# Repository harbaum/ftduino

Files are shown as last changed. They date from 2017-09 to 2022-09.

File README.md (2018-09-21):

# [ftDuino](http://ftduino.de): der [Arduino](http://arduino.cc) für [fischertechnik](http://fischertechnik.de)

<p align="center">
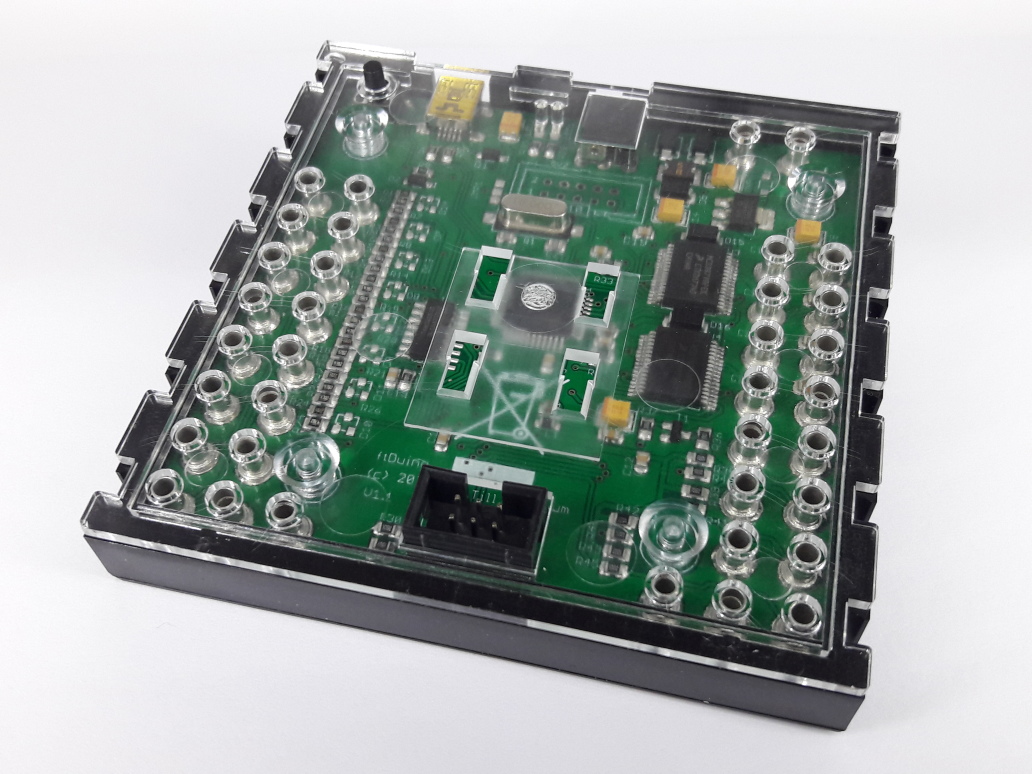
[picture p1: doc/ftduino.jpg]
  
</p>

Der ftDuino schlägt die Brücke zwischen den populären
[Arduino](http://arduino.cc)-Controllern und dem leistungsfähigen
[fischertechnik](http://fischertechnik.de)-Konstruktionsspielzeug.

Mehr Infos auf der [ftDuino-Homepage](http://ftduino.de).

<p align="center">
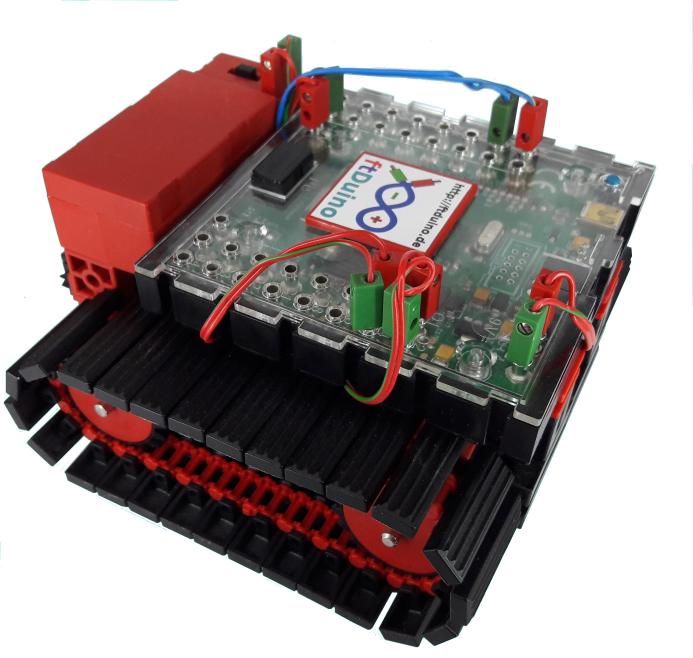
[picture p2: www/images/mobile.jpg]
  
</p>

The ftDuino bridges the gap between the popular [Arduino](http://arduino.cc)
controllers and the powerful [fischertechnik](http://fischertechnik.de)
construction toy.

More infos on the [ftDuino homepage](http://ftduino.de/en).

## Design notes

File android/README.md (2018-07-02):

ftDuino for Android
-------------------

The ftDuino can be connected directly to most android devices like
smartphones or tablets using a so-called USB on-the-go (USB OTG) cable.

The ftDuino setup for the Arduino IDE contains a demo sketch under
FtduinoSimple/USB/AndroidDemo which can be used in combination with
the ftDuinoDemo app.

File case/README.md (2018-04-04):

# ftDuino case designs

These are mesh files for the ftDuino 1.1 case. At least `bottom.stl` and
one of `top_with_isp.stl` or `top_without_isp.stl` are needed.

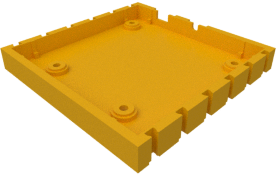
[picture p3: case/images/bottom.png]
bottom case
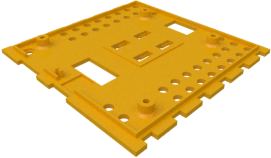
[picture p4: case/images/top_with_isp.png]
top case with ISP connector opening
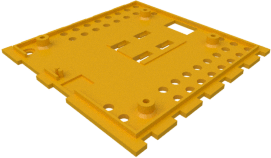
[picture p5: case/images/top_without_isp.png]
top case without ISP connector opening
|  |  |  |
|:---:|:---:|:---:|
| [View `bottom.stl`](bottom.stl) | [View `top_with_isp.stl`](top_with_isp.stl) | [View `top_without_isp.stl`](top_without_isp.stl) |
| [Download `bottom.stl`](bottom.stl?raw=true) | [Download `top_with_isp.stl`](top_with_isp.stl?raw=true) | [Download `top_without_isp.stl`](top_without_isp.stl?raw=true) |

The `top_with_isp.stl` is to be used if the ISP connector is to
be mounted. The `top_without_isp.stl` is for boards without ISP
connector. The ISP connector hole in `top_with_isp.stl` can alternally
be closed with the `isp_cap.stl`.

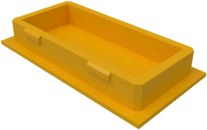
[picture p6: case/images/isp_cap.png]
ISP connector cap
|  |
|:---:|
| [View `isp_cap.stl`](isp_cap.stl) |
| [Download `isp_cap.stl`](isp_cap.stl?raw=true) |

The `i2c_protector.stl` is a small piece that fits into the 6 pin
I²C connector if it's not in use and prevents it from accidentially
being shortened or otherwise damaged.

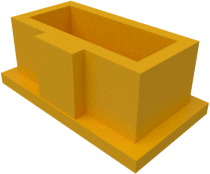
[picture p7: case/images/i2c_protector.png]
I²C protector
|  |
|:---:|
| [View `i2c_protector.stl`](i2c_protector.stl) |
| [Download `i2c_protector.stl`](i2c_protector.stl?raw=true) |

The `reset_button.stl` reset button is required if a 4.3mm tactile
switch is used as a reset button. It's not needed if a 7 or 9mm
version is used.

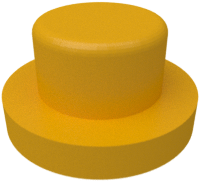
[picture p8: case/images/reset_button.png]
Reset button
|  |
|:---:|
| [View `reset_button.stl`](reset_button.stl) |
| [Download `reset_button.stl`](reset_button.stl?raw=true) |

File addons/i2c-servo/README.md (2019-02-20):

# Mini I²C servo controller

The 30mm version featuring a single I²C port:

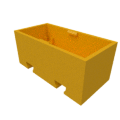
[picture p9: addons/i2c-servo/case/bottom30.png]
bottom case
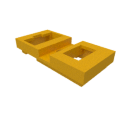
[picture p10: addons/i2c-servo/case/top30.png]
top case
|  |  |
|:---:|:---:|
| [`bottom30.stl`](case/bottom30.stl) | [`top30.stl`](case/top30.stl) |

The 45mm version featuring two I²C ports:

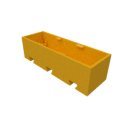
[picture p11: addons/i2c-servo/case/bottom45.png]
bottom case
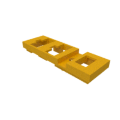
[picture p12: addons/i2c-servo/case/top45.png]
top case
|  |  |
|:---:|:---:|
| [`bottom45.stl`](case/bottom45.stl) | [`top45.stl`](case/top45.stl) |

# I²C-Registers

By default the adapter uses I²C address 0x11 (dec 17).

| Register | Description |
|---|---|
| 0x00/0x01 | Set servo pulse width of output 1 or 2 in 16us steps. E.g. 63 is 1ms (typical min value of a servo) and 125 is 2ms (typical max value of a servo). By default the adapter will not allow values < 53 and values > 125 to protect the servo. Example set PWM1 to 1.5ms: 0x11 0x00 0x5e |
| 0x02/0x03 | Set lower limit for servo 1 or servo 2 in 16us steps. Default value is 63. Values written to registers  0x00/0x01 lower than the limits specified here are mapped to this limit. |
| 0x04/0x05 | Set upper limit for servo 1 or servo 2 in 16us steps. Default value is 125. Values written to registers  0x00/0x01 higher than the limits specified here are mapped to this limit. |
| 0x06/0x07 | Set offset for servo 1 or servo 2. Default value is 0. The offset is added to the PWM value written to registers 0 or 1 _after_ the limit takes place. This is useful to adjust the center position of a servo. |
| 0x08 | Set I²C address. The new address can be any address >= 0x03 and <= 0x77 except 0x3c (which is reserved because the OLED uses it). |
| 0x09 | Writing 0xa5 to this register stores the values from registers 0x02 to 0x08 in eeprom. These settings will then become permanent over power loss and reboot. |
| Read 0x00 | Reading register 0x00 returns the formware version in BCD, e.g. 0x10 for version 1.0 |
| Read 0x01+ | Reading any other register returns 0x5a |

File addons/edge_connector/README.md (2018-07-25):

# Edge connector

The ftDuino case unfortunately does not have ft mounts at
its bottom. This is due to the fact that this would make
moulding much more expensive.

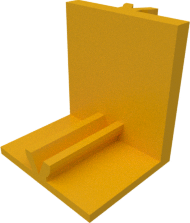
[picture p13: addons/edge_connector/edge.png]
Edge connector
|  |
|:---:|
| [View `edge.stl`](edge.stl) |
| [Download `edge.stl`](edge.stl?raw=true) |

The edge connector was therefore built to allow to get some
sore of bottom connectivity as depicted below.

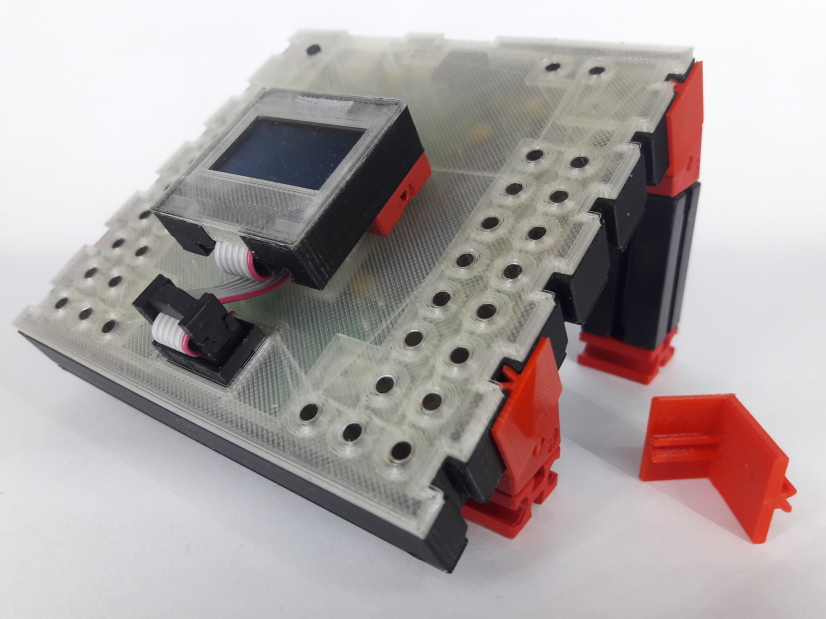
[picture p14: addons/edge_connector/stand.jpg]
A stand using the edge connector


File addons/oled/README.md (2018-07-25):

# ftDuino - OLED addon

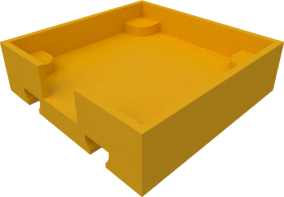
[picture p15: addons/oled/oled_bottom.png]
bottom case
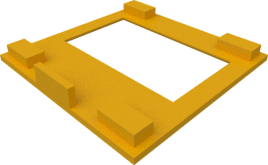
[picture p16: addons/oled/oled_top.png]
top case
|  |  |
|:---:|:---:|
| [View `oled_bottom.stl`](oled_bottom.stl) | [View `oled_top.stl`](oled_top.stl) |
| [Download `oled_bottom.stl`](oled_bottom.stl?raw=true) | [Download `oled_top.stl`](oled_top.stl?raw=true) |

The ftDuinos I²C interface can be used to add a small OLED display
to the ftDuino.

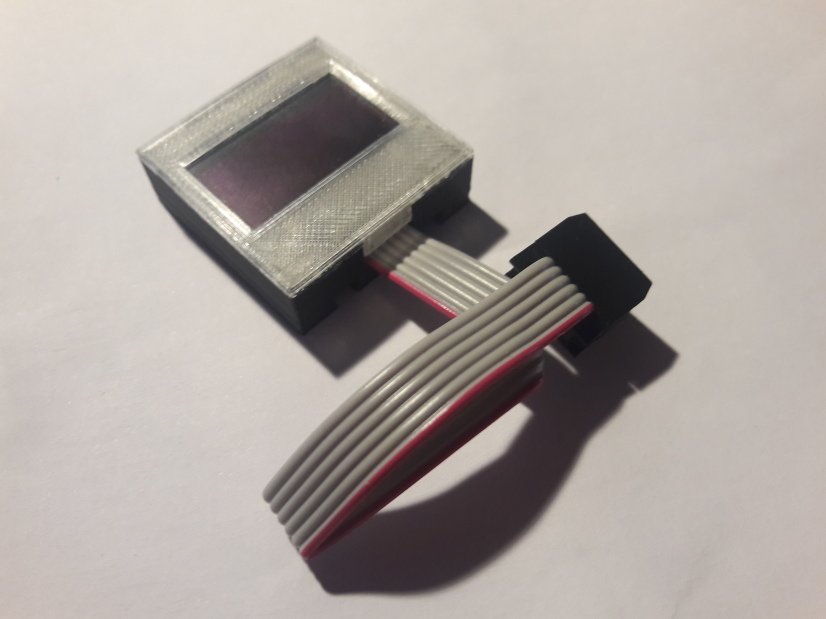
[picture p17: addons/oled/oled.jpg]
The cased OLED display with matching cable for the ftDuino


Here you'll find a set of design files for a fischertechnik compatible
case for a typical 0.96" OLED display,

The wiring compatible with the 6 pin I²C connector of the ftDuino
is rather simple:

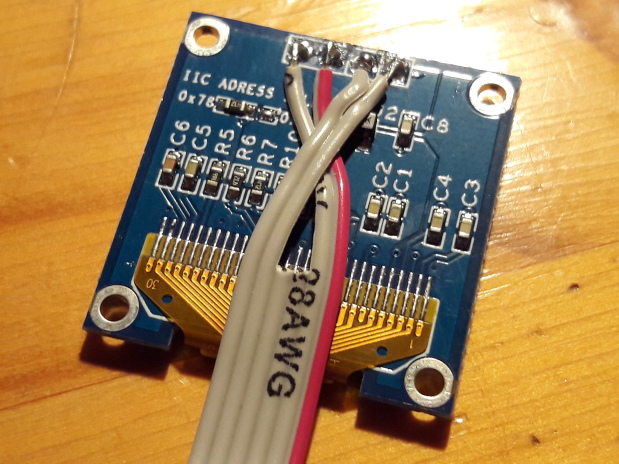
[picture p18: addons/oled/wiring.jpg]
Wiring the ftDuino cable


A matching arduino library can e.g. found in the [Adafruit repository](https://github.com/adafruit/Adafruit_SSD1306).

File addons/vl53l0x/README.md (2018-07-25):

# ftDuino - vl53l0x addon

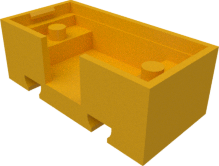
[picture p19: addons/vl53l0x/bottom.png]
bottom case
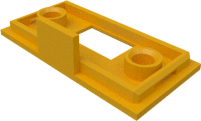
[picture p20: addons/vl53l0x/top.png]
top case
|  |  |
|:---:|:---:|
| [View `bottom.stl`](bottom.stl) | [View `top.stl`](top.stl) |
| [Download `bottom.stl`](bottom.stl?raw=true) | [Download `top.stl`](top.stl?raw=true) |

The vl53l0x is a time of flight (ToF) distance sensor. It can e.g. be
used as a replacement for the fischertechnik ultrasonic distance
sensor.

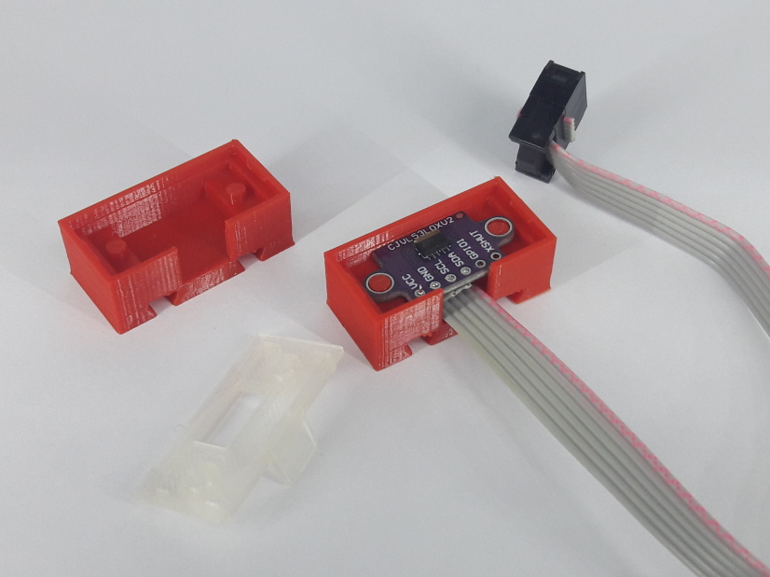
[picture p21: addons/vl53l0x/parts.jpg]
All needed parts


A matching arduino library can e.g. found in the [Adafruit repository](https://github.com/adafruit/Adafruit_VL53L0X).

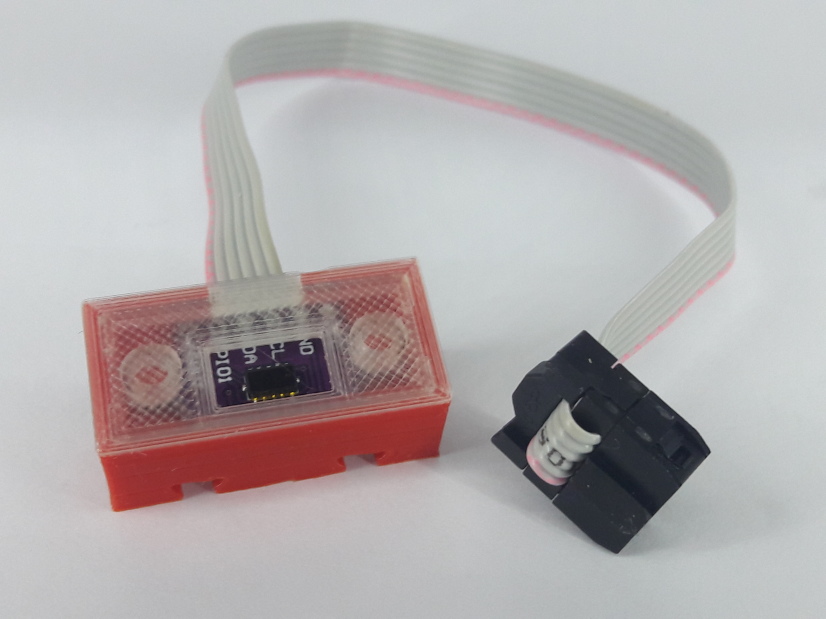
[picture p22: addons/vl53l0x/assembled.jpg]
Assembled sensor


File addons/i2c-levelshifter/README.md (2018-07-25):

# I²C level shifter

This is a case for the I²C level shifter.

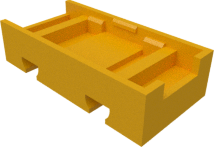
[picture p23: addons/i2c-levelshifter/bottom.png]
bottom case
|  | top case |
|:---:|:---:|
| [View `bottom.stl`](bottom.stl) | [View `top.stl`](top.stl) |
| [Download `bottom.stl`](bottom.stl?raw=true) | [Download `top.stl`](top.stl?raw=true) |

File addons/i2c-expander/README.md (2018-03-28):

# I²C expander

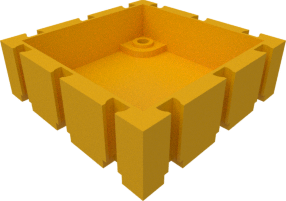
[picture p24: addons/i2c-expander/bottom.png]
bottom case
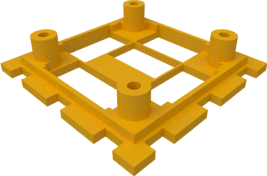
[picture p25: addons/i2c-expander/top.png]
top case
|  |  |
|:---:|:---:|
| [`bottom.stl`](bottom.stl) | [`top.stl`](top.stl) |

The I²C expander expands the single 5V I²C port of a ftDuino or
fischertechnik TX controller by three more ports and contains a level
shifter to bridge to a fischertechnik TXT compatible 3.3V port.

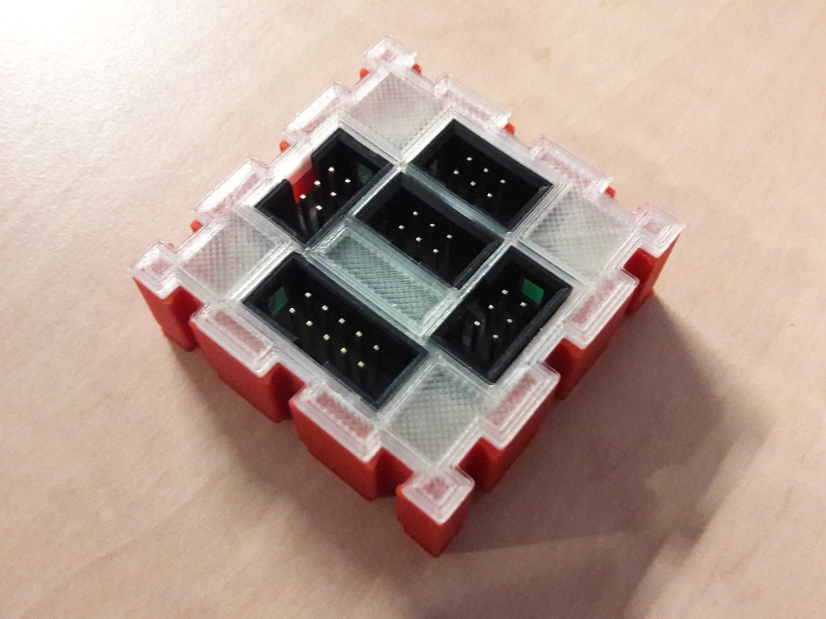
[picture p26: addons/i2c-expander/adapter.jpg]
adapter


This adapter can e.g. be used to connect the ```fischertechnik 
Kombisensor 158402 3-in-1 Orientierungssensor``` ([PDF](https://content.ugfischer.com/cbfiles/fischer/Zulassungen/ft/158402-Kombisensor-Kurzanleitung-BMX055-2017-06-09.pdf)) which is meant to be connected to the TXT and its 3.3V
I²C:

adapter between ftduino and ft sensor

This is how the setup looks right before assembly:

disassembled

## Parts

All parts are available from e.g. [Reichelt](http://www.reichelt.de).

You need:

  - 1x 10 pin header [WSL 10G](https://www.reichelt.de/Pfosten-Wannenstecker/WSL-10G/3/index.html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)
  - 4x 6 pin header [WSL 6G](https://www.reichelt.de/Pfosten-Wannenstecker/WSL-6G/3/index.html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)
  - 2x resistors [22k ohms SMD](https://www.reichelt.de/SMD-0805-von-1-bis-910-kOhm/SMD-0805-22-0K/3/index.html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)
  - 2x N channel MOSFET [BSS 123](https://www.reichelt.de/BS-Transistoren/BSS-123-SMD/3/index.html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)
  - 1x power regulator [TPS 77033 DBVT](https://www.reichelt.de/ICs-TLC-TSA-/TPS-77033-DBVT/3/index.html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)

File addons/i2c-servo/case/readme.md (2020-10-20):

Für die im Handel erhältliche Platinenversion mit durchgeschleiftem I2C-Bus sind die langen ...45-Gehäuse zu verwenden.

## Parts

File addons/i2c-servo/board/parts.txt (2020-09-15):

Part name                Description            Digikey No
------------------------------------------------------------------
IC1                      TS2940CP50             TS2940CP50ROG-ND      
IC2                      Attiny25 SOIC8         ATTINY25-20SSU-ND 
R1                       220 0805               CR0805-JW-221ELFTR-ND, any < 5% 0805 220R resistor
R2,R3                    10k 0805               311-10KARTR-ND, any < 5% 0805 10k resistor
C1,C2                    100nF 0805             399-7367-2-ND, any ceramic 100nF >=10V 0805 will do
LED                      green 0805             475-1410-2-ND, any cheap 0805 led will do
I²C1, I²C2, SERVO        6 pin 2.54mm SMD pin   54202-S0803LF-ND or similar regular 2.54mm 6 pin smd 
I1                       metal sleeve           fischertechnik sleeve as on ftDuino itself

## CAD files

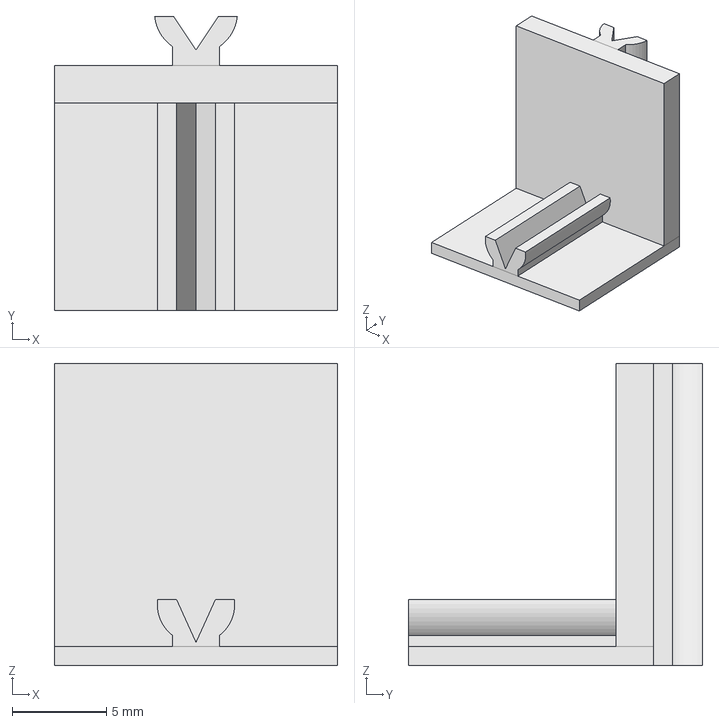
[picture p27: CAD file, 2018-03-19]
addons/edge_connector/edge.fcstd
15.0 x 15.6 x 16.0 mm

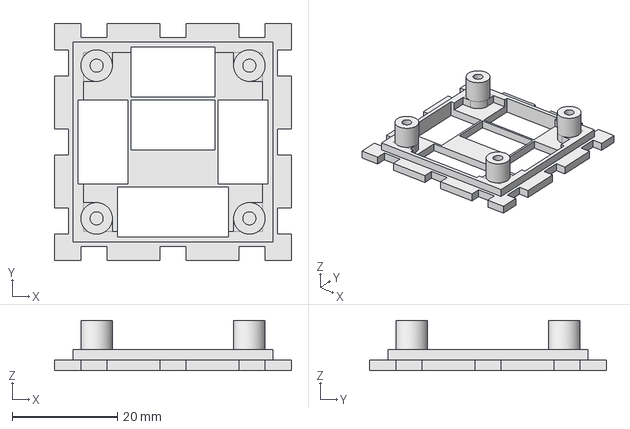
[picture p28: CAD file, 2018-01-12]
addons/i2c-expander/top.fcstd
45.0 x 45.0 x 9.50 mm

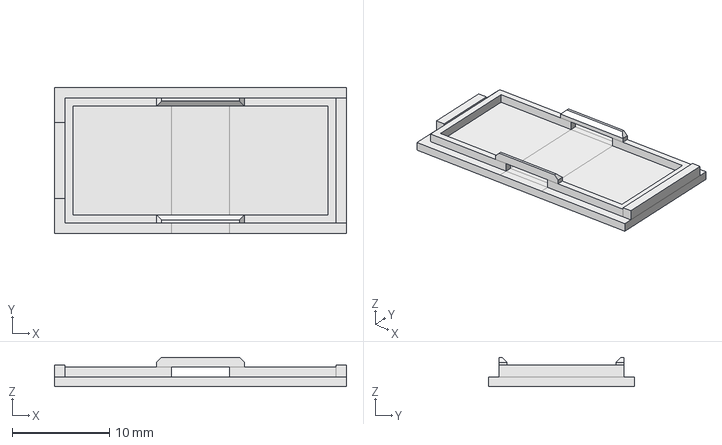
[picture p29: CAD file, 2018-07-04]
addons/i2c-levelshifter/top.fcstd
30.0 x 15.0 x 3.00 mm

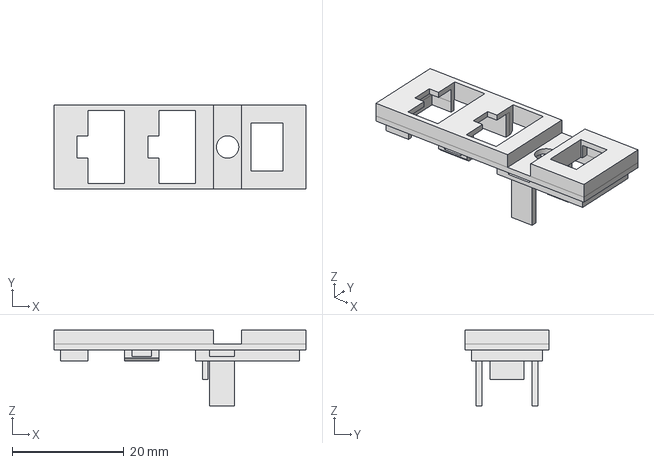
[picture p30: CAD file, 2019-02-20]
addons/i2c-servo/case/top45.fcstd
45.0 x 15.0 x 13.5 mm

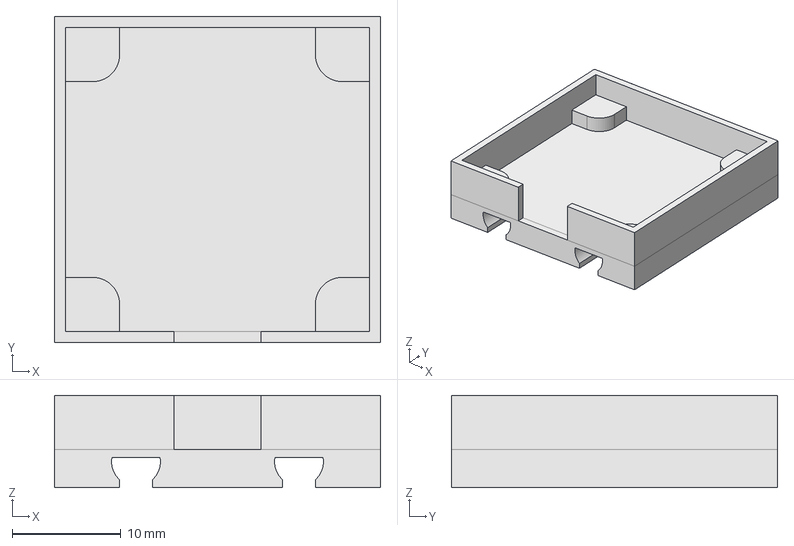
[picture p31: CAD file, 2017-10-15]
addons/oled/oled_bottom.fcstd
30.0 x 30.0 x 8.50 mm

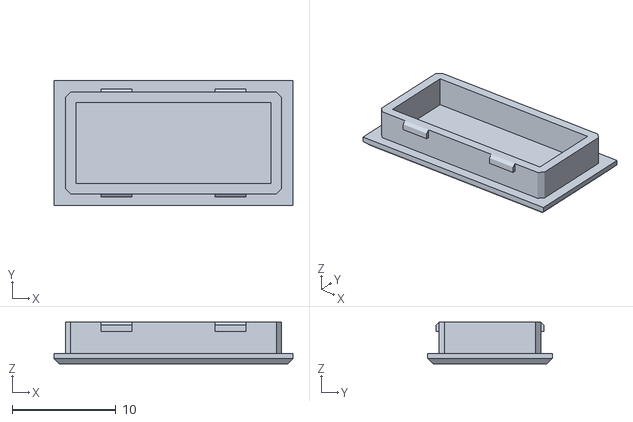
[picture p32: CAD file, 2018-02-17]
case/isp_cap.stl
23.0 x 12.0 x 4.00

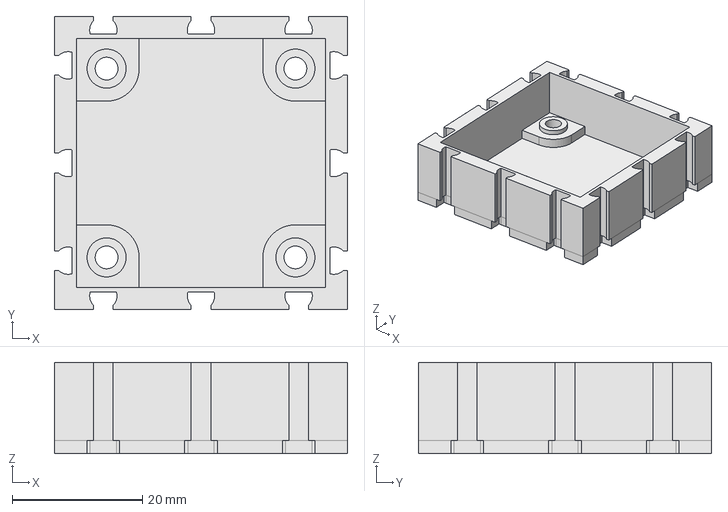
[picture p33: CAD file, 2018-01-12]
addons/i2c-expander/bottom.fcstd
45.0 x 45.0 x 14.0 mm

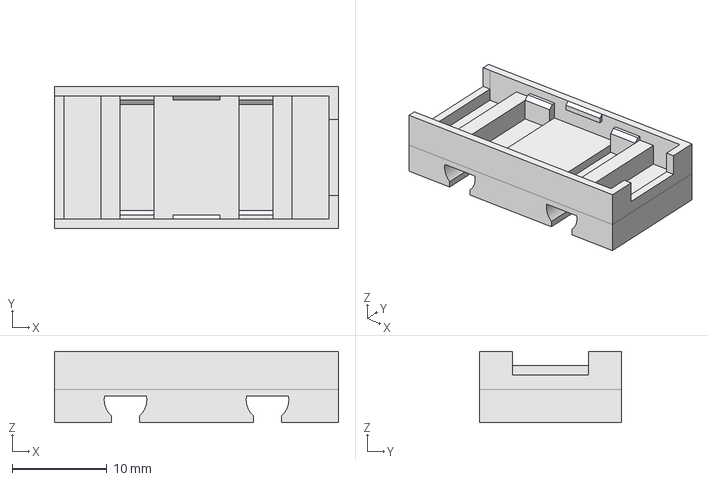
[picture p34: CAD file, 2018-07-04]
addons/i2c-levelshifter/bottom.fcstd
30.0 x 15.0 x 7.50 mm

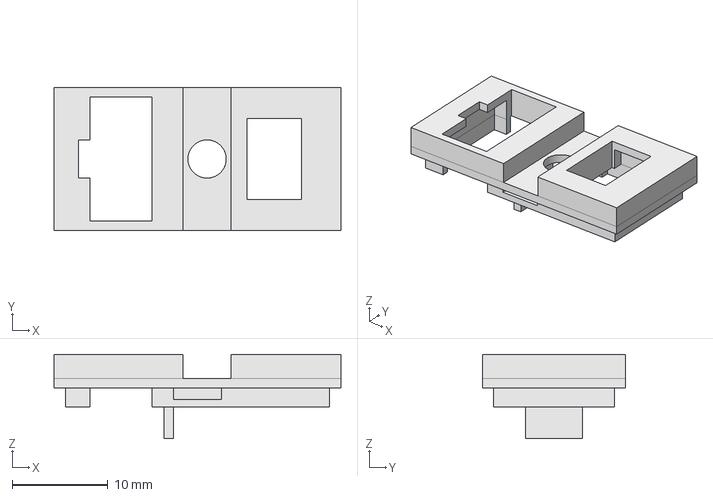
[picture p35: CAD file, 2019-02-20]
addons/i2c-servo/case/top30.fcstd
30.0 x 15.0 x 8.80 mm

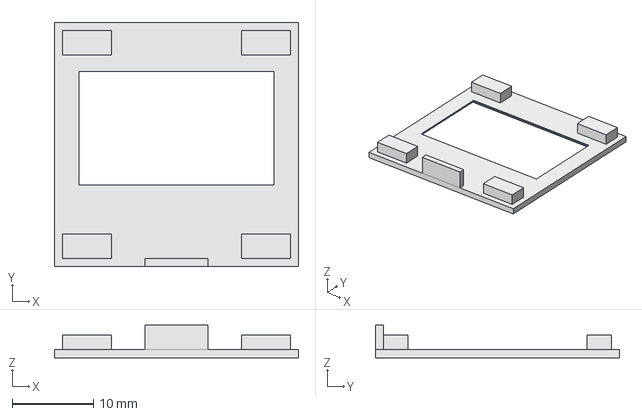
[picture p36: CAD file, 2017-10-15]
addons/oled/oled_top.fcstd
30.0 x 30.0 x 4.00 mm

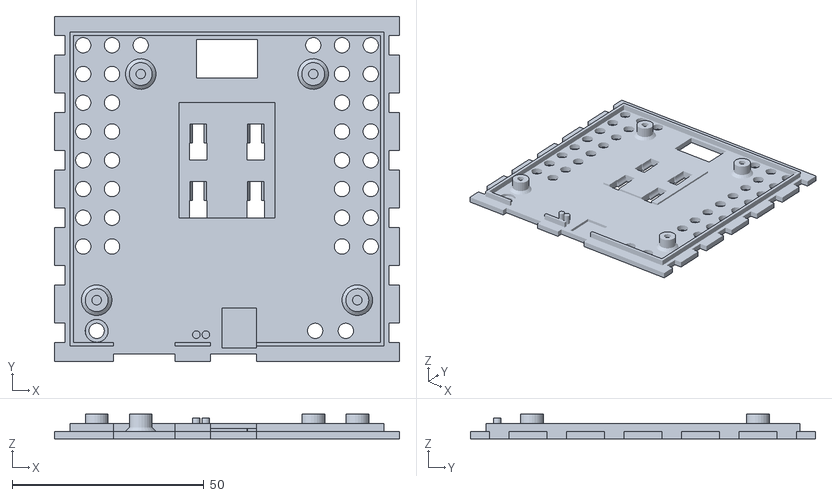
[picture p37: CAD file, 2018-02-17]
case/top_without_isp.stl
90.0 x 90.0 x 6.50

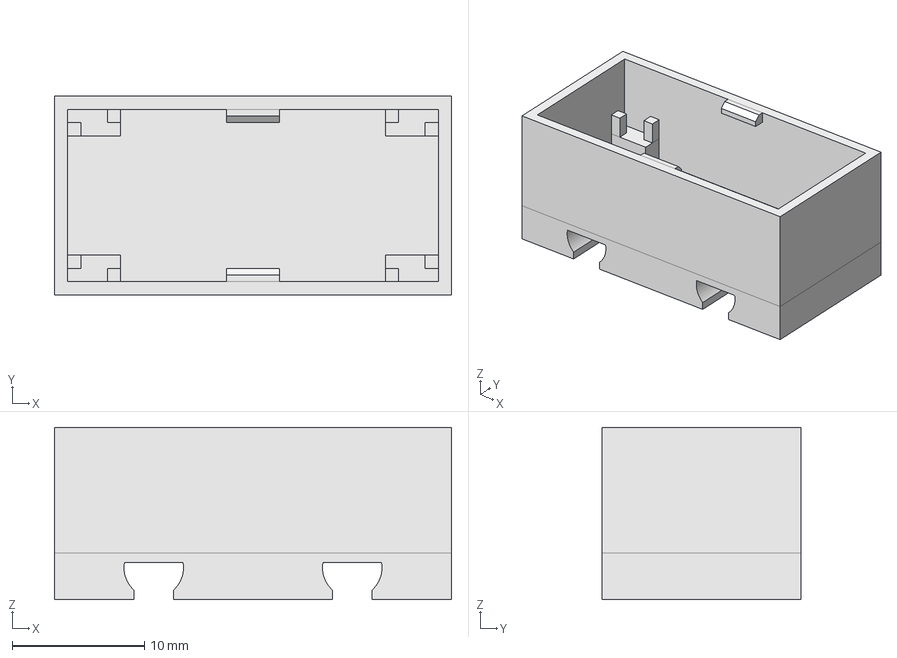
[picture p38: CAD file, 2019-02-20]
addons/i2c-servo/case/bottom30.fcstd
30.0 x 15.0 x 13.0 mm

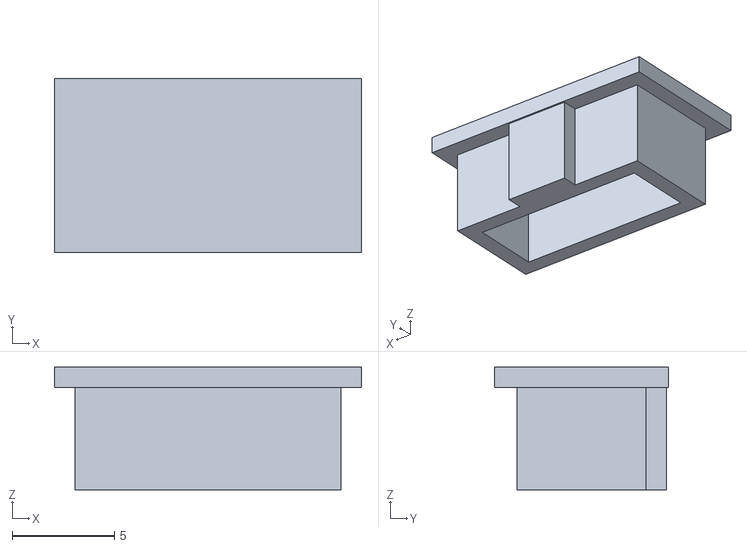
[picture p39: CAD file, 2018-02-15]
case/i2c_protector.stl
15.0 x 8.50 x 6.00

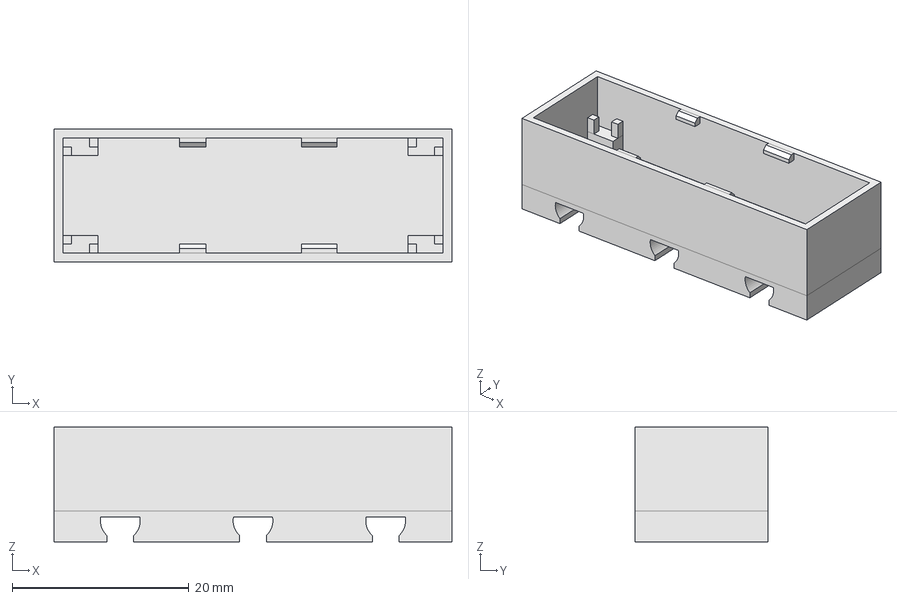
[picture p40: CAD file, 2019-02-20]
addons/i2c-servo/case/bottom45.fcstd
45.0 x 15.0 x 13.0 mm

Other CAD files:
case/reset_button.stl
case/bottom.stl
case/top_with_isp.stl
addons/vl53l0x/bottom.fcstd
addons/edge_connector/edge.stl
addons/i2c-expander/bottom.stl
addons/i2c-expander/top.stl
addons/i2c-levelshifter/bottom.stl
addons/i2c-levelshifter/top.stl
addons/i2c-servo/case/bottom30.stl
addons/i2c-servo/case/bottom45.stl
addons/i2c-servo/case/top30.stl
addons/i2c-servo/case/top45.stl
addons/oled/oled_bottom.stl
addons/oled/oled_top.stl
addons/vl53l0x/bottom.stl
addons/vl53l0x/top.fcstd
addons/vl53l0x/top.stl

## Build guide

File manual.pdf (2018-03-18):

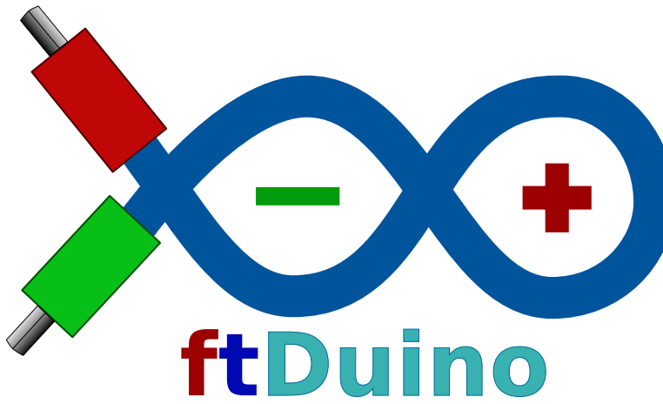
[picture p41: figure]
ftDuino

# ein fischertechnik-kompatibler Arduino

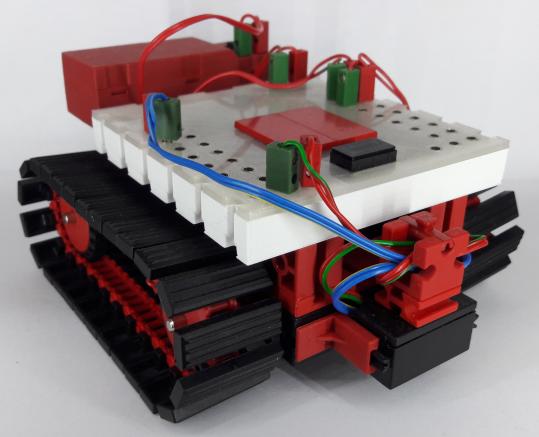
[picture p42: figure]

# Bedienungsanleitung

Dr.-Ing. Till Harbaum

16. März 2018

Fur Tanja, Maya, Fabian und Ida ¨

© 2017 Dr.-Ing. Till Harbaum <till@harbaum.org>

Projekt-Homepage: http://ftduino.de
Kontakt: mailto://info@ftduino.de
Forum: https://forum.ftcommunity.de/

# Inhaltsverzeichnis

1 Einleitung | 6
1.2.5 | Anschlusse | ¨ | 10
2 Installation | 14
3 Erste Schritte | 20
4 Experimente | 27

4 | Inhaltsverzeichnis
4.4.3 | Ein Eingang als Ausgang | | 37
4.5 Ausgänge an, aus oder nichts davon? | | 38
4.5.1 | Sketch OnOffTristate (https://github.com/harbaum/ftduino/tree/master/ftduino/libraries/FtduinoSimple/examples/OnOffTristate) | | 39
4.5.2 | Leckströme | | 39
4.6 Aktive Motorbremse | | 39
4.7 USB-Tastatur | | 41
4.7.1 | Sketch USB/KeyboardMessage (https://github.com/harbaum/ftduino/tree/master/ftduino/libraries/FtduinoSimple/examples/USB/KeyboardMessage) | | 41
4.8 USB-GamePad | | 43
4.8.1 | Sketch USB/GamePad (https://github.com/harbaum/ftduino/tree/master/ftduino/libraries/FtduinoSimple/examples/USB/GamePad) | | 43
4.9 Entprellen | | 44
4.9.1 | Sketch Debounce (https://github.com/harbaum/ftduino/tree/master/ftduino/libraries/FtduinoSimple/examples/Debounce) | | 44
4.10 Nutzung des I²C-Bus | | 47
4.10.1 Sketch I2C/I2cScanner (https://github.com/harbaum/ftduino/tree/master/ftduino/libraries/FtduinoSimple/examples/I2C/I2cScanner) | | 48
4.10.2 MPU-6050-Sensor | | 49
4.10.3 OLED-Display | | 49
4.10.4 ftDuino als I²C-Client und Kopplung zweier ftDuinos | | 50
4.11 WS2812B-Vollfarb-Leuchtdioden | | 53
4.11.1 Sketch WS2812FX | | 53
4.12 Musik aus dem ftDuino | | 54
4.12.1 Sketch Music (https://github.com/harbaum/ftduino/tree/master/ftduino/libraries/FtduinoSimple/examples/Music) | | 55
4.13 Der ftDuino als MIDI-Instrument | | 55
4.13.1 Sketch MidiInstrument (https://github.com/harbaum/ftduino/tree/master/ftduino/libraries/FtduinoSimple/examples/MidiInstrument) | | 55
5 Modelle | | 56
5.1 Automation Robots: Hochregallager | | 56
5.2 ElectroPneumatic: Flipper | | 57
5.3 ROBOTICS TXT Explorer: Linienfolger | | 58
6 Community-Projekte | 60
6.1 ftduino direct: ftDuino-Anbindung per USB | | 60
6.2 ftduinIO: ftDuino-Kontroll-App | | 61
6.3 Brickly-Plugin: Grafische ftDuino-Programmierung in Brickly | | 62
7 Bibliotheken | 64
7.1 FtduinoSimple | | 65
7.1.1 | Verwendung im Sketch | | 65
7.1.2 | bool input get(uint8 t ch) | | 66
7.1.3 | bool counter get state(uint8 t ch) | | 66
7.1.4 | void output set(uint8 t port, uint8 t mode) | | 66
7.1.5 | void motor set(uint8 t port, uint8 t mode) | | 67
7.1.6 | Beispiel-Sketches | | 67
7.2 Ftduino | | 67
7.2.1 | Die Eingänge I1 bis I8 | | 67
7.2.2 | void input set mode(uint8 t ch, uint8 t mode) | | 68
7.2.3 | uint16 t input get(uint8 t ch) | | 68
7.2.4 | Die Ausgänge O1 bis O8 und M1 bis M4 | | 68
7.2.5 | void output set(uint8 t port, uint8 t mode, uint8 t pwm) | | 69
7.2.6 | void motor set(uint8 t port, uint8 t mode, uint8 t pwm) | | 69
7.2.7 | void motor counter(uint8 t port, uint8 t mode, uint8 t pwm, uint16 t counter) . . | 70
7.2.8 | bool motor counter active(uint8 t port) | | 70
7.2.9 | void motor counter set brake(uint8 t port, bool on) | | 70
7.2.10 Die Zählereingänge C1 bis C4 | | 71
7.2.11 void counter set mode(uint8 t ch, uint8 t mode) | | 71
7.2.12 uint16 t counter get(uint8 t ch) | | 71
7.2.13 void counter clear(uint8 t ch) | | 71
7.2.14 bool counter get state(uint8 t ch) | | 72
7.2.15 void ultrasonic enable(bool ena) | | 72
7.2.16 int16 t ultrasonic get() | | 72

Inhaltsverzeichnis | 5
8 Selbstbau | | 73
8.1 Erste Baustufe ”
| Spannungsversorgung“ | | 73
8.1.1 | Bauteile-Polarität | | 74
8.1.2 | Kontroll-Messungen | | 74
8.2 Zweite Baustufe ”
| Mikrocontroller“ | | 75
8.2.1 | Funktionstest des Mikrocontrollers | | 75
8.3 Dritte Baustufe ”
| Eingänge“ | | 76
8.4 Vierte Baustufe ”
| Ausgänge“ | | 77
A Schaltplan | | 78
B Platinenlayout | 79
C Bestuckungsplan ¨ | | 80
D Maße | | 81
E Gehäuse | | 82

# Kapitel 1

# Einleitung

Elektronik- und Computermodule fur Konstruktionsbauk ¨ | | ästen gibt es seit den Anfängen der privat genutzten Heimcomputer
der 80er Jahre. Diese Module verfugten ¨ | uber wenig eigene Intelligenz und waren vor allem f ¨ | ur die Signalanpassung zwischen ¨
dem Heimcomputer und den Motoren und Schaltern der Baukastensysteme zuständig, weshalb diese Module in der Regel als “Interfaces” bezeichnet wurden, also als Schnittstelle zwischen Computer und Modell.
Uber die Jahre stieg die Leistungsf ¨ | ähigkeit der Heimcomputer und auch die Elektronik-Module lernten dazu. Vor allem wurden
aus “Interfaces” uber die Zeit “Controller”. Aus den weitgehend passiven Schnittstellen wurden Bausteine mit eigener ¨ Intelligenz, die den Heimcomputer bzw. später den PC nur noch zur Programmierung benötigten. Einmal programmiert konnten diese Controller das Modell auch eigenständig bedienen. Dazu wurden die auf dem PC entwickelten Programmdaten auf den Conroller geladen und dort gespeichert.

Die heutigen Controller von Lego oder fischertechnik sind selbst leistungsfähige Computer. Um deren Komplexität fur den ¨ Endanwender benutzbar zu machen verbergen die Hersteller die Details der elektronischen Komponenten sowie der auf den Geräten laufenden Software hinter gefälligen Benutzeroberflächen. Leider verpassen solche Systeme auf diese Weise die
Chance, Wissen uber Aufbau und Funktion derartiger Controller zu vermitteln. W ¨ | | ährend sich die Hersteller gegenseitig darin
ubertreffen, komplexe mechanische Getriebe im Wortsinne begreifbar zu machen stellen sich die dazugeh ¨ | örigen Controller
fur den Anwender als undurchsichtige Bausteine dar. ¨

Parallel hat sich seit der Jahrtausendwende die sogenannte Maker-Bewegung entwickelt, die den “Selbstmach”-Gedanken in den Bereich der Elektronikentwicklung trägt. Systeme wie der Raspberry-Pi und der Arduino laden dazu ein, alle technischen Details dieser komplett zugänglichen und dokumentierten Controller zu erforschen und eigene Entwicklungen zu betreiben. Große Communities bieten umfangreiches Know-How und stellen Plattformen zum Wissensaustausch zur Verfugung. Im ¨ Gegensatz zu den Controllern von fischertechnik und Lego steht hier das Innere des Controllers im Vordergrund. Allerdings erfordert der Einsatz dieser Controller oft einges an handwerklichem Geschick beim Aufbau der Elektronik selbst sowie speziell bei Robotik-Projekten bei der Umsetzung von mechanischen Komponenten.

## 1.1 Das ftDuino-Konzept

Die Idee hinter dem ftDuino ist es, die Brucke zwischen zwei Welten zu schlagen. Auf der einen Seite integriert er sich ¨ mechanisch und elektrisch nahtlos in die Robotics-Serie der fischertechnik-Konstruktionsbaukästen. Auf der anderen Seite
fugt er sich perfekt in das Arduino- ¨ | Okosystem zur Software-Entwicklung von eingebetteten Systemen ein. ¨

### 1.1.1 Das fischertechnik-Baukastensystem

Fischertechnik ist ein technikorientertes Konstruktionsspielzeug. Der Schwerpunkt liegt auf Mechanik, Elektromechanik, Elektronik und zunehmend auch Robotik und der dafur n ¨ ötigen Integration von informationsverarbeitenden Komponenten.

Fischertechnik selbst entwickelt und vertreibt seit den fruhen 80er Jahren Elektronik-Module, die eine Verbindung zwischen ¨
Computer und mechanischem Modell ermöglichen bzw. uber eigene Intelligenz verf ¨ | ugen. Die dabei zum Einsatz kommenden ¨
Steckverbinder sowie die Sensoren (Taster, Schalter, Lichtsensoren, . . . ) und Aktoren (Lampen, Motoren, Ventile, . . . ) sind uber die Jahre zueinander kompatibel geblieben und lassen sich nach wie vor beliebig miteinander kombinieren. ¨

1.1. Das ftDuino-Konzept | 7

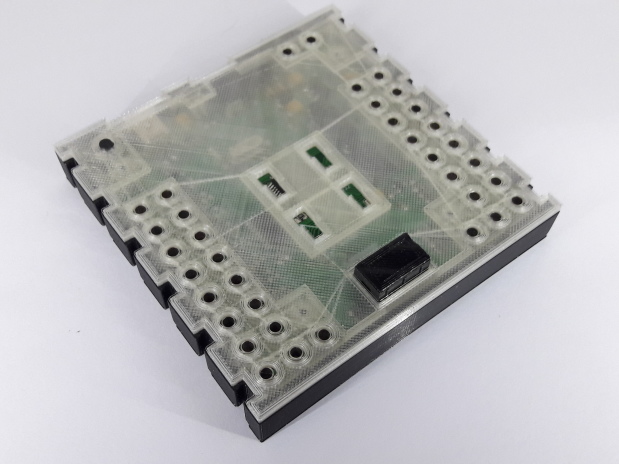
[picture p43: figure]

Abbildung 1.1: Der ftDuino im 3D-gedruckten Gehäuseprototyp

Die letzten zwei Controller-Generationen (fischertechnik TX- und TXT-Controller) haben eine vergleichbare mechanische
Größe und verfugen ¨ | uber eine vergleichbare Anzahl und Art von Anschl ¨ | ussen zur Verbindung mit dem Modell. Die Modelle ¨
aller aktuellen Robotics-Baukästen sind auf diese Anschlusse ausgelegt und untereinander kombinierbar. ¨

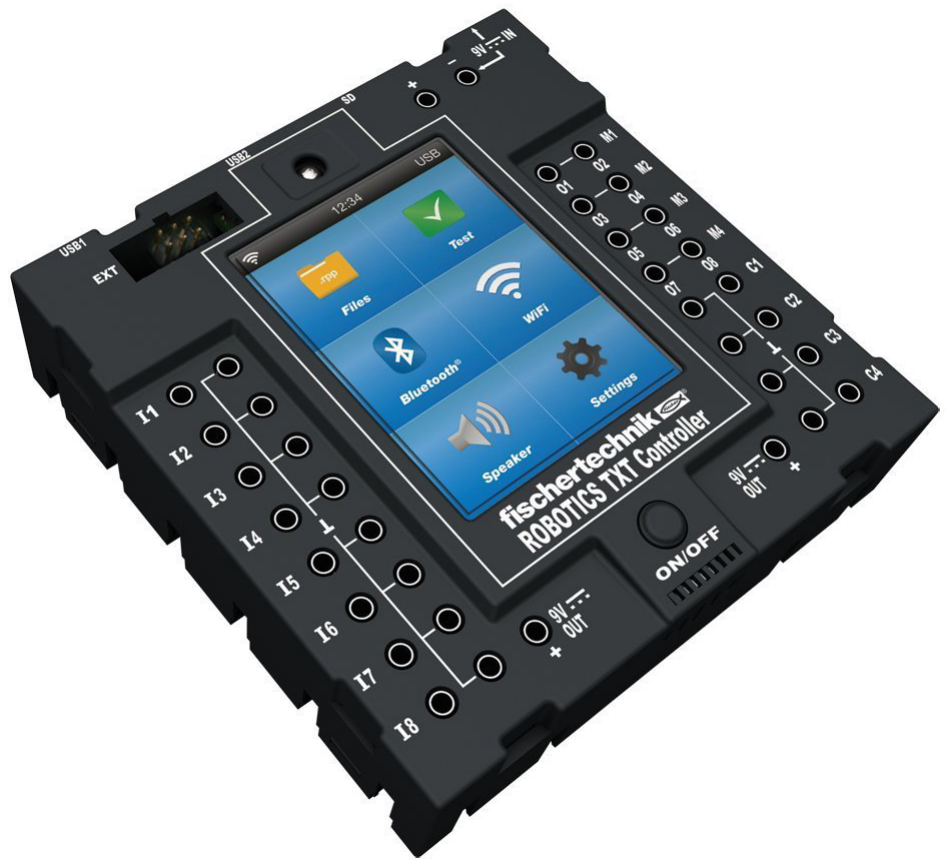
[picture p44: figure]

(a) TX-Controller | (b) TXT-Controller

Abbildung 1.2: Original-Controller von fischertechnik

Beide Original-Controller verfugen ¨ | uber acht analoge Eing ¨ | änge, acht analoge Ausgänge, vier schnelle Zählereingänge und
einen I²C-Erweiterungsanschluss.

Fischertechnik selbst vertreibt die PC-Software RoboPro zur visuellen Softwareentwicklung fur die hauseigenen Controller. ¨ Der Einstieg in RoboPro ist relativ einfach und spricht bereits Kinder an. Die Grenzen von RoboPro sind aber schnell
erreicht, wenn es um praxisnahe und inhaltlich anspruchsvolle Projekte in weiterfuhrenden Schulen, Universit ¨ | äten und der
Berufsausbildung geht. In diesen Bereichen haben sich Systeme wie die Arduino-Plattform etabliert.

### 1.1.2 Das Arduino-System

Das Arduino-Okosystem hat sich in den letzten Jahren zum De-Facto-Standard f ¨ | | ur den Einstieg und die semiprofessionelle ¨
Entwicklung und Programmierung von eingebetteten Systemen etabliert. Eingebettete Systeme sind in der Regel mecha-

8 | Kapitel 1. Einleitung

nisch kleine Computer und informationsverarbeitende Module, die innerhalb einer Maschine Steuer- und Regelaufgaben
ubernehmen und immer h ¨ | äufiger auch mit der Außenwelt kommunizieren.
(a) Arduino-Entwicklungsumgebung (IDE) | (b) Arduino-Leonardo-Controller

Abbildung 1.3: Die Arduino-Entwicklungsumgebung und -Controller

Die Arduino-IDE ist eine ubersichtliche und leicht zu bedienende Programmeroberfl ¨ | | äche, die sich auf Windows-, Linux-
und Apple-PCs nutzen lässt. Die zu programmierenden Zielgeräte wie zum Beispiel der Arduino-Leonardo sind kleine und
kostengunstige Platinen, die per USB mit dem PC verbunden werden. Sie kommen ¨ | ublicherweise ohne Geh ¨ | äuse und stellen
uber Steckverbinder eine Vielzahl von Signalleitungen zum Anschluss von Sensoren und Aktoren zur Verf ¨ | | ugung. Typische ¨
mit der Arduino-Plattform zu erledigende Aufgaben sind einfache Messwerterfassungen (Temperaturlogging, . . . ) und Steueraufgaben (Jalousiesteuerungen, . . . ).

Programme, die mit der Arduino-IDE geschrieben wurden, werden in der Arduino-Welt als sogenannte “Sketches” bezeichnet. Mit Hilfe der Arduino-IDE können passende Sketches fur den ¨ ftDuino geschrieben und uber das USB-Kabel direkt auf das ¨ Gerät hinutergeladen werden.

Auch fur einfache Robotik-Experimente ist die Arduino-Plattform bestens geeignet. Schwieriger ist oft eine mechanisch ¨ befriedigende Umsetzung selbst einfachster Robotik-Projekte. Diese Lucke kann das fischertechnik-System schließen. ¨

## 1.2 Der ftDuino-Controller

Der ftDuino-Controller wurde bewusst mechanisch und elektrisch an den TX- und den TXT-Controller angelehnt, um ihn ebenfalls direkt mit den aktuellen Robotics-Kästen kombinieren zu können. Gleichzeitig wurde er softwareseitig mit dem Arduino-System kompatibel gehalten.

### 1.2.1 Mikrocontroller

Das Herz des ftDuino ist ein Mikrocontroller des Typs ATmega32u4. Dieser Mikrocontroller wird von Microchip (ehemals
Atmel) hergestellt und findet auch im Arduino-Leonardo Verwendung. Sketches, die fur den Leonardo ¨ | ubersetzt wurden, ¨
sind oft direkt auf dem ftDuino lauffähig.

Der ATmega32u4-Controller ist ein Mitglied der sogenannten AVR-Famile, auf der die meisten Arduino-Boards basieren. Die
AVR-Controller sind klein, gunstig und ben ¨ | ötigen zum Betrieb nur wenig weitere Bauteile. Ihr Speicher und ihre Rechenleis-
tung reicht fur den Betrieb s ¨ | | ämtlicher fischertechnik-Modelle der Roboticsreihe deutlich aus.
Der ATmega32u4 verfugt ¨ | uber 32 Kilobytes nicht-fl ¨ | uchtigem Flash-Speicher, der als Sketch-Programmspeicher verwendet ¨
wird sowie 2,5 Kilobytes internem RAM-Speicher zur Datenspeicherung. Der Prozessortakt beträgt 16 Megahertz. Jeweils ein Sketch kann im Flash-Speicher permanent gespeichert werden und bleibt auch erhalten wenn der ftDuino von der Spannungsversorgung getrennt wird.

Der ATmega32u4 ist eines der wenigen Mitglieder der AVR-Familie, das direkte USB-Unterstutzung bereits auf dem Chip ¨ mitbringt. Auf diese Weise ist der ftDuino sehr flexibel als USB-Gerät am PC einsetzbar.

1.2. Der ftDuino-Controller | 9

## Analoge

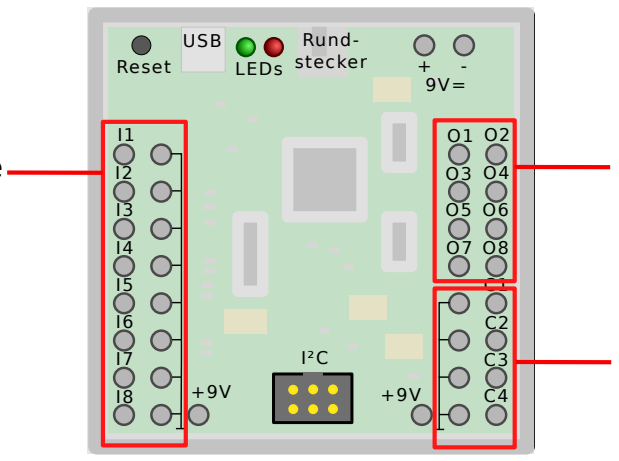
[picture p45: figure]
Reset; I²C; USB; Rund-; stecker LEDs

## Eingänge I1 bis I8

## Analoge Ausgänge O1 bis O8 (Motorausgänge M1 bis M4)

## Zählereingänge C1 bis C4

Abbildung 1.4: Die Anschlusse des ¨ | ftDuino

Bootloader

Der ftDuino wird mit einem im ATmega32u4 vorinstallierten sogenannten Caterina-Bootloader ausgeliefert. Dieses Programm belegt permanent vier der 32 Kilobytes Flash-Speicher des ATmega32u4 und kann nicht ohne weiteres gelöscht oder verändert werden.

Der Bootloader ermöglicht die Kommunikation mit dem PC und erlaubt es, dass der PC Programmdaten in den verliebenden 28 Kilobytes Flash-Speicher ablegen bzw. austauschen kann. Der Bootloader ermöglicht auf diese Weise das Hinunterladen von Sketches in den ftDuino.

Dass der Bootloader aktiv ist und nicht etwa gerade ein Sketch ausgefuhrt wird, ist am Zustand der internen LEDs erkennbar ¨ (siehe 1.2.3).

### 1.2.2 Reset-Taster

Normalerweise kann die Arduino-IDE durch entsprechende Kommandos uber den USB-Anschluss den Bootloader des ¨ | ftDuino
aktivieren, um einen neuen Sketch hinunterzuladen. Enthält ein hinuntergeladener Sketch aber Fehler, die eine normale
Programmausfuhrung verhindern, dann kann es passieren, dass die USB-Kommunikation w ¨ | ährend der normalen Program-
mausfuhrung nicht funktioniert und die Arduino-IDE den ¨ | | | ftDuino von sich aus nicht mehr ansprechen kann.
Fur diesen Fall verf ¨ | ugt der ¨ | ftDuino uber einen Reset-Taster. Wird dieser gedr ¨ | uckt, dann wird der Bootloader zwangsweise ¨
aktiviert und die LEDs zeigen entsprechend den Start des Bootloaders an.

Ein mit einem fehlerhaften Sketch versehener ftDuino kann daher problemlos mit einem korrigierten Sketch versehen werden, indem kurz vor dem Hinterladen der Reset-Taster kurz gedruckt wird. Mehr Details dazu finden sich im Abschnitt 1.3. ¨

### 1.2.3 Interne LEDs

Der ftDuino verfugt ¨ | uber je eine gr ¨ | une und rote interne Leuchtdiode (LED). Die gr ¨ | une Spannungsversorungs-LED zeigt an, ¨
dass der interne 5-Volt-Zweig mit Spannung versorgt ist und der Mikrocontroller des ftDuino versorgt wird.
Die rote LED steht fur eigene Verwendung zur Verf ¨ | ugung und kann vom Anwender aus eigenen Sketches heraus unter der ¨
Bezeichnug LED BUILTIN angespochen werden (siehe Abschnitt 3.1).

Die rote LED wird auch vom Caterina-Bootloader des ftDuino verwendet. Ist der Bootloader aktiv, so leuchtet die LED im Sekundentakt sanft heller und dunkler (“fading”).

10 | Kapitel 1. Einleitung

### 1.2.4 Spannungsversorgung

Der ftDuino kann auf vier Arten mit Spannung versorgt werden:

USB Uber USB wird der ¨ | ftDuino immer dann versorgt, wenn keine weitere Stromversorgung angeschlossen ist. Die USB-
Versorgung reicht allerdings nicht zum Betrieb der Analogausgänge. Lediglich die Eingänge können bei USB-Versorung verwendet werden. Zusätzlich ist die Genauigkeit einer Widerstandsmessung an den Analogeingängen deutlich herab gesetzt (siehe 1.2.5).

Rundstecker Wird der ftDuino per Rundstecker z.B. durch das Netzteil aus dem fischertechnik Power-Set 505283 mit 9 Volt versorgt, so wird der gesamte ftDuino daraus versorgt und der USB-Anschluss wird nicht belastet. Die Analogausgänge sind in diesem Fall benutzbar und die Widerstandsmessung an den Analogeingängen erfolgt mit voller Genauigkeit.

9V=-Eingang Eine Versorgung des ftDuino z.B. per Batterieset oder mit dem Akku aus dem Akku Set 34969 entspricht der Versorgung per Rundstecker. Wird der ftDuino sowohl uber den 9V=-Eingang als auch per Rundstecker versorgt, ¨ dann erfolgt die Versorgung aus der Quelle, die die höhere Spannung liefert. Eine Ruckspeisung in den Akku oder eine ¨ Ladung des Akkus findet nicht statt.

I

2C Uber den I ¨ | 2C-Anschluss versorgt der ftDuino in erster Linie andere angeschlossene Geräte wie kleine Displays oder
Sensoren. Es ist aber auch möglich, ihn selbst uber diesen Anschluss zu versorgen. Es bestehen dabei die gleichen ¨ Beschränkungen wie bei der Versorgung uber USB. Auf diese Weise ist zum Beispiel die Versorgung zweier gekoppelter ¨ ftDuinos aus einer einzigen Quelle möglich (siehe Abschnitt 4.10.4).

### 1.2.5 Anschlusse ¨

Die Anschlusse des ¨ | ftDuino teilen sich in die fischertechnik-kompatiblen Ein- und Ausgänge auf, die fur die ¨ | ublichen 2,6mm- ¨
Einzelstecker geeignet sind, sowie die ublichen Steckverbinder aus dem Computerbereich. Die fischertechnik-kompatiblen Ein- ¨
und Ausgänge sind identisch zum fischertechnik-TXT-Controller angeordnet. Verdrahtungsschemata fur den TXT k ¨ | önnen
daher in der Regel direkt ´ | ubernommen werden. ¨

Analoge Eingänge

Der ftDuino verfugt ¨ | uber acht analoge Eing ¨ | änge I1 bis I8, uber die Spannungen von 0 bis 10 Volt sowie Widerst ¨ | ände von
0 bis uber 10 Kiloohm erfasst werden k ¨ | | önnen.
Die Eingänge sind uber hochohmige Serienwiderst ¨ | ände gegen Kurzschlusse sowie ¨ | Uber- und Unterspannung abgesichert. ¨

Jeder Eingang ist mit einem eigenen Analogeingang des ATmega32u4-Mikrocontrollers verbunden. Die Analogwerterfassung kann mit bis zu 10 Bit Auflösung erfolgen (entsprechend einem Wertebereich 0 bis 1023) und wird direkt in der Hardware des Mikrocontrollers durchgefuhrt. ¨

Ein Spannungsteiler erweitert den Eingangsspannungsbereich des Mikrocontrollers von 0 bis 5 Volt auf den bei fischertechnik genutzten Bereich von 0 bis 10 Volt. Alle an fischertechnik-Modellen auftretenden Spannungen können damit erfasst werden.

Zur Widerstandsmessung kann kann jeder Eingang ftDuino-intern mit einem Widerstand gegen 5 Volt verschaltet werden. Dieser Widerstand wirkt mit einem externen Widerstand als Spannungsteiler und aus der am Mikrocontroller gemessenen Spannung kann der Wert des extern angechlossenen Widerstands gemessen werden. Alle von fischertechnik-Modellen
ublicherweise verwendeten Widerst ¨ | | ände können so erfasst werden.

Die analogen Eingänge sind nicht auf eine externe 9-Volt-Versorgung angewiesen, sondern funktionieren auch bei der Stromversorgung uber den USB-Anschluss des PC. Allerdings sinkt in diesem Fall die Genauigkeit der Widerstandsmessung signi- ¨ fikant.

Analoge Ausgänge

Der ftDuino verfugt ¨ | uber acht analoge Ausg ¨ | änge O1 bis O8. Diese Ausgänge werden uber zwei spezielle Treiberbausteine im ¨
ftDuino angesteuert. Die Treiberbausteine können jeden der acht Ausgänge unabhängig steuern. Sie sind identisch zu denen, die fischertechnik in den TX- und TXT-Controllern einsetzt. Die Ausgänge sind daher kompatibel zu allen fischertechnik-Motoren und -Aktoren, die auch am TX- und TXT-Controller betrieben werden können. Der maximal pro Ausgang verfugbare ¨ Strom beträgt 600mA bis 1,2A.

1.2. Der ftDuino-Controller | 11

Die Ausgänge sind bei einer reinen USB-Stromversorgung des ftDuino nicht verfugbar. ¨

Der verwendete Treiberbaustein MC33879 ist kurzschlussfest und robust gegen Uber- und Unterspannung an den Ausg ¨ | ängen.

Alle acht Ausgänge können unabhängig voneinander gegen Masse oder Eingangsspannung sowie hochohmig geschaltet werden. Je zwei Einzelausgänge können zu einem Motorausgang kombiniert werden. Die Einzelausgänge O1 und O2 bilden dabei den Motorausgang M1, O3 und O4 bilden M2 und so weiter.

Die Analogwerte an den Ausgängen werden durch eine sogenannte Pulsweitemodulation (PWM) erzeugt. Dabei werden die Ausgänge kontinuierlich schnell ein- und ausgeschaltet, so dass Motoren, Lampen und andere träge Verbraucher dem Signal nicht folgen können, sondern sich entsprechend des Mittelwerts verhalten. Dieses Verfahren wird in gleicher Weise auch im TX- und TXT-Controller angewendet.

Beide MC33879 werden vom Mikrocontroller des ftDuino intern uber dessen sogenannte SPI-Schnittstelle angeschlossen. Da ¨ dadurch die speziellen PWM-Ausgänge des Mikrocontrollers nicht zur Erzeugung der der Pulsweitenmodulation herangezogen werden können muss das PWM-Signal durch den Sketch bzw. die verwendeten Software-Bibliotheken (siehe Kapitel 7) selbst erzeugt werden. Die sogenannte PWM-Frequenz wird dabei durch den verwendeten Sketch bestimmt und kann beliebig variiert werden.

Mehr Informationen zum Thema PWM finden sich in Abschnitt 4.3.

Zählereingänge

Der ftDuino verfugt ¨ | uber vier spezielle Z ¨ | ählereingänge C1 bis C4. Diese Eingänge können rein digitale Signale erfassen und
mit hoher Geschwindigkeit Ereignisse auswerten. Die maximal erfassbare Signalrate liegt je nach Sketch bei mehreren 10.000 Ereignissen pro Sekunde.

Die Zählereingänge sind kompatibel zu den Encodern der fischertechnik-Encoder-Motoren und können unter anderem zur Drehwinkelauswertung sowie zur Drehzahlbestimmung herangezogen werden.

Zählereingang C1 verfugt zus ¨ | ätzlich uber die M ¨ | öglichkeit, einen fischertechnik ROBO TX Ultraschall-Distanzsensor 133009
auszuwerten.

Abbildung 1.5: Anschluss des Ultraschallsensors 133009

I

2C-Anschluss

Der I²C-Anschluss ist elektrisch und mechanisch zu dem des fischertechnik-TX-Controllers kompatibel. Der dort aus dem Gerät herausgefuhrte sogenannte I ¨

2C-Bus findet auch im Arduino-Umfeld häufige Verwendung und erlaubt den Anschluss passender Elektronikkomponenten wie Sensoren, Analog-Digital-Wandler, Displays und ähnlich. Außerdem ist uber den ¨ I

2C-Bus eine Kopplung mehrerer ftDuinos möglich sowie die Kopplung des ftDuino mit dem TX-Controller und dem TXT-Controller wie in Abschnitt 4.10 beschrieben.

Die Signale auf dem I²C-Anschluss nutzen wie am TX-Controller einen 5-Volt-Pegel. Zusätzlich werden aus der Spannungsversorgung des ftDuino 5 Volt zur Versorgung angeschlossener Komponenten bereitgestellt. Aus dem 5 Volt-Ausgang durfen ¨ max. 100mA entnommen werden, um die ftDuino-interne Spannungsversorung nicht zu uberlasten ¨

12 | Kapitel 1. Einleitung

Masse
+5V

SDA
SCL
Masse
SDA +5V

SCL

Abbildung 1.6: Buchsen- und Kabelbelegung des I²C-Bus am ftDuino

Achtung! Der fischertechnik-TXT-Controller sowie fur den Betrieb am TXT vorgesehene Komponenten sind aufgrund dessen ¨ 3,3 Volt-Signal-Pegel nicht direkt mit dem ftDuino kompatibel. Eine dirkete Verbindung zwischen TXT und ftDuino kann
den TXT beschädigen. Sollen der TXT oder fur den Betrieb am TXT vorgesehene Komponenten am ¨ | ftDuino verwendet
werden, so sind unbedingt passende I²C-Pegelanpassung zwischenzuschalten wie in Abschnitt 4.10.4 beschrieben.
Achtung! Die auf dem I²C-Anschluss liegenden Signale sind direkt und ungeschutzt mit dem Mikrocontroller des ¨ | ftDuino
bzw. mit dessen Spannungsversorgung verbunden. Werden an diesem Anschluss Kurzschlusse verursacht oder Spannungen ¨
uber 5V angelegt, dann kann der ¨ | ftDuino zerstört werden. Der I²C-Anschluss sollte daher nur von erfahrenen Anwendern
verwendet werden.

## 1.3 Problemlösungen

1.3.1 | Die grune Leuchtdiode im ¨ | ftDuino leuchtet nicht

Zunächst sollte der ftDuino von allen Verbindungen getrennt und ausschließlich uber den USB-Anschluss mit dem PC ¨
verbunden werden. Die grune Leuchtdiode im ¨ | ftDuino muss sofort aufleuchten. Tut sie das nicht, dann sollte ein anderer
PC bzw. ein anderer USB-Anschluss probiert werden.
Hilft das nicht, dann ist zunächst das USB-Kabel zu prufen. Funktionieren andere Ger ¨ | äte an diesem Kabel? Gegebenenfalls
muss das Kabel ausgetauscht werden.

### 1.3.2 Der ftDuino taucht am PC nicht als COM:-Port auf

Der ftDuino wird nicht mehr vom PC erkannt und es wird kein COM:-Port angelegt.

Leuchtet die grune Leuchtdiode am ¨ | ftDuino? Falls nicht sollte wie unter 1.3.1 verfahren werden.
Leuchtet die grune Leuchtdiode, dann sollte ein kurzer Druck auf den Reset-Taster (siehe 1.2.2) den Bootloader des ¨ | ftDuino
fur einige Sekunden aktivieren. Erkennbar ist dies am langsamen Ein- und Ausblenden der roten Leuchtdiode wie in Abschnitt ¨ 1.2.3 beschrieben. In dieser Zeit sollte der ftDuino vom PC erkannt werden. Dies wird u.a. unter Windows im Gerätemanager wie im Abschnitt 2.1.1 beschrieben angezeigt.

Wird der ftDuino nach einem Reset erkannt, aber verschwindet nach ein paar Sekunden aus der Ansicht des Gerätemanagers oder wird als unbekanntes Gerät angezeigt, dann wurde wahrscheinlich ein fehlerhafter Sketch auf den ftDuino geladen und die Arduino-IDE ist nicht in der Lage, sich eigenständig mit dem ftDuino zu verbinden. In diesem Fall sollte man das Blink-Beispiel (siehe Abschnitt 3.1) in der Arduino-IDE öffnen, den ftDuino per kurzem Druck auf den Reset-Taster in den Booloader-Modus versetzen und direkt danach die Download-Schaltfläche in der Arduino-IDE drucken. Sobald der ¨ funktionierende Sketch geladen wurde wird der ftDuino auch ohne manuelle Druck auf den Reset-Taster wieder von PC erkannt und der entsprechende COM:-Port taucht wieder auf.

Der ftDuino bleibt nur wenige Sekunden im Bootloader und kehrt danach in den normalen Sketch-Betrieb zuruck. Zwischen ¨ dem Druck auf den Reset-Knopf und dem Start des Downloads aus der Arduino-IDE sollte daher möglichst wenig Zeit vergehen.

1.3. Problemlösungen | 13

### 1.3.3 Der ftDuino funktioniert, aber die Ausgänge nicht

Um die Ausgänge zu benutzen muss der ftDuino mit einer 9-Volt-Spannunsgquelle entweder uber den Rundstecker-Anschluss ¨
oder uber die ¨ | ublichen fischertechnik-Stecker verbunden sein. Verf ¨ | ugt der ¨ | ftDuino uber keine ausreichende 9-Volt-Versorgung, ¨
so können die Ausgänge nicht betrieben werden. Da der ftDuino selbst schon mit geringerer Soannung läuft ist dessen Funktion kein sicheres Indiz dafur, dass eine ausreichende 9-Volt-Versorung vorhanden ist. ¨

Ist der ftDuino uber USB mit dem PC verbunden, dann versorgt er sich bei mangelhafter oder fehlender 9-Volt-Versorung ¨ von dort. Geht der ftDuino ganz aus, sobald man die USB-Verbindung trennt, dann ist keine 9-Volt-Versorgung gegeben und es muss sichergestellt werden, dass Polarität und Spannung korrekt bzw. ausreichend sind. Ggf. muss die Batterie ausgetauscht oder der verwendete Akku geladen werden.

# Kapitel 2

# Installation

Die Installation der Software zur Benutzung des ftDuino erfolgt in mehreren Schritten. Zu allererst muss der Computer mit
dem ftDuino bekannt gemacht werden, in dem ein passender Treiber dafur sorgt, dass der Computer erf ¨ | ährt wie er mit dem
ftDuino zu kommunizieren hat.

Im zweiten Schritt wird dann die sogenannte Arduino-IDE installiert, also die eigentliche Programmierumgebung sowie die Arduino-IDE mit dem ftDuino verbunden.

Fur die Installation und auch f ¨ | ur die im Kapitel 3 folgenden ersten Schritte reicht es, den ¨ | ftDuino per USB mit dem PC
zu verbinden. Eine zusätzliche Stromversorgung per Netzteil oder Batterie ist erst nötig, wenn die Ausgänge des ftDuino verwendet werden sollen.

## 2.1 Treiber

Unter den meisten Betriebssystemen wird der ftDuino vom Computer direkt erkannt, sobald er angesteckt wird. Das trifft unter anderem auf Linux, MacOS X und Windows 10 zu, aber nicht fur Windows 7. ¨

### 2.1.1 Windows 7

Windows 7 bingt den passsenden Treiber ebenfalls bereits mit. Allerdings muss eine passende .inf-Datei geladen werden,
um dafur zu sorgen, dass Windows 7 diesen Treiber f ¨ | ur den ¨ | ftDuino nutzt.

Dass kein Treiber geladen ist erkennt man u.a. daran, dass der ftDuino im Gerätemanager uner “Andere Geräte” aufgefuhrt ¨ wird.

Abbildung 2.1: ftDuino ohne passenden Treiber unter Windows 7

Die .inf-Datei ist unter https://raw.githubusercontent.com/harbaum/ftduino/master/ftduino/driver/ftduino.inf zu finden.

2.1. Treiber | 15

Nach dem Download reicht ein Rechtsklick auf die Datei und die Auswahl von “Installieren” im folgenden Menu. ¨

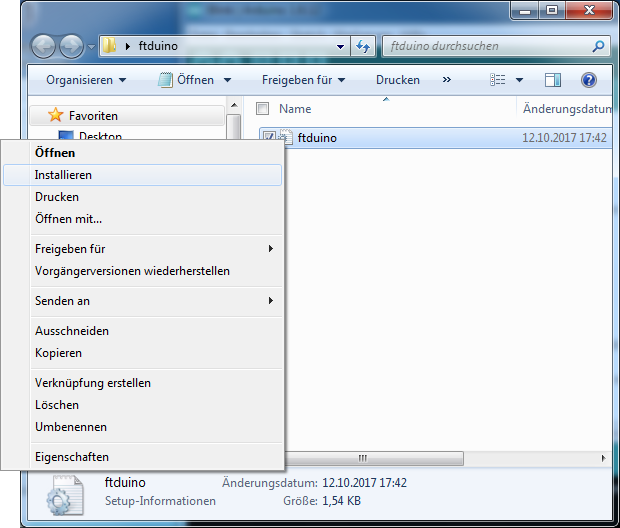
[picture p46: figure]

Abbildung 2.2: Rechtsklick auf ftduino.inf

Windows bietet daraufhin an, den Treiber zu installieren.

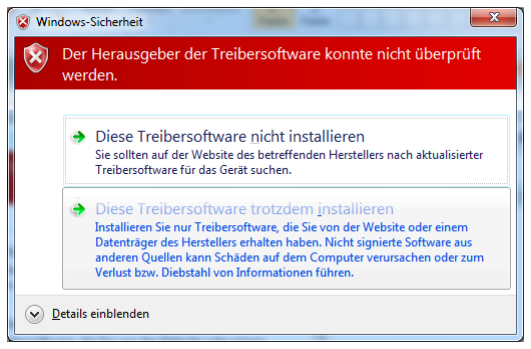
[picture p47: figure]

(a) Bestätigungsabfrage | (b) Ggf. folgende Sicherheitsabfrage

Abbildung 2.3: Installation des Treibers

Ggf. erfolgt noch eine Sicherheitsabfrage. Dieser Frage kann man getrost zustimmen, da der eigentliche Treiber bereits Teil von Windows 7 ist. Die ftduino.inf-Datei fordert Windows lediglich auf, ihn zu verwenden.

Sobald die Installation erfolgreich war wird der ftDuino als sogenannter COM:-Port eingebuden.

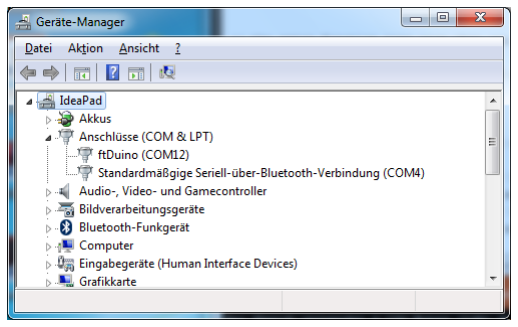
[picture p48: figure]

(a) Anwendungsmodus | (b) Bootloader

Abbildung 2.4: ftDuino mit passendem Treiber unter Windows 7

Je nach Betriebsmodus des ftDuino und je nach installierter Anwendung auf dem ftDuino befindet er sich im Anwendungsmodus oder im Bootloader. Windows unterscheidet zwischen beiden Zuständen und weist zwei unterschiedliche COM:-Ports zu. Das ist so gewollt und soll nicht weiter irritieren. In den meisten Fällen wir der Benutzer nur den Anwendungsmodus zu sehen bekommen.

16 | Kapitel 2. Installation

### 2.1.2 Linux

Der ftDuino wird von einem handelsublichen Linux-PC ohne weitere manuelle Eingriffe erkannt. Da er das sogenannte ¨ “Abstract Control Model” (ACM) implementiert taucht er im Linux-System als /dev/ttyACMX auf, wobei X eine fortlaufende Nummer ist. Sind keine weiteren ACM-Geräte verbunden, so wird der ftDuino als /dev/ttyACM0 eingebunden.

Mehr Details erfährt man z.B. direkt nach dem Anstecken des ftDuino mit dem dmesg-Kommando:

$ dmesg
[15822.397956] usb 3-1: new full-speed USB device number 9 using xhci_hcd [15822.540331] usb 3-1: New USB device found, idVendor=1c40, idProduct=0538 [15822.540334] usb 3-1: New USB device strings: Mfr=1, Product=2, SerialNumber=3 [15822.540336] usb 3-1: Product: ftDuino
[15822.540337] usb 3-1: Manufacturer: Till Harbaum
[15822.541084] cdc_acm 3-1:1.0: ttyACM0: USB ACM device

Die genauen Meldungen variieren von System zu System, aber der generelle Inhalt wird vergleichbar sein.

Weitere Details zum erkannten USB-Gerät liefert das lsusb-Kommando:

$ lsusb -vd 1c40:0538
Bus 003 Device 009: ID 1c40:0538 EZPrototypes
Device Descriptor:
bLength | 18
bDescriptorType | 1
bcdUSB | 2.00
bDeviceClass | 239 Miscellaneous Device
bDeviceSubClass | 2 ?
bDeviceProtocol | 1 Interface Association
bMaxPacketSize0 | 64
idVendor | 0x1c40 EZPrototypes
idProduct | 0x0538

Diese Ausgaben sind besonders interessant, wenn man wie in Abschnitt 4.7 oder 4.13 beschrieben die erweiterten USB-Möglichkeiten des ftDuino nutzt.

“Device or resource busy”

Auch wenn Linux bereits den eigentlichen Gerätetreiber mitbringt kann es trotzdem nötig sein, die Systemkonfiguration anzupassen. Das Symptom ist, dass es beim Versuch, auf den ftDuino zuzugreifen, in der Arduino-IDE zu der folgenden Fehlermeldung kommt.

Abbildung 2.5: Fehlermeldung bei installiertem ModemManager

In diesem Fall ist die wahrscheinlichste Ursache, dass ModemManager, ein Programm zur Bedienung von Modems, installiert ist und sich mit dem ftDuino verbunden hat. Um das zu verhindern, dass der ModemManager versucht, sich mit dem ftDuino zu verbinden, ist die Eingabe des folgenden Kommandos nötig:

sudo wget -P /etc/udev/rules.d https://raw.githubusercontent.com/harbaum/ftduino/master/ftduino/driver/99-ftduino.rules

Die Datei /etc/udev/rules.d/99-ftduino.rules muss danach exakt folgenden Inhalt haben:

ATTRS{idVendor}=="1c40" ATTRS{idProduct}=="0537", ENV{ID_MM_DEVICE_IGNORE}="1" ATTRS{idVendor}=="1c40" ATTRS{idProduct}=="0538", ENV{ID_MM_DEVICE_IGNORE}="1"

2.1. Treiber | 17

Danach muss der ftDuino einmal kurz vom PC getrennt und wieder angesteckt werden und sollte danach problem zu verwenden sein.

Das Kommandos legt eine Datei namens /etc/udev/rules.d/99-ftduino.rules an. Diese Datei enthält Regeln, wie der Linux-Kernel mit bestimmten Ereignissen umgehen soll. In diesem Fall soll beim Einstecken eines USB-Gerätes mit der Hersteller-Identifikation 1c40 und den Geräteidentifikationen 0537 und 0538 dieses vom ModemManager ignoriert werden.

18 | | Kapitel 2. Installation

## 2.2 Arduino-IDE

Die integrierte Entwicklungsumgebung (IDE) fur den Arduino bekommt man kostenlos f ¨ | ur die g ¨ | ängigsten Betriebssysteme
unter https://www.arduino.cc/en/Main/Software. Die Windows-Version mit eigenem Installer ist dort z.B. direkt unter dem Link https://www.arduino.cc/downloadḣandler.php erreichbar. Diese Arduino-IDE wird zunächst installiert.

Um den ftDuino unter der Arduino-IDE nutzen zu können muss eine entsprechende Konfoiguration vorgenommen werden. Die Arduino-IDE erlaubt es, diesen Vorgang weitgehend zu automatisieren.

### 2.2.1 Installation mit dem Boardverwalter

Fur die einfache Installation zus ¨ | ätzlicher Boards bringt die Arduino-IDE den sogenannten Boardverwalter mit. Zunächst
muss dem Boardverwalter in den Arduino-Voreinstellungen mitgeteilt werden, wo die ftDuino-Konfiguration zu finden ist.

Dazu trägt man https://raw.githubusercontent.com/harbaum/ftduino/master/package ftduino index.json in den Voreinstellungen wie folgt ein:

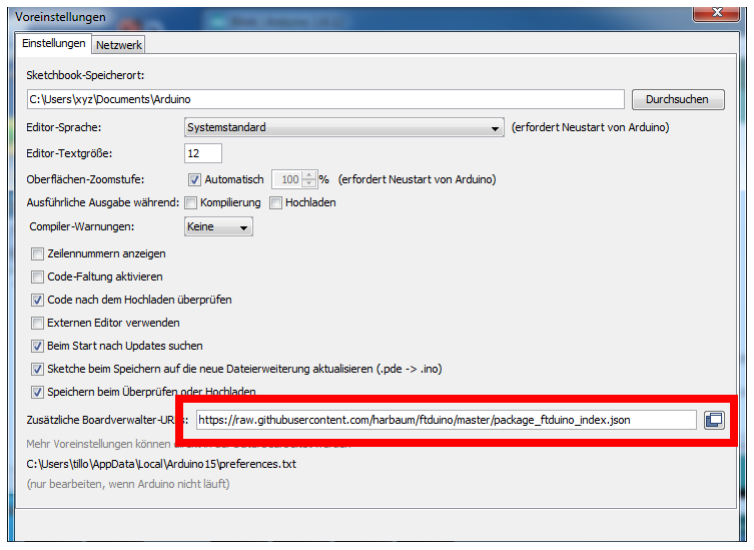
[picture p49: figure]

Abbildung 2.6: URL der ftDuino-Konfiguration in den Arduino-Voreinstellungen

Den eigentlichen Boardverwalter erreicht man danach direkt uber das Men ¨ | u der IDE unter ¨ | Werkzeuge | . | Board: ... | .
Boardverwalter... | .

Abbildung 2.7: Den Boardverwalter startet man aus dem Menü

Nachdem die JSON-Datei in den Voreinstellungen eingetragen wurde bietet der Boardverwalter automatisch die ftDuino-Konfiguration an.

Durch Klick auf Installieren... werden alle fur den ¨ ftDuino nötigen Dateien automatisch heruntergeladen und installiert.

Nach erfolgreicher Installtion kann der ftDuino unter den Boards ausgewählt werden.

2.2. Arduino-IDE | 19

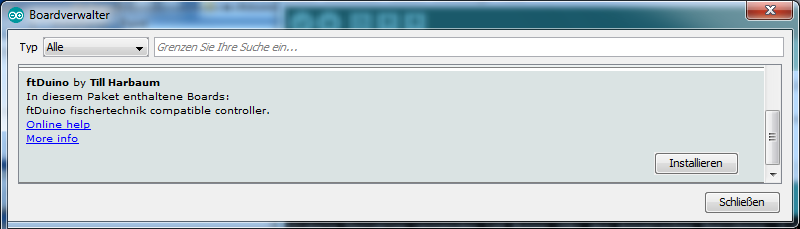
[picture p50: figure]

Abbildung 2.8: Im Boardverwalter kann das ftDuino-Board installiert werden

Abbildung 2.9: Auswahl des ftDuino-Boards

Ist bereits ein ftDuino angeschlossen und wurde der nötige Treiber installiert, so lässt sich der ftDuino nun unter Port auswählen.

Die Installation ist damit abgeschlossen. Während der Installation wurden bereits einige Beispielprogramme installiert. Diese
finden sich im Menu unter ¨ | Datei | . | Beispiele | . | Examples for ftDuino | .

Abbildung 2.10: Beispiele zum ftDuino-Board

Diese Beispiele können direkt geladen und auf den ftDuino hinuntergeladen werden.

### 2.2.2 Updates

Die Arduino-IDE benachrichtigt automatisch uber Softwareupdates der ¨ | ftDuino-Konfiguration. Mit wenig Aufwand bleibt
man so immer auf dem aktuellen Stand.

# Kapitel 3

# Erste Schritte

In diesem Kapitel geht es darum, erste Erfahrungen mit dem ftDuino und der Arduino-IDE zu sammeln. Voraussetzung ist, dass der ftDuino von einem passenden Treiber auf dem PC unterstutzt wird und dass die Arduino-IDE wie in Kapitel 2 ¨
beschrieben installiert und fur die Verwendung des ¨ | ftDuinos vorbereitet wurde.

## 3.1 Der erste Sketch

Fur die ersten Versuche ben ¨ | ötigt der ftDuino keine seperate Stromversorgung. Es genugt, wenn er per USB vom PC versorgt ¨
wird. Die fischertechnik-Ein- und Ausgänge bleiben zunächst unbenutzt.

Als erstes kann man den folgenden Sketch direkt in der Arduino-IDE eingeben. Das Beispiel muss aber nicht zwingend
manuell eingetippt werden, denn es findet sich als fertig mitgeliefertes Beispiel im | Datei | -Menu der Arduino-IDE unter ¨
Datei | . | Beispiele | . | FtduinoSimple | . | Blink | .

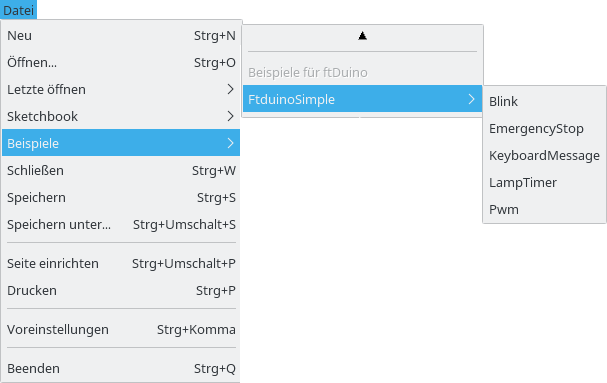
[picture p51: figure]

Abbildung 3.1: Die ftDuino-Beispiele in der Arduino-IDE

Alle vorinstallierten Beispiele können mit einem Klick geladen werden und es öffnet sich ein neues Fenster mit dem ausgewählten Beispiel.

/*
Blink

Schaltet die interne rote LED des ftDuino für eine Sekunde ein und für eine Sekunde aus und wiederholt dies endlos .

Original :
http :// www . arduino .cc/en/ Tutorial / Blink
*/

// die setup - Funktion wird einmal beim Start aufgerufen void setup () {

3.1. Der erste Sketch | 21
13 | // Konfiguriere den Pin , an den die interne LED angeschlossen ist , als Ausgang
14 | pinMode ( LED_BUILTIN , OUTPUT );
15 | }
16
17 | // die loop - Funktion wird immer wieder aufgerufen
18 | void loop () {
19 | digitalWrite ( LED_BUILTIN , HIGH ); | // schalte die LED ein ( HIGH ist der hohe Spannungspegel )
20 | delay (1000) ; | // warte 1000 Millisekunden ( eine Sekunde )
21 | digitalWrite ( LED_BUILTIN , LOW ); | // schalte die LED aus , indem die Spannung auf
22 | | // niedrigen Pegel ( LOW ) geschaltet wird
23 | delay (1000) ; | // warte eine Sekunde
24 | }

### 3.1.1 Download des Blink-Sketches auf den ftDuino

Der Blink-Sketch sollte nun geöffnet sein. Der ftDuino sollte an den PC angeschlossen sein und im Menu unter ¨ | Werkzeuge | .
Board | der ftDuino ausgewählt sowie der richtige COM:-Port unter | Werkzeuge | . | Port | ausgewählt sein. Dies zeigt die
Arduino-IDE auch ganz unten rechts in der Statusleiste an.

Abbildung 3.2: Der ausgewählte ftDuino wird in der Statusleiste angezeigt

Der Download des Sketches auf den ftDuino erfordert nur noch einen Klick auf die Download-Pfeil-Schaltfläche in der Arduino-IDE oben links.

Abbildung 3.3: Download-Schaltfläche der Arduino-IDE

Der Sketch wird von der IDE zunächst in Maschinencode ubersetzt. Wenn die ¨ | Ubersetzung erfolgreich war wird der Ma- ¨
schinencode uber die USB-Verbdinung auf den ¨ | ftDuino ubertragen und dort im Flash-Speicher abgelegt. ¨

Während des Downloads zeigt die interne rote Leuchtdiode des ftDuino wie in Abschnitt 1.2.3 beschrieben an, dass der Bootloader aktiviert wird und dass der Download stattfindet.

Nach erfolgreichem Download startet der Sketch sofort und die interne rote Leuchtdiode blinkt langsam.

+9V | +9V

Reset

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
O1 O2

O3 O4

O5 O6

O7 O8

C1

C2
C3
C4

I²C

Abbildung 3.4: Blinkende interne rote Leuchtdiode im ftDuino

22 | Kapitel 3. Erste Schritte

### 3.1.2 Die Funktionsweise des Sketches

Der Sketch-Code besteht zum uberwiegenden Teil aus erkl ¨ | ärenden Kommentaren, die fur die Funktion des Sketches v ¨ | öllig
unbedeutend sind und lediglich dem Verständnis durch einen menschlichen Leser dienen. Kommentarzeilen beginnen mit einem doppelten Schrägstrich (//). Mehrzeilige Kommentare werden durch /* und */ eingechlossen. In diesem Dokument sowie in der Arduino-IDE sind Kommentare an ihrer hellgrauen Färbung leicht zu erkennen. Tatsächlicher Code befindet sich lediglich in den Zeilen 12 bis 15 sowie den Zeilen 18 bis 24.

### 3.1.3 Die Funktionen setup() und loop()

Jeder Arduino-Sketch enthält mindestens die beiden Funktionen setup() (englisch fur Einrichtung) und ¨ | loop() (englisch
fur Schleife). Zwischen den beiden geschweiften Klammern ( ¨ | { und }) befinden sich jeweils durch Semikolon abgetrennt die
eigentlichen durch den ftDuino auszufuhrenden Befehle. Die Befehle in der Funktion ¨ | setup() werden einmal bei Sketch-
Start ausgefuhrt. Sie werden ¨ | ublicherweise verwendet, um initiale Einstellungen vorzunehmen oder Ein- und Ausg ¨ | änge zu
parametrieren. Die Befehle der loop()-Funktion werden hingegen immer wieder ausgefuhrt solange der ¨ | ftDuino eingechaltet
bleibt oder bis er neu programmiert wird. Hier findet die eigentliche Sketch-Funktion statt und hier wird auf Sensoren reagiert und Aktoren werden angesteuert.

Auch das Blink-Beispiel arbeitet so. In der setup()-Funktion wird in Zeile 14 der mit der roten Leuchtdiode verbundene interne Anschluss im ftDuino zum Ausgang erklärt.

In der loop()-Funktion wird dann in Zeile 19 der interne Anschluss der roten Leuchtdiode eingeschaltet (Spannungspegel hoch, HIGH) und in Zeile 21 wird er ausgeschaltet (Spannungspegel niedrig, LOW). Zwischendurch wird jeweils in den Zeilen 20 und 23 1000 Millisekunden bzw. eine Sekunde gewartet. Die Leuchtdiode wird also eingeschaltet, es wird eine Sekunde gewartet, sie wird ausgeschaltet und es wird eine weitere Sekunde gewartet. Dies passiert immer und immer wieder, so dass die Leuchtdiode mit einer Frequenz von 0,5 Hertz blinkt.

### 3.1.4 Anpassungen am Sketch

Fur den Einstieg ist es oft sinnvoll, mit einem vorgefertigten Sketch zu starten und dann eigene ¨ | Anderungen vorzunehmen. ¨
Die Beispiele der Arduino-IDE stehen aber allen Benutzern eines PCs zur Verfugung und k ¨ | önnen daher zunächst nicht
verändert werden. Nimmt man an einem Beispiel-Sketch Anderungen vor und versucht sie zu speichern, dann weist einen ¨ die Arduino-IDE darauf hin, dass man eine eigene Kopie anlegen soll. Dazu öffnet die Arduino-IDE einen Dateidialog und man hat die Möglichkeit, den Sketch vor dem Speichern umzubenennen z.B. in SchnellBlink.

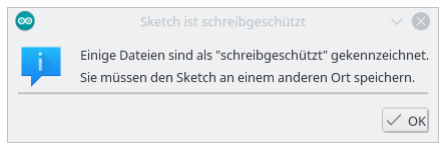
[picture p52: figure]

Abbildung 3.5: Die Arduino-IDE fordert zum Speichern einer eigenen Kopie auf

Sobald man auf diese Weise eine eigene Kopie angelegt hat kann man sie beliebig verändern. Die eigene Kopie wird im
Menu der Arduino-IDE unter ¨ | Datei | . | Sketchbook | eingefugt und kann von dort sp ¨ | äter jederzeit wieder geladen werden.

Im Sketch kann man nun beispielsweise aus den 1000 Millisekunden in den Zeilen 20 und 23 jeweils 500 Millisekunden machen.

18 | void loop () {
19 | digitalWrite ( LED_BUILTIN , HIGH ); | // schalte die LED ein ( HIGH ist der hohe Spannungspegel )
20 | delay (500) ; | // warte 500 Millisekunden ( eine halbe Sekunde )
21 | digitalWrite ( LED_BUILTIN , LOW ); | // schalte die LED aus , indem die Spannung auf
22 | // niedrigen Pegel ( LOW ) geschaltet wird
23 | delay (500) ; | // warte eine halbe Sekunde
24 | }

Nach erfolgreichem Download wird die Leuchtdiode dann jeweils fur 0,5 Sekunden ein- und ausgeschaltet und die Blinkfre- ¨ quenz verdoppelt sich auf ein Hertz.

3.2. Ansteuerung von fischertechnik-Komponenten | 23

Abbildung 3.6: Kopie SchnellBlink im Sketchbook der Arduino-IDE

## 3.2 Ansteuerung von fischertechnik-Komponenten

Um die interne Leuchtdiode des ftDuino blinken zu lassen hätten wir keinen ftDuino benötigt. Alle Arduinos verfugen ¨ | uber ¨
eine solche interne Leuchtdiode und hätten fur unser erstes Beispiel verwendet werden k ¨ | önnen.

Seine speziellen Fähigkeiten spielt der ftDuino aus, wenn es darum geht mit den ublichen fischertechnik-Sensoren und - ¨ Aktoren umzugehen. Der Blink-Sketch soll daher so erweitert werden, dass zusätzlich zu Leuchtdiode eine am Ausgang O1 angeschlossene Lampe blinkt.

Angeschlossen wird dazu eine normale fischertechnik-Lampe mit einem Stecker an den Ausgang O1 des ftDuino und mit dem
zweiten Stecker an einen der Masseanschlusse des ¨ | ftDuino. Masseanschlusse sind die 12 Anschl ¨ | usse, die in der Abbildung ¨
3.7 mit einem Massesymbol ⊥ verbunden sind.

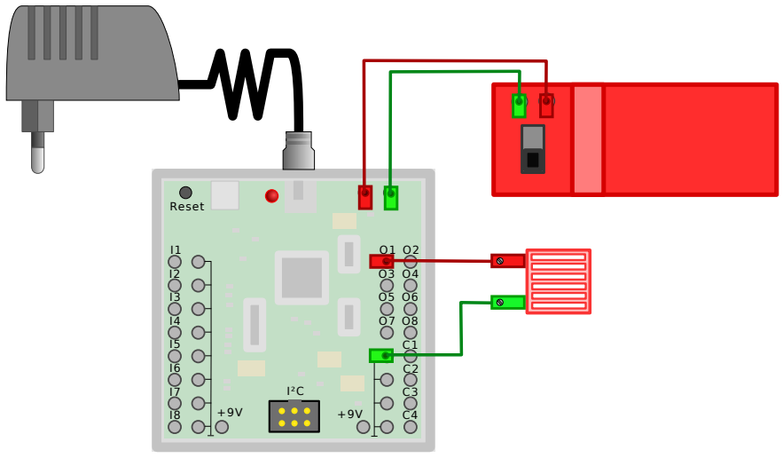
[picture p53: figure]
Reset; I²C

Abbildung 3.7: Blinkende fischertechnik-Lampe ftDuino

Da nun die mit 9 Volt betriebenen fischertechnik-Ausgänge verwendet werden muss der ftDuino zusätzlich mit 9 Volt versorgt
werden. Das kann z.B. uber ein ¨ | ubliches fischertechnik-Netzteil erfolgen oder ¨ | uber einen Batteriehalter. Beide Anschl ¨ | usse ¨
sind verpolungsgeschutzt, speziell beim Anschluss der Batterie kann man also keinen Schaden anrichten. ¨

### 3.2.1 Der Sketch

Der folgende Beispiel-Sketch BlinkO1 findet sich auch im | Datei | -Menu der Arduino-IDE unter ¨ | Datei | . | Beispiele | .
FtduinoSimple | . | BlinkO1 | .

24 | Kapitel 3. Erste Schritte
1 | // BlinkO1 .ino
2 | //
3 | // Blinken einer Lamoe an Ausgang O1
4 | //
5 | // (c) 2018 by Till Harbaum < till@harbaum .org >
6
7 # include < FtduinoSimple .h >
8
9 | void setup () {
10 | // LED initialisieren
11 | pinMode ( LED_BUILTIN , OUTPUT );
12 | }
13
14 | void loop () {
15 | // schalte die interne LED und den Ausgang O1 ein ( HIGH bzw . HI)
16 | digitalWrite ( LED_BUILTIN , HIGH );
17 | ftduino . output_set ( Ftduino ::O1 , Ftduino :: HI);
18
19 | delay (1000) ; | // warte 1000 Millisekunden ( eine Sekunde )
20
21 | // schalte die interne LED und den Ausgang O1 aus ( LOW bzw . LO)
22 | digitalWrite ( LED_BUILTIN , LOW );
23 | ftduino . output_set ( Ftduino ::O1 , Ftduino :: LO);
24
25 | delay (1000) ; | // warte eine Sekunde
26 | }

Der Sketch unterscheidet sich nur in wenigen Details vom ursprunglichen Blink-Sketch. Neu hinzugekommen sind die Zeilen ¨ 7, 17 und 23. In Zeile 7 wird eine Bibliothek eingebunden, die speziell fur den ¨ ftDuino mitgeliefert wird und den Zugriff auf die Ein- und Ausgänge des ftDuino vereinfacht. In den Zeilen 17 und 23 wird der Ausgang O1 eingeschaltet (HI) bzw. ausgeschaltet (LO). Weitere Details zu dieser Bibliothek finden sich in Kapitel 7.

Die Kommandos zum Ein- und Ausschalten der internen Leuchtdiode sind nach wie vor vorhanden, so dass die interne Leuchtdiode nun parallel zur extern angeschlossenen Lampe blinkt.

Weitere einfache Beispiele und Erklärungen zur Benutzung der Ein- und Ausgänge in eigenen Sketches finden sich in Abschnitt 7.1.1.

## 3.3 Kommunikation mit dem PC

Der ftDuino ist primär dafur gedacht, ein Modell autonom zu steuern und w ¨ | ährend des Betriebs nicht auf die Hilfe eines
PC angewiesen zu sein. Trotzdem gibt es Grunde, warum auch im laufenden Betrieb ein Datenaustausch mit einem PC ¨ erwunscht sein kann. ¨

Vor allem während der Sketch-Entwicklung und bei der Fehlersuche hilft es oft sehr, wenn man sich z.B. bestimmte Werte am PC anzeigen lassen kann oder wenn man Fehlermeldungen im Klartext an den PC senden kann. Aber auch die Ausgabe z.B. von Messwerten an den PC zur weiteren Auswertung oder Speicherung ist oft hilfreich.

Ein Sketck kann dazu den COM:-Port zwischen ftDuino und PC fur den Datenaustausch nutzen. Der ¨ | ftDuino-Beispiel-Sketch
ComPort zum Beispiel verwendet den COM:-Port, um ein paar einfache Textausgaben am PC zu erzeugen. Das ComPort-
Beispiel findet sich im | Datei | -Menu der Arduino-IDE unter ¨ | Datei | . | Beispiele | . | FtduinoSimple | . | USB | . | ComPort | .
Auch der ComPort-Sketch verwendet keinen der Ausgänge und benötigt daher neben der USB-Verbindung keinerlei weitere Spannungsversorung.
1 | /*
2 | ComPort - Kommunikation mit dem PC ü ber den COM: - Port
3
4 */
5
6 int zaehler = 0;
7
8 | void setup () {
9 | // Port initialisieren und auf USB - Verbindung warten
10 | Serial . begin (9600) ;
11 | while (! Serial ) ; | // warte auf USB - Verbindung
12

3.3. Kommunikation mit dem PC | 25
13 | Serial . println (" ftDuino COM :- Port test ");
14 | }
15
16 | void loop () {
17 | Serial . print ("Zä hler : "); | // gib "Zä hler :" aus
18 | Serial . println ( zaehler , DEC ); | // gib zaehler als Dezimalzahl aus
19
20 | zaehler = zaehler +1; | // zaehler um eins hochz ä hlen
21
22 | delay (1000) ; | // warte 1 Sekunde (1000 Millisekunden )
23 | }

### 3.3.1 Der serielle Monitor

Man kann ein beliebiges sogenanntes Terminalprogramm auf dem PC nutzen, um Textausgaben des ftDuino via COM:-Port zu empfangen. Die Arduino-IDE bringt prakischerweise selbst ein solches Terminal mit. Es findet sich im Menu unter ¨
Werkzeuge | . | Serieller Monitor | .

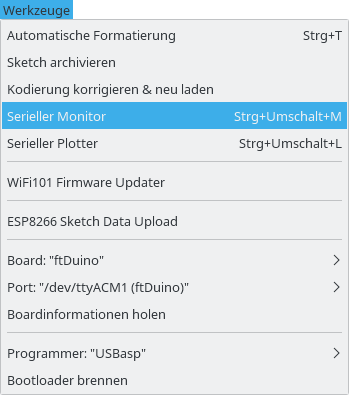
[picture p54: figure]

Abbildung 3.8: Der serielle Monitor findet sich im | Werkzeuge | -Menü
Man muss den COM:-Port nicht seperat einstellen, sondern es wird der COM:-Port ubernommen, der bereits f ¨ | ur den Sketch- ¨
Download eingestellt wurde.

Nach der Auswahl im Menü öffnet der serielle Monitor ein eigenes zusätzliches Fenster auf dem PC. Wurde der ComPort-Sketch bereits auf den ftDuino geladen, dann erscheinen sofort entsprechende Ausgaben, sobald der serielle Monitor geöffnet wurde.

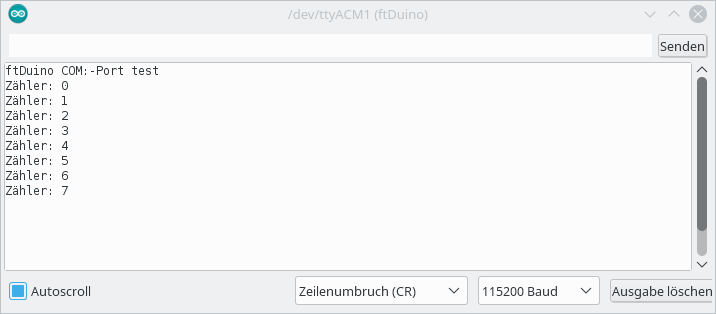
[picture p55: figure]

Abbildung 3.9: Der serielle Monitor

Die Nutzung des COM:-Ports wird automatisch zwischen Sketch-Download und seriellem Monitor geteilt. Man kann also jederzeit bei geöffnetem seriellen Monitor den Sketch-Editor in den Vordergrund holen und einen Download starten. Der seriellem Monitor wird dann automatisch fur die Zeit des Downloads deaktiviert. ¨

Eine Besonderheit des USB-COM:-Ports die der ftDuino vom Arduino Leonardo erbt ist, dass die sogenannte Bitrate (oft auch Baudrate genannt) keine Bedeutung hat. Im ComPort-Beispiel wird in Zeile 10 eine Bitrate von 9600 Bit pro Sekunde

26 | Kapitel 3. Erste Schritte

eingestellt, in Abbildung 3.9 ist aber unten rechts eine Bitrate von 115200 Bit pro Sekunde eingestellt. Die USB-Verbindung ignoriert diese Einstellungen und kommuniziert trotzdem fehlerfrei. Einige andere Mitglieder der Arduino-Familie wie der Arduino-Uno benötigen hier aber ubereinstimmende Einstellungen. ¨

### 3.3.2 Sketchbeschreibung

Der Sketch besteht aus wenig mehr als den eigentlich Aufrufen zur Bedienung des COM:-Ports. Da der COM:-Port auch oft “serieller Port”, englisch “Serial” genannt wird fangen die entsprechenden Funktionsaufrufe alle mit Serial. an.

In Zeile 10 der sofort bei Sketchstart aufgerufenen setup()-Funktion wird zunächst der COM:-Port fur die Kommunikation ¨ geöffnet. In Zeile 11 dann wird gewartet, bis der COM:-Port auf PC-Seite verfugbar ist und die erste Kommunikation ¨ stattfinden kann. In Zeile 13 wird danach eine erste Startmeldung an den PC geschickt.

Innerhalb der widerholt durchlaufenen loop()-Funktion wird dann in den Zeilen 17 und 18 zunächst der Text “Zähler: “ ausgegeben, gefolgt von dem Inhalt der Variablen zaehler in Dezimaldarstellung. Die println()-Funktion fuhrt nach der ¨ Ausgabe einen Zeilenvorschub aus. Die folgende Ausgabe erfolgt daher am Beginn der nächsten Bildschirmzeile.

Schließlich wird in Zeile 20 die zaehler-Variable um eins erhöht und eine Sekunde (1000 Millisekunden) gewartet.

### 3.3.3 USB-Verbindungsaufbau

Bei Geräten wie dem Arduino Uno, die einen seperaten USB-Kommunikationsbaustein fur die USB-Kommunikation nutzen, ¨ besteht die USB-Verbindung durchgängig, sobald das Gerät mit dem PC verbunden ist. Beim ftDuino sowie beim Arduino Leonardo ubernimmt der Mikrocontroller wichtige Aspekte der USB-Kommunikaiton selbst. Das bedeutet, dass die logische ¨ USB-Verbindung jedes Mal getrennt und neu aufgebaut wird, wenn ein neuer Sketch auf den Mikrocontroller ubertragen ¨ wird.

Beginnt der ftDuino direkt nach dem Download mit der Textausgabe auf dem COM:-Port, so gehen die ersten Nachrichten verloren, da die USB-Verbindung noch nicht wieder aufgebaut ist. Daher wartet der Sketch in Zeile 11 darauf, dass die Kommunikationsverbindung zwischen ftDuino und PC wieder besteht, bevor die ersten Ausgaben erfolgen.

Man kann testweise diese Zeile einmal löschen oder auskommentieren (Programmcode, der per // in einen Kommentar verwandelt wurde, wird nicht ausgefuhrt). ¨

8 | void setup () {
9 | // Port initialisieren und auf USB - Verbindung warten
10 | | Serial . begin (9600) ;
11 | // | while (! Serial ); | // warte auf USB - Verbindung
12
13 | Serial . println (" ftDuino COM :- Port test ");
14 | }

Lädt man diesen Sketch nun auf den ftDuino, so beginnt die Textausgabe im seriellen Monitor erst ab der Zeile Zähler: 2. Die beiden vorhergehenden Zeilen werden vom ftDuino an den PC gesendet, bevor die USB-Verbindung wieder steht und
gehen daher verloren. Dieses Verhalten kann trotzdem gewunscht sein, wenn die Ausgabe ¨ | uber USB nur zus ¨ | ätzlich erfolgen
soll und der ftDuino auch ohne angeschlossenen PC arbeiten soll.

# Kapitel 4

# Experimente

Die Experimente dieses Kapitels konzentrieren sich auf einzelne Aspekte des ftDuino. Sie veranschaulichen einen Effekt oder
ein Konzept und verwenden dafur nur minimale externe Komponenten. Die Experimente stellen an sich keine vollst ¨ | ändigen
Modelle dar, können aber oft als Basis dafur dienen. ¨

Beispiele fur komplexe Modelle finden sich im Kapitel 5. ¨

## 4.1 Lampen-Zeitschaltung

Schwierigkeitsgrad:

Dieses sehr einfache Modell besteht nur aus einem Taster und einer Lampe und bildet die Funktion einer typischen Treppenhausbeleuchtung nach. Um Energie zu sparen wird hier nicht einfach ein Kippschalter genommen, um das Licht zu schalten. Stattdessen wird ein Taster verwendet und jeder Druck auf den Taster schaltet das Licht nur fur z.B. zehn Sekunden ein. ¨
Wird während dieser Zeit der Taster erneut gedruckt, so verl ¨ | ängert sich die verbleibende Zeit wieder auf volle zehn Sekunden.
Nach Ablauf der zehn Sekunden verlischt das Licht und das Spiel beginnt von vorn.

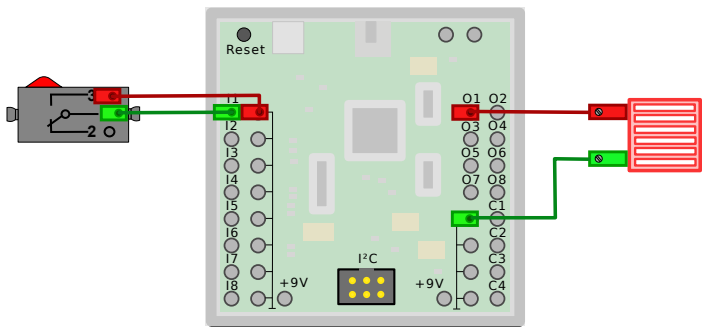
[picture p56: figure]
Reset; I²C

Abbildung 4.1: Lampen-Zeitschaltung

4.1.1 Sketch LampTimer (https://github.com/harbaum/ftduino/tree/master/ftduino/libraries/FtduinoSimple/examples/LampTimer)

Der folgende Sketch findet sich bei installierter ftDuino-Unterstutzung im Men ¨ | u der Arduino-IDE unter ¨ | Datei | .
Beispiele | . | FtduinoSimple | . | LampTimer | .
1 | /*
2 | LampTimer - Lampen - Zeitschaltuhr
3
4 | (c) 2017 by Till Harbaum < till@harbaum .org >
5

Kapitel 4. Experimente

Schaltet eine Lampe an Ausgang O1 für 10 Sekunden ein , sobald ein Taster an Eingang I1 gedr ü ckt wird .
*/

# include < FtduinoSimple .h >

uint32_t startzeit = 0;

// Die Setup - Funktion wird einmal ausgef ührt , wenn Reset gedr ü ckt oder // das Board gestartet wird .
void setup () { }

// Die Loop - Funktion wird endlos immer und immer wieder ausgef ü hrt void loop () {
// Teste , ob der Taster an I1 gedr ü ckt ist
if( ftduino . input_get ( Ftduino :: I1)) {
// merke Startzeit
startzeit = millis () ;

// schalte Lampe ein ( Ausgang HI)
ftduino . output_set ( Ftduino ::O1 , Ftduino :: HI);
}

// gü ltige Startzeit und seitdem mehr als 10 Sekunden // (10.000 Millisekunden ) verstrichen ?
if (( startzeit != 0) &&
( millis () > startzeit + 10000) ) {
// vergiss Startzeit
startzeit = 0;
// schalte Lampe aus ( Ausgang OFF )
ftduino . output_set ( Ftduino ::O1 , Ftduino :: OFF ); }
}

Sketchbeschreibung

Die fur die Lampen-Zeitschaltung n ¨ | ötigen Funktionen des ftDuino sind sehr einfach und die Anwendung lässt sich mit der
einfachen FtduinoSimple-Bibliothek (siehe Abschnitt 7.1) abdecken.

Der Arduino-Sketch enthält eine leere setup()-Funktion, da keine Initialisierung nötig ist. Sämtliche Funktionalität steckt in der loop()-Funktion.

Die Taste an I1 wird uber ¨ | input get() permanent abgefragt. Ist sie gedruckt, so wird die aktuelle Zeit seit Ger ¨ | ätestart
in Millisekunden mit der Funktion millis() abgefragt und in der Variablen startzeit gespeichert und die Lamoe wird eingeschaltet. War die Lampe bereits an, dann bewirkt dieses zusätzliche Einschalten nichts, aber der bereits gesetzte Zeitwert in startzeit wird durch den aktuellen ersetzt.
Unabhängig davon wird permanent getestet, ob startzeit einen gultigen Wert enth ¨ | ält und ob die aktuelle Systemzeit
bereits mehr als zehn Sekunden (10.000 Millisekunden) nach dem dort gespeicherten Wert liegt. Ist das der Fall, dann sind seit dem letzten Tastendruck mehr als zehn Sekunden vergangen und die Lampe wird ausgeschaltet sowie der Wert in startzeit auf Null gesetzt, um ihn als ungultig zu markieren. ¨

Aufgabe 1: 20 Sekunden

Sorge dafur, dass die Lampe nach jedem Tastendruck 20 Sekunden lang an bleibt. ¨

Lösung 1:

In Zeile 32 muss der Wert 10000 durch den Wert 20000 ersetzt werden, damit die Lampe 20000 Millisekunden, also 20 Sekunden eingeschaltet bleibt.

if (( startzeit != 0) &&
( millis () > startzeit + 20000) ) {

4.2. Not-Aus | 29

Aufgabe 2: Keine Verlängerung

Sorge dafur, dass ein weiterer Druck auf den Taster, w ¨ | ährend die Lampe bereits leutet, die verbleibende Zeit nicht wieder
auf 10 Sekunden verlängert.

Lösung 2:

Vor der Zuweisung in Zeile 23 muss eine zusätzliche Abfrage eingefugt werden, die nur dann einen neue Wert setzt, wenn ¨ bisher keiner gesetzt war. Beide Zeilen zusammen sehen dann so aus:

23 | if( startzeit == 0)
24 | startzeit = millis () ;

Expertenaufgabe:

Schließt Du statt der Lampe eine Leuchtdiode an (der rote Anschluss der Leuchtdiode muss an Ausgang O1), dann wirst Du etwas merkwurdiges bemerken, wenn das Licht eigentlich aus sein sollte: Die Leuchtdiode leuchtet trotzdem ganz schwach, ¨ obwohl der Ausgang doch OFF ist. Wie kommt das?

Erklärung

Durch eine Lampe oder Leuchtdiode fließt ein Strom, wenn zwischen den beiden Anschlussen ein Spannungsunterschied ¨ besteht. Den einen Anschluss haben wir fest mit Masse bzw. 0 Volt verbunden, der andere ist offen und wird von den Bauteilen im ftDuino nicht mit Spannung versorgt. Anders als bei einem mechanischem Schalter ist diese Trennung bei dem im ftDuino als sogenannter Ausgangstreiber verwendeten Halbleiterbaustein aber nicht perfekt. Ein ganz kleiner sogenannter Leckstrom fließt trotzdem zur 9V-Versorgungsspannung. Dieser kleine Strom reicht nicht, die Lampe zum Leuchten zu bringen. Aber er reicht, die wesentlich effizientere Leuchtdiode ganz leicht aufleuchten zu lassen.

Lässt sich daran etwas ändern? Ja! Statt den Ausgang komplett unbeschaltet zu lassen können wir dem Ausgangstreiber im ftDuino sagen, dass er den Ausgang fest auf Masse (0 Volt) schalten soll. Beide Anschlusse der Leuchtdiode liegen dann ¨
fest auf Masse und die Einflusse irgendwelcher Leckstr ¨ | öme treten nicht mehr in Erscheinung. Dazu muss in der Zeile 36 die
Konstante OFF durch LO ersetzt werden. LO steht fur low, english niedrig und meint in diesem Fall 0 Volt. Die Leuchtdiode ¨ erlischt nun komplett nach Ablauf der Zeit.
36 | ftduino . output_set ( Ftduino ::O1 , Ftduino :: LO);

Direkt nach dem Einschalten des ftDuino leuchtet die Leuchtdiode aber nach wie vor. Vielleicht findest Du selbst heraus, wie sich das ändern lässt. Tipp: Die bisher unbenutzte setup()-Funktion könnte helfen.

Mehr dazu gibt es im Abchnitt 4.5.

## 4.2 Not-Aus

Schwierigkeitsgrad:

Ein Not-Aus-Schalter kann Leben retten und scheint eine einfache Sache zu sein: Man druckt einen Taster und die betreffende ¨ Maschine schaltet sich sofort ab. Im Modell stellt ein XS-Motor mit Ventilator an Ausgang M1 die Maschine dar. Ein Taster an Eingang I1 bildet den Not-Aus-Taster.

4.2.1 Sketch EmergencyStop (https://github.com/harbaum/ftduino/tree/master/ftduino/libraries/FtduinoSimple/examples/EmergencyStop)

1 | /*
2 | EmergencyStop - Not - Aus
3
4 | (c) 2017 by Till Harbaum < till@harbaum .org >
5
6 | Schaltet einen Ventilator aus , sobald der Not -Aus - Taster

30 | Kapitel 4. Experimente

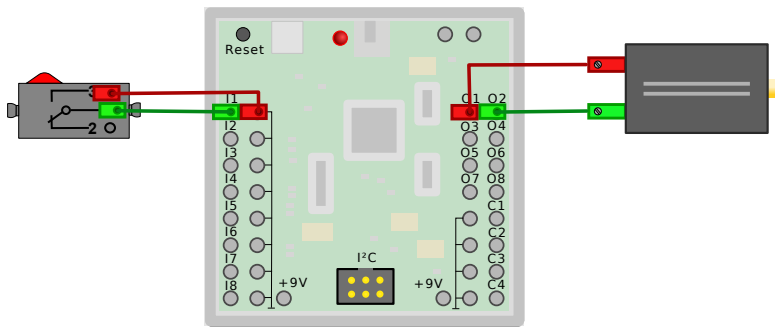
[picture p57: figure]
Reset; I²C

Abbildung 4.2: Not-Aus

7 | bet ä tigt wird .
8 | */
9
10 # include < FtduinoSimple .h >
11
12 | // Die Setup - Funktion wird einmal bei Start des Systems ausgef ü hrt
13 | void setup () {
14 | // Ventilator bei Start des Systems einschalten
15 | ftduino . motor_set ( Ftduino ::M1 , Ftduino :: LEFT );
16
17 | // Ausgang der internen roten LED aktivieren
18 | pinMode ( LED_BUILTIN , OUTPUT );
19 | // und LED ausschalten
20 | digitalWrite ( LED_BUILTIN , LOW );
21 | }
22
23 | // Die Loop - Funktion wird endlos immer und immer wieder ausgef ü hrt
24 | void loop () {
25 | // Teste , ob der Taster an I1 gedr ü ckt ist
26 | if( ftduino . input_get ( Ftduino :: I1)) {
27 | // Motor bremsen
28 | ftduino . motor_set ( Ftduino ::M1 , Ftduino :: BRAKE );
29 | // interne rote LED einschalten
30 | digitalWrite ( LED_BUILTIN , HIGH );
31 | }
32 | }

Sketchbeschreibung

Der Sketch ist sehr kurz und einfach. In der setup()-Funktion wird in Zeile 15 bei Sketchstart der Motor gestartet. Zusätzlich
wird in den Zeilen 18 bis 20 die rote interne Leuchtdiode des ftDuino fur die sp ¨ | ätere Verwendung aktiviert, aber zunächst
ausgeschaltet gelassen.

In der loop()-Funktion wird in Zeile 26 permanent abgefragt, ob der Not-Aus-Taster geschlossen wurde. Ist das der Fall, dann wird der Motor in Zeile 28 sofort gestoppt und in Zeile 30 die rote Leuchtdiode eingeschaltet. Der Motor wird bewusst per BRAKE gestoppt statt OFF. Auf diese Weise wird der Motor kurzgeschlossen und aktiv gebremst, während er andernfalls
langsam auslaufen wurde, was im Notfall eine Gefahr darstellen w ¨ | urde. ¨

Aufgabe 1: Kabelbruch

Not-Taster sind zwar an vielen Maschinen vorhanden. Glucklicherweise werden sie aber nur sehr selten wirklich ben ¨ | ötigt.
Das hat den Nachteil, dass kaum jemand bemerken wird, wenn mit dem Not-Aus-Taster etwas nicht stimmt. Anfälliger als der Taster selbst sind oft die Kabel und es kann im Arbeitsalltag leicht passieren, dass ein Kabel beschädigt wird. Oft sieht man das dem Kabel nicht an, wenn z.B. die Ummantelung unbeschädigt aussieht, durch zu starke Belastung aber dennoch die Kupferleiter im Inneren unterbrochen sind. Der Resultat ist ein sogenannter Kabelbruch.

4.2. Not-Aus | 31

Du musst kein Kabel durchreissen. Es reicht, wenn Du einen der Stecker am Kabel, das den Taster mit dem ftDuino verbindet, heraus ziehst. Der Not-Aus-Taster funktioniert dann nicht mehr und die Maschine lässt sich nicht stoppen. Eine gefährliche Situation.

Lösung 1:

Die Lösung fur das Problem ist ¨ | uberraschend einfach. Wir haben unseren Not-Aus-Taster als Schließer angeschlossen. Das ¨
bedeutet, dass der Kontakt geschlossen wird, wenn der Taster betätigt wird. Man kann den fischertechni-Taster aber auch
als Offner verwenden. Der Kontakt ist dann im Ruhezustand geschlossen und wird bei Druck auf den Taster ge ¨ | öffnet.

3

2

1

3

2

1

Abbildung 4.3: Kabelbruchsicherer Not-Aus-Offner ¨

Mit dem aktuellen Sketch geht die Maschine bei einem Kabelbruch sofort in den Notzustand, da der Taster ja sofort als geschlossen erkannt wird. Also muss auch im Sketch die Logik herum gedreht werden. Das passiert durch folgende Anderung ¨ in Zeile 26:

26 | if (! ftduino . input_get ( Ftduino :: I1) ) {

Man muss genau hinschauen, um den Unterschied zu sehen. Hinter der öffnenden Klammer steht nun aus Ausrufezeichen, das
in der Programmiersprache C fur die logische Negation eines Ausdrucks steht. Die Bedingung wird nun also ausgef ¨ | uhrt, wenn ¨
der Taster nicht geschlossen ist. Nach dieser Anderung sollte sich die Maschine wieder genau wie urspr ¨ | unglich verhalten. ¨
Mit einer kleinen Anderung: Zieht man nun einen der Stecker am Not-Aus-Taster heraus, so stoppt die Maschine sofort. ¨ Bei einem Kabelbruch wurde das ebenfalls passieren. ¨

So eine Schaltung nennt man auf englisch “Fail-Safe”: Wenn etwas kaputt geht, dann wechselt die Schaltung in einen sicheren Zustand. Der fischertechnik-3D-Drucker verwendet diese Schaltung zum Beispiel fur die Endlagentaster. Ist hier ein ¨ Kabel abgerissen, dann fährt der Drucker seine Motoren nicht gewaltsam gegen die Endanschläge der Achsen. Stattdessen verweigert der Drucker die Arbeit komplett, sobald die Verbdindung zu einem Endlagentaster unterbrochen ist.

Expertenaufgabe:

Ein Kabel kann nicht nur unterbrochen werden. Es kann auch passieren, dass ein Kabel z.B. so stark gequetscht wird, dass die inneren Leiter Kontakt miteinander bekommen. Das passiert wesentlich seltener, stellt aber ebenfalls eine realistische Gefahr dar.

Vor diesem Fall wurde unsere verbesserte Notschaltung nicht sch ¨ | utzen und der Not-Aus-Taster w ¨ | urde in dem Fall wieder ¨
nicht funkionieren. Wir brauchen also eine Variante, bei der weder der geschlossene noch der offene Zustand der Verbindung als “gut” erkannt wird.

Lösung:

Die Lösung ist in diesem Fall etwas aufwändiger. Es mussen nun mindestens drei Zust ¨ | ände unterschieden werden: “normal”,
“unterbrochen” und “kurzgeschlossen”. Reine Schalteingänge können aber nur die beiden Zustände “geschlossen” und “offen” unterscheiden.

Die Lösung ist, die analogen Fähigkeiten der Eingänge zu nutzen. Dazu kann man z.B. direkt am Taster einen 100 Ω-Widerstand in die Leitung integrieren.

Im Normalfall ist der Taster geschlossen und der am Eingang I1 zu messende Widerstand beträgt 100 Ω. Ist die Leitung unterbrochen, dann ist der Widerstand unendlich hoch. Und ist die Leitung kurzgeschlossen, dann ist der Widerstand nahe 0 Ω. Die Maschine darf also nur dann laufen, wenn der Widerstand nahe an 100 Ω ist. Etwas Toleranz ist nötig, da der genau Wert des verwendeten Widerstands Fertigungstoleranzen unterworfen ist und auch der geschlossene Taster sowie sein
Anschlusskabel uber einen eigenen sehr geringen Widerstand verf ¨ | ugen, der den gemessenen Gesamtwiderstand beeinflusst. ¨

32 | Kapitel 4. Experimente

3

2

1

Abbildung 4.4: Gegen Kabelbruch und Kurzschluss sicherer Not-Aus

Warum muss der Widerstand nahe am Taster angebracht werden? Was passiert, wenn er nahe am ftDuino eingesetzt wird und dann ein Kurzschluss im Kabel zwischen Widerstand und Taster auftritt?

## 4.3 Pulsweitenmodulation

Schwierigkeitsgrad:

Wenn man eine Lampe mit variierender Helligkeit leuchten lassen möchte oder einen Motor mit regelbarer Geschwindigkeit laufen lassen will, dann benötigt man eine Möglichkeit, die Energieaufnahme der Lampe oder des Motors zu beeinflussen. Am einfachsten klappt das mit einer einstellbaren Spannungsquelle. Bei höherer Spannung steigt auch die Energieaufnahme der Lampe und sie leuchtet heller und der Motor dreht sich schneller, bei niedrigerer Spannung wird die Lampe dunkler und
der Motor dreht sich langsamer. Fur die Analogausg ¨ | änge des ftDuino bedeutet das, dass sie eine zwischen 0 und 9 Volt
kontinuierlich (analog) einstellbare Spannung ausgeben können sollen, um Lampen und Motoren von völliger Dunkelheit bzw. Stillstand bis zu maximaler Helligkeit bzw. Drehzahl betreiben zu können.

Der Erzeugung variabler Spannungen ist technisch relativ aufwändig. Es gibt allerdings einen einfachen Weg, ein verglaichbares Ergebnis zu erzielen. Statt die Spannung zu senken schaltet man die Spannung periodisch nur fur sehr kurze Momente ¨ ein. Schaltet man die Spannung z.B. nur 50% der Zeit ein und 50% der Zeit aus, so wird uber die Gesamtzeit gesehen nur die ¨ Hälfte der Energie ubertragen. Ob man das Ergebnis als Blinken der Lampe oder als Stottern des Motors wahrnimmt oder ¨ ob die Lampe einfach mit halber Helligkeit leuchtet und der Motor mit halber Drehzahl dreht ist von der Geschwindigkeit abhängig, mit der man die Spannung ein- und auschaltet.

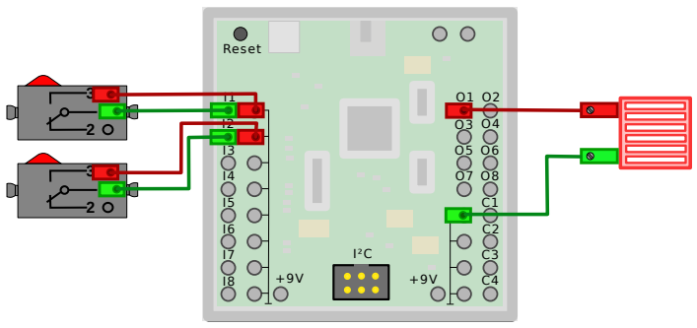
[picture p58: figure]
Reset; I²C

Abbildung 4.5: Pulsweitenmodulation

4.3.1 Sketch Pwm (https://github.com/harbaum/ftduino/tree/master/ftduino/libraries/FtduinoSimple/examples/Pwm)

1 | /*
2 | Pwm - Pulsweitenmodulation
3
4 | (c) 2017 by Till Harbaum < till@harbaum .org >
5 | */
6
7 # include < FtduinoSimple .h >
8
9 | uint16_t schaltzeit = 8192; | // 8192 entspricht je 1/2 Sekunde an und aus
10
11 | // Die Setup - Funktion wird einmal ausgef ührt , wenn Reset gedr ü ckt oder
12 | // das Board gestartet wird .

4.3. Pulsweitenmodulation | 33

void setup () { }

// warte die angegebene Zeit . Der " zeit " - Wert 8192 soll dabei einer halben Sekunde // entsprechen . Es muss also " zeit " mal 500000/8192 Mikrosekunden gewartet werden void warte ( uint16_t zeit ) {
while (zeit - -)
_delay_us (500000/8192) ;
}

// Die Loop - Funktion wird endlos immer und immer wieder ausgef ü hrt
void loop () {
24 | static uint8_t an_aus = false ; | // der aktuelle Ausgang -an/aus - Zustand
25 | static uint8_t i1=false , i2= false ; | // letzter Zustand der Tasten an I1 und I2
| // ist die Taste an I1 gedr ückt?
| if( ftduino . input_get ( Ftduino :: I1)) {
// und war die Taste vorher nicht gedr ü ckt und ist die // aktuelle Schaltzeit kleiner 8192?
| if (! i1 && ( schaltzeit < 8192) ) {
| // dann verdopple die Schaltzeit
| schaltzeit *= 2;
// warte eine Millisekunde , falls die Taste nachprellt
| _delay_ms (1) ;
| }
// merke , dass die Taste an I1 zur Zeit gedr ü ckt ist
| i1 = true ;
| } else
// merke , dass die Taste an I1 zur Zeit nicht gedr ückt ist
| i1 = false ;
| // ist die Taste an I2 gedr ückt?
| if( ftduino . input_get ( Ftduino :: I2)) {
// und war die Taste vorher nicht gedr ü ckt und ist die
| // aktuelle Schaltzeit größer 1?
| if (! i2 && ( schaltzeit > 1) ) {
| // dann halbiere die Schaltzeit
| schaltzeit /= 2;
// warte eine Millisekunde , falls die Taste nachprellt
| _delay_ms (1) ;
| }
// merke , dass die Taste an I2 zur Zeit gedr ü ckt ist
| i2 = true ;
| } else
// merke , dass die Taste an I2 zur Zeit nicht gedr ückt ist
| i2 = false ;

// schalte den Ausgand O2 je nach Zustand der an_aus - Variable an oder aus
| if( an_aus )
// wenn der aktuelle an_aus - Zustand wahr ist , dann schalte den Ausgang ein ftduino . output_set ( Ftduino ::O1 , Ftduino :: HI);
| else
// wenn der aktuelle an_aus - Zustand unwahr ist , dann schalte den Ausgang aus ftduino . output_set ( Ftduino ::O1 , Ftduino :: OFF );
| // warte die aktuelle Schaltzeit
| warte ( schaltzeit );
| // wechsel den an_aus - Zustand
| an_aus = ! an_aus ;
}

Sketchbeschreibung

Der Sketch schaltet den Ausgang O1 in der loop()-Funktion in den Zeilen 60 bis 71 kontinuierlich ein und aus. Je nach Wert der Variable an aus wird der Ausgang in Zeile 62 auf 9 Volt (HI) geschaltet oder in Zeile 65 ausgeschaltet (von der Spannungsversorung getrennt). In Zeile 71 wird in jedem Durchlauf der loop()-Funktion der Zustand der Variable an aus gewechselt, so dass der Ausgang im in jedem Durchlauf im Wechsel ein- und ausgeschaltet wird.

Nach jeden An/Aus-Wechsel wird in Zeile 68 etwas gewartet. Wie lange gewartet wird steht in der Variablen schaltzeit Sie gibt die Wartezeit in 1/8192 halben Sekunden an. Dazu wird in der Funktion wait() in Zeile 19 so oft 500000/8192

34 | Kapitel 4. Experimente

Mikrosekunden gewartet wie in der Variablen schaltzeit angegeben. Warum halbe Sekunden? Weil zweimal pro Zyklus gewartet wird, einmal wenn der Ausgang eingeschaltet ist und einmal wenn er ausgeschaltet ist. Wird jeweils eine halbe Sekunde gewartet, so dauert der gesamte Zylus eine Sekunde und der Ausgang wird einmal pro Sekunde fur eine halbe ¨ Sekunde eingeschaltet. Der Ausgang wechselt also mit einer Frequenz von 1/Sek. oder einem Hertz.

Durch einen Druck auf den Taster an I1 (Zeile 28) kann der Werte der Variablen schaltzeit verdoppelt (Zeile 33) und mit einem Druck auf den Taster an I2 (Zeile 44) halbiert (Zeile 49) werden. Dabei wird der Wert von Schaltzeit auf den Bereich von 1 (Zeile 47) und 8192 (Zeile 31) begrenzt. Nun wird auch klar, warum dieser merkwurdig “krumme” Wert 8192 ¨ gewählt wurde: Da 8192 eine Zweierpotenz (2

13) ist lässt der Wert sich ohne Rundungsfehler bis auf 1 hinuterteilen und wieder hochmultiplizieren.

Da die Tasten nur beim Wechsel zwischen an und aus abgefragt werden muss man den Taster bei niedrigen Frequenzen
einen Moment gedruckt haltem, bis sich die Blinkfrequenz ver ¨ | ändert.

Wenn der Sketch startet leuchtet die Lampe einmal pro Sekunde fur eine halbe Sekunde auf. Ein (langer) Druck auf ¨ den Taster an I2 halbiert die Wartezeit und die Lampe blinkt zweimal pro Sekunde. Nach einem zweiten Druck auf den Taster blinkt sie viermal usw. Nach dem sechsten Druck blinkt sie 32 mal pro Sekunde, was nur noch als leichtes Flackern wahrnehmbar ist und nach dem siebten Druck gar 64 mal. Frequenzen oberhalb ca. 50 Hertz kann das menschliche Auge nicht mehr auflösen und die Lampe scheint mit halber Helligkeit zu leuchten. Die Frequenz weiter zu erhöhen hat dann keinen erkennbaren Effekt mehr.

Aufgabe 1: Die träge Lampe

Es ist in diesem Aufbau nicht nur das menschliche Auge, das träge ist. Die Lampe ist ebenfalls träge. Es dauert eine Zeit,
bis sich ihr Gluhfaden aufheizt und die Lampe leuchtet und es dauert auch eine Zeit, bis sich der Gl ¨ | uhfaden wieder so weit ¨
abkuhlt, dass die Lampe nicht mehr leuchtet. ¨
Wesentlich schneller als Gluhlampen sind Leuchtdioden. In ihnen muss sich nichts aufheizen oder abk ¨ | uhlen, sondern das ¨
Licht entsteht direkt durch optoelektrische Effekte im Halbleitermaterial der Leuchtdiode. Schließt man statt der Lampe eine Leuchtdiode an (rot markierter Anschluss an Ausgang O1), dann sieht das Verhalten zunächst ähnlich aus und wieder scheint ab einer Frequenz von 64 Hertz die Leuchtdiode gleichmäßig mit halber Helligkeit zu leuchten. Viele Menschen nehmen 64 Hz allerdings noch als leichtes Flimmern wahr und erst ab 100Hz redet man von einer wirklich flimmerfreien Darstellung.

Man kann das Flimmern der Leuchtdiode aber auch bei diesen Frequenzen noch beobachten, wenn sich die Leuchtdiode bewegt. Nutzt man ein etwas längeres Kabel, so dass die Leuchtdiode sich frei bewegen lässt und bewegt sie dann in einer etwas abgedunkelten Umgebung schnell hin- und her, so wird der Eindruck einer Reihe von unterbrochenen Leuchtstreifen entstehen.

Abbildung 4.6: Muster bei schneller Bewegung der flackernden Leuchtdiode

Je höher die PWM-Frequenz ist, desto kurzer sind die sichtbaren Leuchtstreifen. ¨

Dieses Experiment kann man auch mit der Lampe wiederholen. Durch die Trägheit der Lampe sieht man nur einen durchgehenden Leuchtstreifen. Allerdings sollte man nicht allzu wild vorgehen, da der empfindliche Gluhfaden einer leuchtenden ¨ Lampe bei Erschutterung leicht kaputt geht. Leuchtdioden sind auch in dieser Beziehung robust und lassen sich selbst von ¨ starken Erschutterungen nicht beeindrucken. ¨

4.3. Pulsweitenmodulation | 35

Aufgabe 2: Töne aus dem Motor

Ein Motor ist ebenfalls träge und nicht in der Lage, beliebig schnellen An-/Aus-Signalen zu folgen. Schon bei recht niedrigen PWM-Frequenzen dreht sich der Motor kontinuierlich mit halber Drehzahl. Das dabei vornehmlich zu vernehmende Geräusch ist das Laufgeräusch des Motors.

Wenn man den Motor aber mechanisch blockiert, indem man ihn z.B. mit der Hand festhält, dann wirddas Laufgeräsch
unterdruckt und ein anderer Effekt wird h ¨ | örbar: Die Spulen im Motor wirken wie ein Lautsprecher und man kann die PWM-
Frequenz bei blockiertem Motor als Ton hören. Eine Veränderung der PWM-Frequenz hat dabei einen deutlich hörbaren Unterschied der Tonhöhe zur Folge.

Je höher die PWM-Frequenz, desto höher der am blockierten Motor hörbare Ton.

Aufgabe 3: Nachteil hoher PWM-Frequenzen

Im Fall der Lampe scheint eine höhere PWM-Frequenz ein reiner Vorteil zu sein, da das Flimmern mit höherer Frequenz abnimmt. Am Motor kann aber ein negativer Effekt beobachtet werden.

Läuft der Motor frei, so hängt die gehörte Tonhöhe des Motor-Laufgeräuschs mit seiner Drehgeschwindigkeit zusammen, während das PWM-Geräuch der vorigen Aufgabe in den Hintergrund tritt. Je schneller der Motor dreht, desto höher die Frequenz des Laufgeräuschs und umgekehrt.

Erhöht man nun die PWM-Frequenz, dann sinkt die Frequenz der Töne, die der Motor abgibt leicht. Er wird offensichtlich mit steigener PWM-Frequenz langsamer. Dieser Effekt ist damit zu erklären, dass der Motor eine sogenannte induktive Last darstellt. Er besteht im Wesentlichen aus Spulen, sogenannten Induktoren. Der Widerstand einer induktiven Last ist abhängig von der Frequenz einer angelegten Wechselspannung. Und nichts anderes ist das durch die PWM erzeugte An-/Aus-Signal. Je höher die Frequenz, desto höher der Widerstand der Spule und es fließt weniger Strom durch die Spule.

Es ist technisch möglich, die Ausgangsspannung zu glätten und diesen Effekt zu mildern. Diese Auslegung so einer Glättung ist allerdings von der verwendeten PWM-Frequenz und der Stromaufnahme des Motors abhängig. Außerdem beeinflusst sie das generelle Schaltverhalten des Ausgangs. Der Einsatz einer entsprechenden Glättung im ftDuino kommt daher nicht in
Frage, da die universelle Verwendbarkeit der Ausgänge dadurch eingeschr ¨ | änkt wurde. ¨

Ziel bei der Auswahl der PWM-Frequenz ist also eine Frequenz, die hoch genug ist, um Lampenflackern oder Motorstottern zu verhindern, die aber dennoch möglichst gering ist, um induktive Widerstände in den Wicklungen der Motoren zu minimieren. Eine PWM-Frequenz von 100-200Hz erfullt diese Bedingungen. ¨

Motordrehzahl in Abhängigkeit des PWM-Verhältnisses

Die Motordrehzahl lässt sich durch das Verhältnis der An- und Ausphasen während der Pulsweitenmodulation beeinflussen. In den bisherigen Versuchen waren die An- und Ausphase jeweils gleich lang. Verändert man das Verhältnis der beiden Phasen, dann lässt sich die Helligkeit einer Lampe oder die Drehzahl eines Motors steuern. Die PWM-Frequenz kann dabei konstant bleiben.

0%

25%

50%

75%

100%

Abbildung 4.7: Ausgewählte PWM-Verhältnisse von 0 bis 100%

Je länger die eingeschaltete Phase gegenuber der ausgeschalteten, desto heller leuchtet die Lampe und desto schneller ¨ dreht der Motor. Der genaue Zusammenhang zwischen Lampenhelligkeit und PWM-Verhältnis ist mangels entsprechender Messmöglichkeit nicht einfach festzustellen. Die sogenannten Encoder-Motoren haben aber eine eingebaute Möglichkeit zur Geschwindigkeitsmessung. Im Fall der TXT-Encodermotoren erzeugen diese Encoder 63 Signalimpulse pro Umdrehung der

36 | Kapitel 4. Experimente

Achse. Man kann also durch Auswertung der Encodersignale an den Zählereingängen des ftDuino die Drehzahl des Motors feststellen.

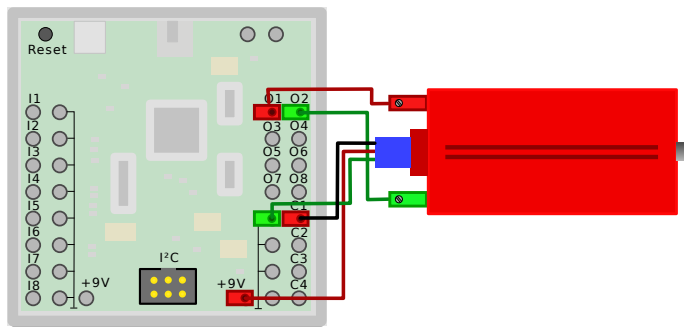
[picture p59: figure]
Reset; I²C

Abbildung 4.8: Anschluss des TXT-Encoder-Motors zur PWM-abhängigen Drehzahlmessung

Das Beispiel | Datei | . | Beispiele | . | Ftduino | . | PwmSpeed | regelt das An-/Ausverhältnis der PWM langsam von 0 auf
100% hoch und misst dabei kontinuerlich fur jeweils eine Sekunde die am Eingang ¨ | C1 anliegenden Impulse. Diese werden in
Umdrehungen pro Minute umgerechnet und ausgegeben. Dabei kommt die vollständige Bibliothek Ftduino zum Einsatz, die die eigentliche Erzeugung der PWM-Signale bereits mitbringt. Die Erzeugung des PWM-Signals passiert vollständig im Hintergrund, so dass der Sketch selbst lediglich den Motor startet und dann eine Sekunde wartet.

Speist man die so gewonnenen Daten in den sogenannten “seriellen Plotter”, der sich im Menu der Arduino-IDE unter ¨
Werkzeuge | . | Serieller Plotter | befindet, so kann man die Messergebnisse anschaulich visualisieren.

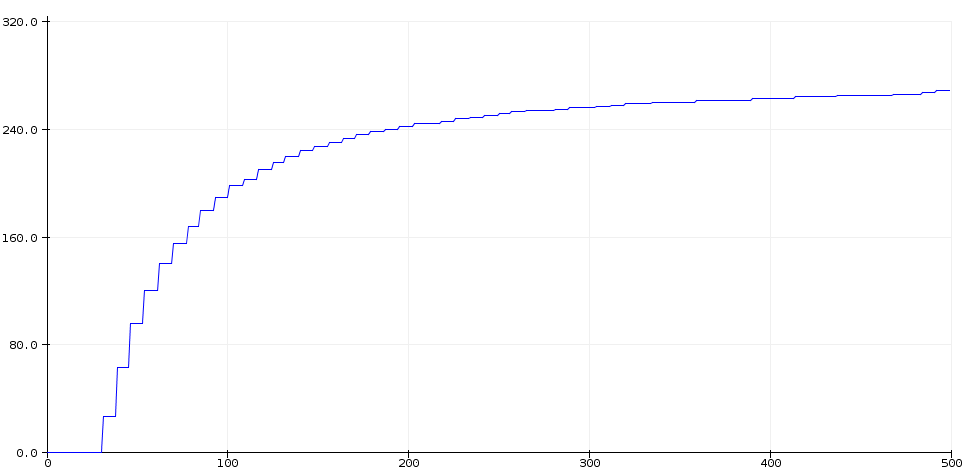
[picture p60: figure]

Abbildung 4.9: Leerlaufdrehzahl des TXT-Encoder-Motors in Abhängigkeit des PWM-Verhältnisses

Auf der horizontalen Achse ist das PWM-Verhältnis aufgetragen, beginnend mit “dauerhaft aus” ganz links bis “dauerhaft an” ganz rechts. Auf der vertikalen Achse ist die gemessene Drehzahl in Umdrehungen pro Minute dargestellt. Man sieht, dass der Zusammenhang im Leerlauf nicht linear ist. Bereits bei nur ca 25% der Zeit eingeschaltetem Signal wird 90% der maximalen Motordrehzahl erreicht.

Man kann z.B. indem man den Motor eine konstante Last anheben lässt nachprufen, wie sich diese Kurve und Last ver ¨ | ändert.

## 4.4 Die Eingänge des ftDuino

Schwierigkeitsgrad:

Wer sich schon einmal mit einem Arduino beschäftigt hat weiss, dass man dort relativ frei bestimmen kann, welche Anschlusse ¨ man als Ein- oder Ausgänge verwenden möchte, da sämtliche Pins am Microcontroller in der Richtung umgeschaltet werden

4.4. Die Eingänge des ftDuino | 37

können. Beim ftDuino konnte diese Fähigkeit nicht erhaltem werden, da an den Eingägen zusätzliche Schutzschaltungen
gegen Uberspannung und Kurzschl ¨ | usse eingesetzt werden und die Signale Ausg ¨ | änge verstärkt werden, um fischertechnik-
Lampen und -Motoren betreiben zu können.

1 kΩ

2,2 kΩ

Schalter

+5 Volt

Eingang Ox

Masse

47 kΩ

47 kΩ

Analog-Eingang
des ATmega32u4

Masse

Abbildung 4.10: Interne Beschaltung der Eingänge O1 bis O8 des ftDuino

Jeder der acht Eingänge I1 bis I8 des ftDuino fuhrt auf einen eigenen Analogeingang des ATmega32u4-Mikrocontrollers ¨ und kann von diesem unabhängig ausgewertet werden. Dazu kann der Mikrocontroller die Spannung des entsprechenden Eingangs messen.

### 4.4.1 Spannungsmessung

Bevor das Eingangssignal den Mikrocontroller erreicht wird es uber einen Spannungsteiler aus zwei 47-Kiloohm-Widerst ¨ | änden
gefuhrt. Diese Widerst ¨ | ände erfullen zwei Aufgaben. Erstens halbieren sie die Spannung eines angelegten Signals bevor es den ¨
Mikrocontroller erreicht. Da der Mikrocontroller ftDuino-intern mit 5 Volt betrieben wird und auch nur Signale im Bereich von 0 bis 5 Volt verarbeiten kann. Die Spannungshalbierung erweitert den messbaren Eingangsspannungsbereich auf 0 bis
10 Volt, wodurch sich die fischertechnik-ublichen Spannungen bis maximal 9 Volt verarbeiten lassen. Zum zweiten sch ¨ | utzen ¨
diese Widerstände im Zusammenspiel mit den Mikrocontroller-internen Schutzdioden den Mikrocontroller vor Spannungen,
die außerhalb des fur ihn vertr ¨ | äglichen 0 bis 5 Volt-Spannungsbereichs liegen. Spannungen bis zu 47 Volt an einem Eingang
beschädigen den Mikrocontroller daher nicht.

### 4.4.2 Widerstandsmessung

Die 1 kΩ- und 2.2 kΩ-Widerstände sowie der Schalter haben keine Bedeutung, solange der Schalter offen ist. Acht dieser
Schalter, je einer fur jeden Eingang, befinden sich im ¨ | ftDuino im Baustein mit der Bezeichnung CD4051 (IC1) wie im
Schaltplan in Anhang A ersichtlich. Der Mikrocontroller kann genau einen der acht Schalter zu jeder Zeit schließen und auf diese Weise einen Widerstand von insgesamt 3.2 kΩ (1 kΩ plus 2.2 kΩ) vom jeweiligen Eingang gegen 5 Volt aktivieren.

Der Schalter wird geschlossen und die Widerstände werden aktiviert, wenn eine Widerstandsmessung erfolgen soll. Der 3.2 kΩ-Widerstand bildet dann mit einem zwischen Eingang und Masse angeschlossenen externen Widerstand einen Spannungsteiler. Aus der gemessenen Spannung kann dann der unbekannte externe Widerstand bestimmt werden.

### 4.4.3 Ein Eingang als Ausgang

Die Tatsache, dass im Falle einer Widerstandsmessung ein Widerstand gegen 5 Volt geschaltet wird bedeutet, dass uber ¨ den zu messenden extern angeschlossenen Widerstand ein Stromkreis geschlossen wird. Der Strom durch diesen Stromkreis is relativ gering. Wenn der Eingang direkt mit Masse verbunden ist beträgt der Gesamtwiderstand 3.2 kΩ und es fließt ein Strom von I = 5V /3.2 kΩ = 1, 5625mA.

Dieser Strom reicht zwar nicht, um eine Lampe oder gar einen Motor zu betreiben. Aber eine Leuchtdiode kann man damit schwach zum Leuchten bringen. Schließt man eine Leuchtdiode direkt zwischen einem Eingang und Masse an und schaltet den Eingang auf Widerstandsmessung, so wird die LED ganz leicht leuchten.

38 | Kapitel 4. Experimente

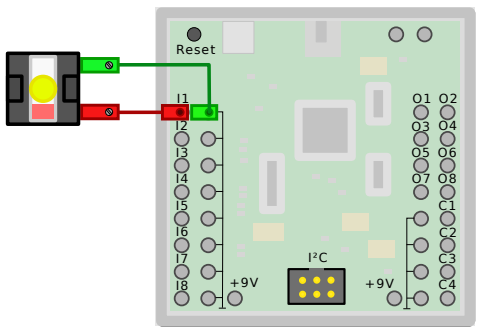
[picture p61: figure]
Reset; I²C

Abbildung 4.11: Anschluss einer LED an Eingang I1 des ftDuino

Der tatsächliche Strom wird noch deutlich unter den vorausgesagten 1,5mA liegen, da zum einen direkt an der Leuchtdiode
die sogenannte Vorwärtsspannung von ca. 0,7V abfällt und uber den Widerst ¨ | änden daher nur eine Spannung von etwas uber ¨
vier Volt anliegt.

Zum anderen fragt die Ftduino-Bibliothek im Hintergrund alle acht Eingänge ab und aktiviert jeden Eingang dabei nur 1/8 der Zeit. Es fließt im Mittel daher auch nur 1/8 des Stroms.

Die FtduinoSimple-Bibliothek schaltet ebenfalls die Widerstände ein und zwar fur den jeweils zuletzt aktivierten Eingang. ¨ Dieser Widerstand ist dann dauerhaft aktiviert, bis ein anderer Eingang angefragt wurd. Das folgenden Code-Fragment lässt eine LED an Eingang I1 im Sekundentakt blinken.

1 # include < FtduinoSimple .h >
2
3 | void loop () {
4 | // lies Wert von Eingang I1 , aktiviert Widerstand auf I1
5 | ftduino . input_get ( Ftduino :: I1) ;
6 | delay (1000) ;
7 | // lies Wert von Eingang I2 , deaktiviert Widerstand auf I1
8 | // ( und aktiviert ihn auf I2)
9 | ftduino . input_get ( Ftduino :: I2) ;
10 | delay (1000) ;
11 | }

## 4.5 Ausgänge an, aus oder nichts davon?

Schwierigkeitsgrad:

Einen Ausgang kann man ein- oder ausschalten, das ist die gängige Sichtweise. Dass es aber noch einen weiteren Zustand gibt ist auf den ersten Blick vielleicht nicht offensichtlich.

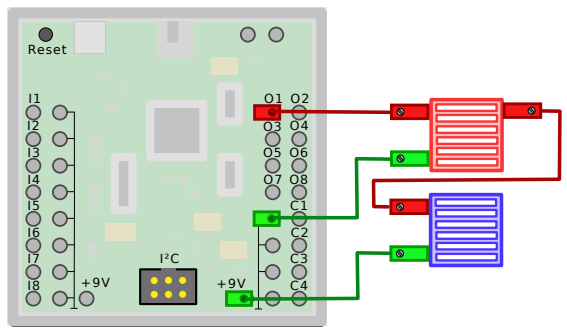
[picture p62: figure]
Reset; I²C

Abbildung 4.12: Zwei Lampen an Ausgang O1

4.6. Aktive Motorbremse | 39

Die Ausgänge des ftDuino lassen sich in drei Zustände schalten: Ftduino::HI, Ftduino::LO und Ftduino::OFF.

Am offensichtlichsten ist der Zustand Ftduino::HI. In diesem Zustand wird der entsprechende Ausgang ftDuino-intern mit der 9-Volt-Versorgungspannung verbunden. Ist an diesem Ausgang eine Lampe oder ein Motor so angeschlossen, dass der zweite Anschluss an Masse liegt, so fließt ein Strom von der 9V-Quelle uber den Ausgang durch Lampe oder Motor zur ¨ Masse. Der Motor dreht sich und die Lampe leuchtet. Im abgebildeten Beispiel leuchtet die rote Lampe.

Im Zustand Ftduino::LO ist der entsprechende Ausgang mit Masse verbunden. Eine wieder mit dem zweiten Anschluss an Masse angeschlossene Lampe wird nun nicht mehr leuchten, da beide Anschlusse der Lampe auf Masse liegen und die ¨
Spannung zwischen beiden Anschlussen daher 0 Volt betr ¨ | ägt. Schließt man den zweiten Anschluss der Lampe aber an 9
Volt an, so leuchtet sie nun. Der Strom fließt von der Spannungsversorung des ftDuino uber den 9-V-Anschluss, durch die ¨ Lampe und schließlich uber den auf Masse liegenden Ausgang. Im abgebildeten Beispiel leuchtet nun die blaue Lampe. ¨

Der dritte Zustand ist schließlich der Zustand Ftduino::OFF. In diesem Fall ist der Ausgang komplett offen. Er ist weder mit Masse noch mit 9 Volt verbunden und es fließt kein Strom uber ihn. Als Resultat leuchtet nun weder die rote noch die ¨ blaue Lampe. Dieser Zustand wird oft auch mit dem englischen Begriff “tristate” bezeichnet und entsprechende Ausgänge an Halbleitern als “tristate-fähig”. Im Deutschen beschreibt der Begriff “hochohmig” diesen dritten Zustand recht gut.

Der folgende Sketch wechselt im Sekundentakt zwischen den drei Zuständen. Man kann diesen Effekt zum Beispiel ausnutzen, um zwei Motoren oder Lampen an einem Ausgang unabhängig zu steuern, um Ausgänge zu sparen. Allerdings lassen sich bei dieser Verschaltung niemals beide Lampen gleichtzeitig auf voller Helligkeit betreiben.

4.5.1 Sketch OnOffTristate (https://github.com/harbaum/ftduino/tree/master/ftduino/libraries/FtduinoSimple/examples/OnOffTristate)

/*
OnOffTristate - der dritte Zustand */

# include < FtduinoSimple .h >

void setup () { }

// Die Loop - Funktion wird endlos immer und immer wieder ausgef ü hrt void loop () {
// Ausgang O1 auf 9V schalten
ftduino . output_set ( Ftduino ::O1 , Ftduino :: HI);
delay (1000) ;
// Ausgang O1 auf Masse schalten
ftduino . output_set ( Ftduino ::O1 , Ftduino :: LO); delay (1000) ;
// Ausgang O1 unbeschaltet lassen
ftduino . output_set ( Ftduino ::O1 , Ftduino :: OFF ); delay (1000) ;
}

### 4.5.2 Leckströme

Ganz korrekt ist die Aussage, dass im hochohmigen bzw. Tristate-Zustand kein Strom fließt nicht. Uber die Leistungsend- ¨ stufen und deren interne Schutzschaltungen fließt oft trotzdem ein geringer Strom. In einigen Fällen wird dies sogar bewusst getan, um z.B. mit Hilfe dieses geringen Stromflusses das Vorhandensein eines angeschlossenen Verbauchers feststellen zu können. Diese sogenannten Leckströme wurden in Abschnitt 4.1.1 bereits beobachtet.

Ersetzt man die zwei Lampen im aktuellen Modell durch zwei Leuchtdioden, so wird man feststellen, dass die vom Ausgang nach Masse angeschlossene LED immer dann leicht glimmt, wenn der entsprechende Ausgang hochohmig geschaltet ist. Nur wenn der Ausgang auf Masse geschaltet ist leuchtet die LED nicht. Man kann also direkt an der LED die drei Zustände unterscheiden.

## 4.6 Aktive Motorbremse

Schwierigkeitsgrad:

40 | Kapitel 4. Experimente

Das Abschalten eines Motors scheint rein elektrisch trivial zu sein. Sobald der Motor von der Spannungsversorung getrennt wird bleibt er stehen. Im Wesentlichen stimmt das auch so.

Physikalisch bedeutet die Trennung von der Spannungsversorung lediglich, dass dem Motor keine weitere Engergie zugefuhrt ¨
wird. Dass das letztlich dazu fuhrt, dass der Motor anh ¨ | ält liegt daran, dass die in der Rotation des Motors gespeicherte
Energie langsam durch Reibung z.B. in den Lagern der Motorwelle verloren geht. Wie lange es dauert, bis der Motor auf diese Weise zum Stillstand kommt hängt wesentlich vom Aufbau des Motors und der Qualität seiner Lager ab.

Zusätzlich wirken viele Gleichstrom-Elektromotoren, wie sie auch fischertechnik einsetzt, als Generator. Werden sie gedreht, so wird in ihren internen Elektromagneten eine Spannung induziert.

Abbildung 4.13: Der TXT-Encoder-Motor als Generator

Dieser Effekt lässt sich mit einer Leuchdiode leicht nachvollziehen. Schließt man die Leuchtdiode direkt an den Motor an und dreht dann manuell die Motorachse, so leuchtet die Leuchtdiode auf, wenn man den Motor in die richtige Richtung
dreht und damit eine Spannung mit der fur die Leuchtdiode passenen Polarit ¨ | | ät erzeugt. Man kann fur diesen Versuch auch ¨
eine Gluhlampe oder gar einen zweiten Motor nehmen. Deren gegen ¨ | uber einer Leuchtdiode h ¨ | öhere Energieaufnahe erfordert
aber ggf. ein etwas kräftigeres Drehen.

Je mehr Last ein Generator versorgen soll und je mehr Energie im entnommen werden soll, desto größer ist die mechanische Kraft, die nötig ist, um den Generator zu drehen. Höhere Last bedeutet in diesem Fall ein geringerer elektrischer Widerstand. Die Leuchtdiode mit ihrer verleichsweise geringen Last besitzt einen hohen elektrischen Widerstand, die Gluhlampe und noch ¨ mehr der Motor besitzen einen geringen elektrischen Widerstand und belasten bzw. bremsen den Generator damit stärker. Die größte denkbare Last ist in diesem Fall der Kurzschluss. Er hat einen minimalen elektrischen Widerstand und sorgt fur ¨ maximalen Stromfluss und damit maximale elektrische Last am Generator. Auch die Bremswirkung ist dabei maximal.
M | M
gebremst | ungebremst

Abbildung 4.14: Elektrisch gebremster und ungebremster Elektromotor

Dieser Effekt lässt sich nutzen, um einen Elektromotor zu bremsen. Wende beide Anschlusse eines Motors miteinander ¨ verbunden, so fließt ein Strom, der eine Bremswirkung entwickelt. Das wurde bereits beim Not-Aus-Modell aus Abschnitt 4.2 genutzt, um den Motor im Notfall schnell zu stoppen. Ist dagegen z.B. einer der Anschlusse des Motors offen, so ist ¨ kein geschlossener Stromkreis vorhanden und es fließt kein Strom und es tritt keine Bremswirkung auf. Wie groß ist dieser Effekt aber?

Der fischertechnik-Encoder-Motor enthält eine Möglichkeit zur Drehzahlmessung wie schon im PWM-Experiment in Abschnitt 4.3 genutzt. Das Bremsverhalten dieses Motors lässt sich daher experimentell gut verfolgen.

Das Beispiel | Datei | . | Beispiele | . | Ftduino | . | MotorBrake | lässt den Motor an Ausgang M1 alle funf Sekunden f ¨ | ur drei ¨
Umdrehungen laufen und misst dann fur eine weitere Sekunde, wieviele weitere Impule der Encoder an Eingang ¨ | C1 liefert,
nachdem er die drei Umdrehungen vollendet hat und abgeschaltet wurde.

Die Funktion motor counter set brake() (siehe Abschnitt 7.2.9) wird dabei im Wechsel so eingerufen, dass der Motor frei ausläuft bzw. dass er aktiv gebremst wird.

Wie in Abbildung 4.16 zu sehen macht die aktive Bremse einen deutlichen Unterschied. Während der Encoder-Motor ungebremst noch fur weitere 90 Impulse weiter dreht, also fast 1,5 volle Umdrehungen, kommt er bei aktiber Bremse bereits ¨

4.7. USB-Tastatur | 41

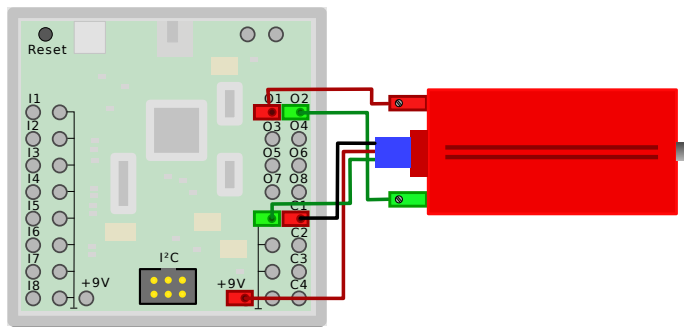
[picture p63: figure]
Reset; I²C

Abbildung 4.15: Anschluss des TXT-Encoder-Motors an die Anschlusse ¨ | M1 und C1

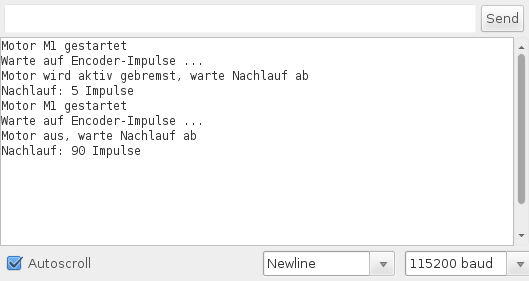
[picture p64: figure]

Abbildung 4.16: Ausgabe bei Verwendung des TXT-Encoder-Motors

nach funf weiteren Impulse zum Stillstand. Das entspricht lediglich knapp ¨ | 1/13 Umdrehung.

## 4.7 USB-Tastatur

Schwierigkeitsgrad:

Der ftDuino ist nicht vom klassischen Arduino Uno abgeleitet, sondern vom Arduino Leonardo. Der wesentliche technische Unterschied zwischen beiden Arduinos liegt in der Tatsache, dass der Arduino Uno einen seperaten Chip fur die ¨ USB-Kommunikation mit dem PC verwendet, während diese Aufgabe beim Arduino Leonardo allein dem ATmega32u4-Mikrocontroller zufällt.

In den meisten Fällen macht das keinen Unterschied und die meisten Sketches laufen auf beiden Arduinos gleichermaßen. Es gibt allerdings sehr große Unterschiede in den Möglichkeiten, die sich mit beiden Arduinos bei der USB-Anbindung bieten. Während der USB-Chip im Uno auf das Anlegen eines COM:-Ports beschränkt ist zeigt sich der Leonardo und damit auch der ftDuino sehr viel flexibler und der ftDuino kann sich unter anderem gegenuber einem PC als USB-Tastatur ausgeben. ¨

Da die Ausgänge des ftDuino bei diesem Modell nicht verwendet werden reicht die Stromversorung uber USB und es ist ¨
keine weitere Versorung uber Batterie oder Netzteil n ¨ | ötig.

4.7.1 Sketch USB/KeyboardMessage (https://github.com/harbaum/ftduino/tree/master/ftduino/libraries/FtduinoSimple/examples/USB/KeyboardMessage)

1 | /*
2 | KeyboardMessage - USB - Tastatur
3
4 | Der ftDuino gibt sich als USB - Tastatur aus und " tippt " eine Nachricht , sobald
5 | ein Taster an Eingang I1 für mindestens 10 Millisekunden gedr ückt wird .
6

42 | Kapitel 4. Experimente

Abbildung 4.17: Tastatur-Nachricht

7 | Basierend auf dem Sketch :
8 | http :// www . arduino .cc/en/ Tutorial / KeyboardMessage
9
10 | Dieser Beispielcode ist Public - Domain .
11 | */
12
13 | # include < FtduinoSimple .h >
14 | # include < Keyboard .h >
15
16 | unsigned long lastButtonEvent = 0;
17 | uint16_t previousButtonState = Ftduino :: OFF ; | // for checking the state of a pushButton
18
19 | void setup () {
20 | // initialize control over the keyboard :
21 | Keyboard . begin () ;
22 | }
23
24 | void loop () {
25 | // Taste an Eingang I1 auslesen
26 | uint16_t buttonState = ftduino . input_get ( Ftduino :: I1);
27
28 | // Hat sich der Zustand der Taste geä ndert ?
29 | if( buttonState != previousButtonState ) {
30 | // ja , Zeit des Wechsels merken
31 | lastButtonEvent = millis () ;
32 | // und den neuen Zustand merken , damit wir weitere
33 | // Ä nderungen erkennen kö nnen
34 | previousButtonState = buttonState ;
35 | }
36
37 | // Gibt es ein unbearbeitetes Eregnis und hat sich der Zustand der Taste seitdem
38 | // für mehr als 10 Millisekunden nicht geä ndert ?
39 | if( lastButtonEvent && (( millis () - lastButtonEvent ) > 10) ) {
40 | // Zeit dieses Ereignisses vergessen
41 | lastButtonEvent = 0;
42
43 | // Taste wurde gedr ü ckt
44 | if( buttonState ) {
45 | // Nachricht " tippen "
46 | Keyboard . println (" Hallo vom ftDuino !");
47 | }
48 | }
49 | }

Sketchbeschreibung

Die Arduino-IDE bringt bereits Bibliotheken mit, um USB-Geräte wie Mäuse und Tastaturen umzusetzen. Der eigentliche Sketch bleibt so sehr einfach und die komplizieten USB-Detail bleiben in den Bibliotheken verborgen. Entsprechend kurz ist auch dieser Sketch.

In der setup()-Funktion muss lediglich die Methode Keyboard.begin() aufgerunfen werden, um beim Start des ftDuino

4.8. USB-GamePad | 43

alle USB-settigen Vorkehrungen zu treffen, so dass der ftDuino vom PC als USB-Tastatur erkannt wird. Allerdings verfugt ¨
diese Tastatur zunächst uber keine Tasten, so dass man kaum merkt, dass der PC nun ¨ | uber eine zus ¨ | ätzliche Tastatur zu
verfugen meint. ¨
Um die Tastatur mit Leben zu fullen muss in der ¨ | loop()-Funktion bei Bedarf ein entsprechendes Tastensignal erzeugt und
an den PC gesendet werden. In den Zeilen 25 bis 35 des Sketches wird ein Taster an Eingang I1 abgefragt und sichergestellt,
dass nur Tastendrucke ¨ | uber 10ms L ¨ | änge als solche erkannt werden (mehr Details zu diesem sogenannten Entprellen findet
sich in Abschnitt 4.9).
Immer wenn die Taste an I1 gedruckt wurde, werden die Sketchzeilen 45 und folgende ausgef ¨ | uhrt. Hier wird die Funktion ¨
Keyboard.println() aus der Arduino-Keyboard-Bibliothek aufgerufen und ein Text an den PC gesendet. Fur den PC sieht ¨ es so aus, als wurde der Text vom Anwender auf der Tastatur getippt ¨

1

Die Möglichkeit, Nachrichten direkt als Tastatureingaben zu senden kann sehr praktisch sein, erlaubt sie doch ohne weitere
Programmierung auf dem PC, die automatische Eingabe z.B. vom Messwerten in eine Tabelle oder ähnlich. Naturlich l ¨ | ässt
sich diese Fähigkeit aber auch fur allerlei Schabernack nutzen, indem der ¨ | ftDuino zeitgesteuert oder auf andere Ereignisse
reagierend den uberraschten Anwender mit unerwarteten Texteingaben irritiert. Bei solchen Sp ¨ | äßen sollte man immer eine
ordentliche Portion Vorsicht walten lassen, da der falsche Tastendruck zur falschen Zeit leicht einen Datenverlust zur Folge haben kann.
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

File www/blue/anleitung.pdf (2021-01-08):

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

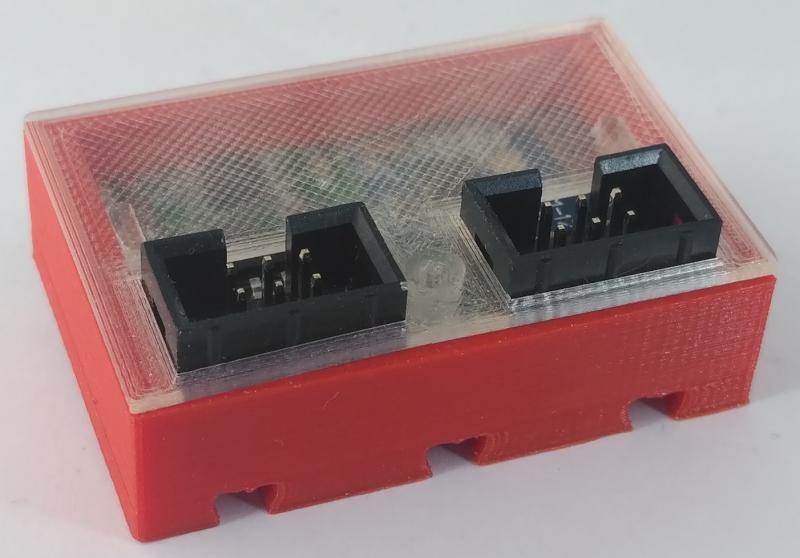
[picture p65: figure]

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

# Kapitel 1

# Einleitung

Der ftDuino ist eine Bluetooth-Erweiterung für den ftDuino. Der ftDuino (siehe http://ftduino.de) ist ein Arduinokompatibler Controller für das schertechnik-Konstruktionsbaukastensystem.

Der ftDuino verfügt aber Werk über eine USB-Schnittstelle zur kabelgebundenen Verbindung zu vorrangig einem PC. Der ftDuino-Bluetooth-Adapter erweitert den ftDuino um eine drahtlose Bluetooth-Schnittstelle, über die der ftDuino kabellos vor allem mit Smartdevices gekoppelt werden kann. Typische Anwendung ist die drahtlose Fernsteuerung eines schertechnik-Modells mit Hilfe einer App auf Apple-IOS- oder Google-Android-basierten Smartdevices.

Der ftDuino-Bluetooth-Adapter basiert auf Bluetooth-Low-Energy (BLE) und ist damit primär mit Mobilgeräten kompatibel. Diverse Apps aus den gängigen App-Stores für Mobilgeräte (Apple-Store, Google-Play-Store) sind mit dem ftDuino-Bluetooth-Adapter kompatibel.

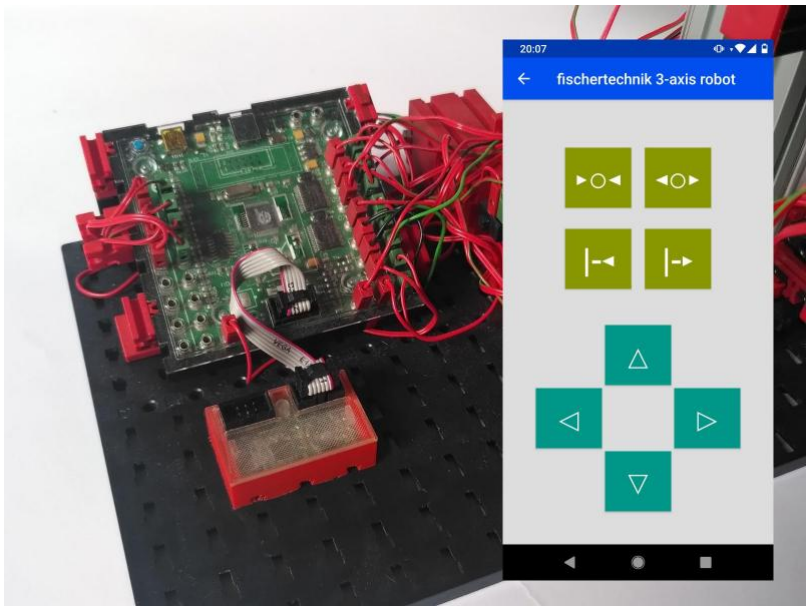
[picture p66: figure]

Abbildung 1.1: ftDuino-Bluetooth-Adapter und ftDuino im Robotermodell

# Kapitel 2

# Der Adapter

Der ftDuino-Bluetooth-Adapter wird als Fertiggerät geliefert. Er wird an den I²C-Erweiterungsanschluss des ftDuino angeschlossen und stellt seinerseits einen weiteren I²C-Anschluss für die Verbindung weiterer I²C-Erweiterungen zur Verfügung. Beide I²C-Anschlüsse des ftDuino-Bluetooth-Adapters sind gleichberechtigt und können beliebig zum Anschluss an den ftDuino oder andere Erweiterungen verwendet werden.

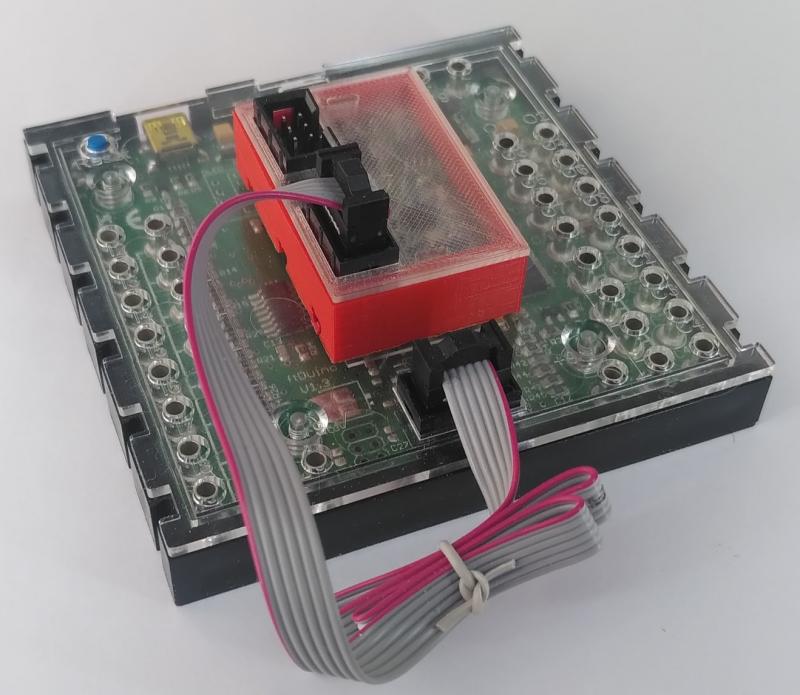
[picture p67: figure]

Abbildung 2.1: ftDuino-Bluetooth-Adapter am ftDuino

Der ftDuino-Bluetooth-Adapter wird inklusive schertechnik-kompatiblem Gehäuse und passendem Anschlusskabel für den ftDuino ausgeliefert. Der Adapter kann mit Hilfe zweier schertechnik-Federnocken sowohl direkt auf dem ftDuino befestigt werden. Er kann aber auch mit Hilfe des 25cm langen Kabels an beliebiger anderer Stelle im Modell montiert werden.

6 | Kapitel 2. Der Adapter
2.1 | Bluetooth-Chip

Der ftDuino-Bluetooth-Adapter basiert auf dem HM-11-Bluetooth-Modul. Das HM-11-Modul ist wiederum eine mechanisch kleinere Variante des bekannten HM-10-Moduls.

Das HM-10 ist in der Arduino-Community weit verbreitet und wird von zahlreichen Projekten verwendet. Passende Software für gängige Smart-Device-Betriebssysteme sind in den App-Stores unter dem Stichwort HM-10 zu nden.

Die meiste für das HM-10 geschriebene Software lässt sich auch mit dem HM-11 und damit mit dem ftDuino-Bluetooth-Adapter nutzen (siehe Kapitel 3). Die meisten für den Arduino und das HM-10-Modul geschriebenen Sketches lassen sich leicht an den ftDuino und den ftDuino-Bluetooth-Adapter anpassen (siehe Kapitel 4).

Für einige Smartdevice-Apps liefert die ftDuino-Einrichtung in der Arduino-IDE unter | Datei | . | Beispiele | . | Ftduino | .
Bluetooth | . | ftDuino-Bluetooth | bereits einige Beispiele mit.
2.2 | Leuchtdiode

Der Adapter selbst verfügt über keine Bedienelemente, sondern lediglich über eine rote Leuchtdiode, über die der Betriebszustand angezeigt wird. Sie blinkt einmal pro Sekunde, wenn das Bluetooth-Modul empfangsbereit ist und sie leuchtet durchgängig, wenn eine Bluetooth-Verbindung zu einem anderen Gerät besteht.

# Kapitel 3

# Software

Eine Nutzung des ftDuino-Bluetooth-Adapters am ftDuino erfordert einen passenden Sketch und eine dazugehörige Smartdevice-App. Beides kann man selbst entwickeln oder aber auf vorgefertigte Lösungen zurückgreifen. Dieses Kapitel stellt einige solche Lösungen vor. Weitere und ähnliche Projekte nden sich im Internet und sind in der Regel leicht an den ftDuino-Bluetooth-Adapter anpassbar.

Die hier dargestellten Beispiele nutzen alle die gleichen Art der softwareseitigen Einbindung des ftDuino-Bluetooth-Adapters in den jeweiligen Beispielsketch. Diese Einbindung überprüft bei Sketchstart die Verbindung zum Bluetooth-Modul und zeigt ein Problem durch schnelles Blinken der ftDuino-internen Leuchtdiode an. Die Leuchtdiode im ftDuino-Bluetooth-Adapter zeigt dagegen durch langsames Blinken die Verbindungsbereitschaft an.

Von den im Folgenden dargestellten Lösungen bietet ArduinoBlue den einfachsten Einstieg und eignet sich für die ersten Schritte mit dem ftDuino-Bluetooth-Adapter.

## 3.1 ArduinoBlue

ArduinoBlue (https://sites.google.com/stonybrook.edu/arduinoble/home) ist eine kostenlose und werbefreie Smartdevice-App, die für Apple-IOS und Android verfügbar ist sowie einer Arduino-Bibliothek, die über den Bibliotheks-Verwalter in der Arduino-IDE installiert werden kann.

ArduinoBlue ist für die Verwendung mit dem HM-10-Modul entwickelt worden und funktioniert damit auch uneingeschränkt mit dem ftDuino-Bluetooth-Adapter verwendbar.

Unter | Datei | . | Beispiele | . | Ftduino | . | Bluetooth | . | ftDuino-Bluetooth | . | ArduinoBlue | ndet sich in der Arduino-
IDE ein fertig an den ftDuino-Bluetooth-Adapter angepasstes Beispiel. Es kann unverändert auf den ftDuino geladen werden. Das Beispiel bildet die zwei Achsen des On-Screen-Joysticks in ArduinoBlue auf zwei Motoren an den ftDuino-Ausgängen M1 und M2 ab.

ArduinoBlue eignet sich mit dem On-Screen-Joystick vor allem zur Steuerung von Fahrzeugen. Es können aber auch benutzerdenierte Schaltächen (Buttons) und Schieberegler (Slider) eingerichtet werden, über die eine universellere Nutzung möglich ist.

## 3.2 1Sheeld

OneSheeld (https://www.1sheeld.com/) besteht wie ArduinoBlue aus einer für IOS und Android kostenlos verfügbaren App sowie einer dazugehörigen Arduino-Bibliothek. OneSheeld bietet dem Arduino virtuelle Shields in Form von Tastenfeldern, Anzeigen etc. auf dem Smartdevice-Bildschirm. Diese sollen reale Tastenfelder, Anzeigen u.ä. ersetzen.

OneSheeld vertreibt dazu ein spezielles Sheeld, das auf den Arduino aufgesteckt wird und einen Kommunikationsprozessor sowie den Bluetooth-Chip enthält.

8 | Kapitel 3. Software

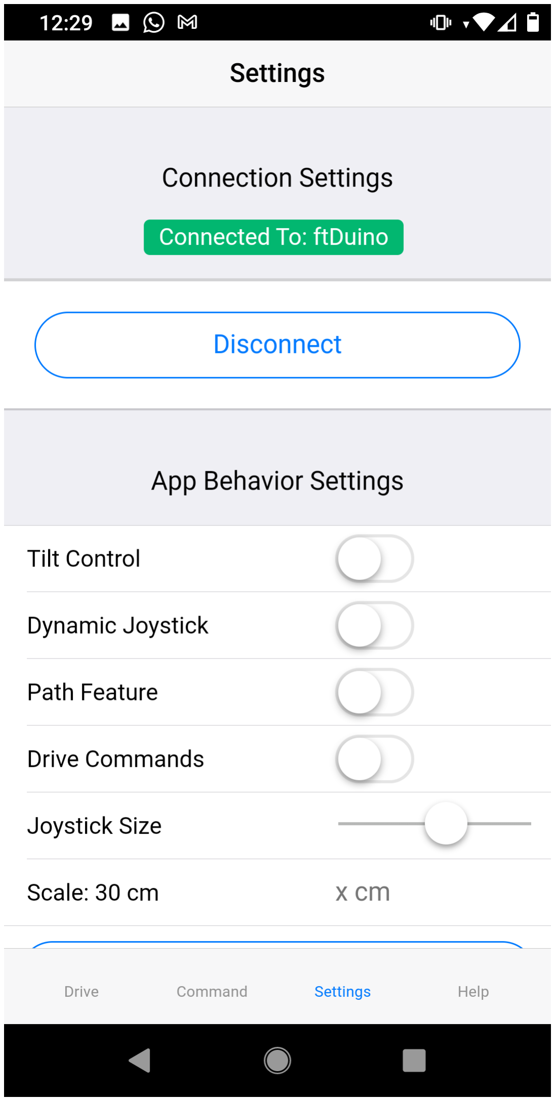
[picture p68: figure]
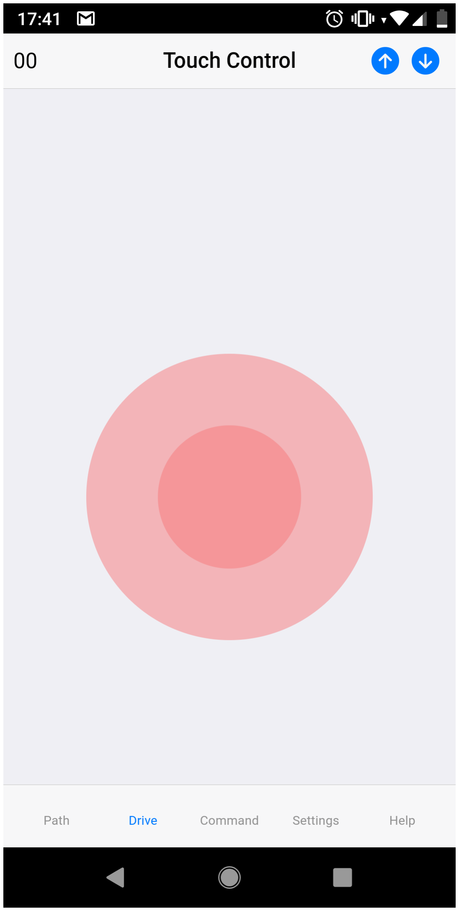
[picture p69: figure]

(a) Verbindung | (b) On-Screen-Joystick

Abbildung 3.1: ArduinoBlue

Im ftDuino-Beispielsketch zum OneSheeld unter | Datei | . | Beispiele | . | Ftduino | . | Bluetooth | . | ftDuino-Bluetooth | .
1Sheeld | übernimmt eine Arduino-Bibliothek die Rolle des Kommunikationsprozessors und der ftDuino-Bluetooth-Adapter
die Rolle des Bluetooth-Moduls. Damit die OneSheeld-App den ftDuino-Bluetooth-Adapter erkennt, muss der Gerätename mit der Zeichenfolge 1Sheeld beginnen. Der Name lässt sich z.B. mit Hilfe des Bluetooth-Cong-Sketches (siehe 3.5) entsprechend einstellen.

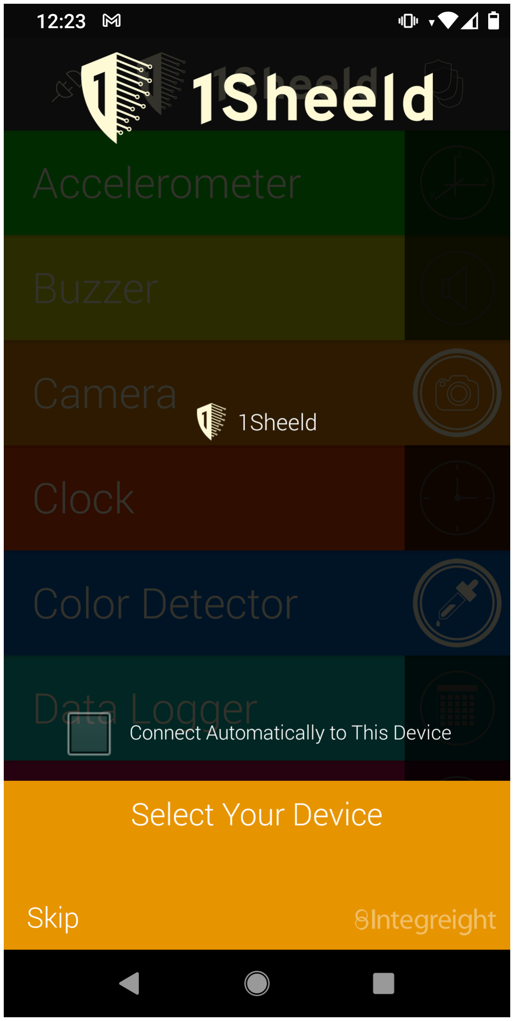
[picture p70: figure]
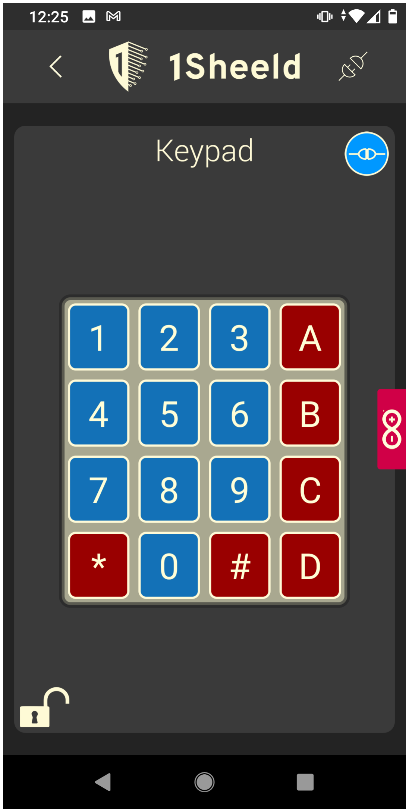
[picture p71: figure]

(a) Verbindung | (b) Virtuelles Keypad

Abbildung 3.2: OneSheeld

Der Beispiel-Sketch verwendet des virtuelle Keypad-Shield der OneSheeld-App, um die Ausgänge O1 bis O8 des ftDuino anzusteuern. Ein Druck auf die Tastenfelder 1 bis 8 des Keypads schaltet die entsprechenden Ausgänge des ftDuino ein bzw. wieder aus.

3.3. ftDuinoBlue | 9
3.3 | ftDuinoBlue

ArduinoBlue und OneSheeld ist gemeinsam, dass man passende Einstellungen in der Smartdevice-App und im ftDuino-Sketch vornehmen muss. Das hat u.a. den Nachteil, dass man nicht einfach zwischen mehreren Modellen wechseln kann, sondern bei jedem Wechsel in der App die entsprechenden Anpassungen vornehmen muss. Auÿerdem ist man in der Regel auf einige wenige von der App vorgegebene Steuerelemente beschränkt.

ftDuinoBlue (http://ftduino.de/blue) ist der Versuch, diese Beschränkungen zu umgehen. Dazu ndet in der bisher nur für Android verfügbaren App keinerlei Einstellungen statt. Stattdessen gibt es im Sketch erweiterte Einstellungen, die neben der Funktion des ftDuino auch die gewünschte Benutzeroberäche auf dem Handy beschreiben. Sobald sich die App dann mit dem Modell verbindet liest es die gewünschte Benutzeroberäche aus und stellt sie entsprechend dar.

Die Vorteile dieser Lösung sind, dass man beliebig zwischen Modellen wechseln kann und sich die Benutzeroberäche auf dem Smartdevice immer entsprechend anpasst. Auÿerdem lassen sich die Benutzeroberächen sehr exibel aus einer Vielzahl von Bedienelementen (Schalter, Knöpfe, Schieber, Texte, ...) zusammenstellen.

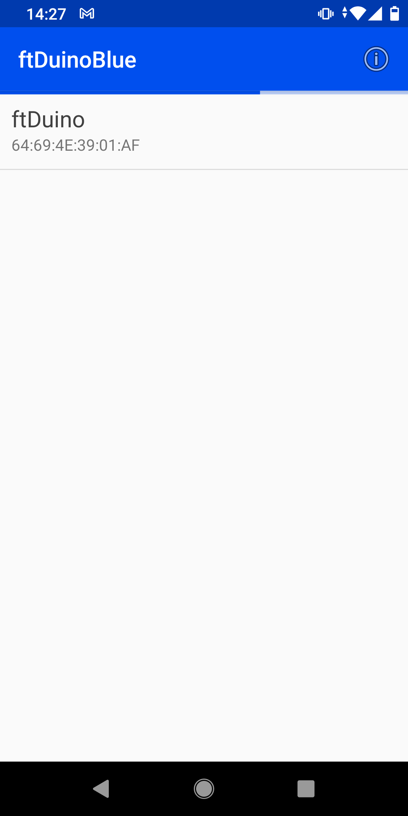
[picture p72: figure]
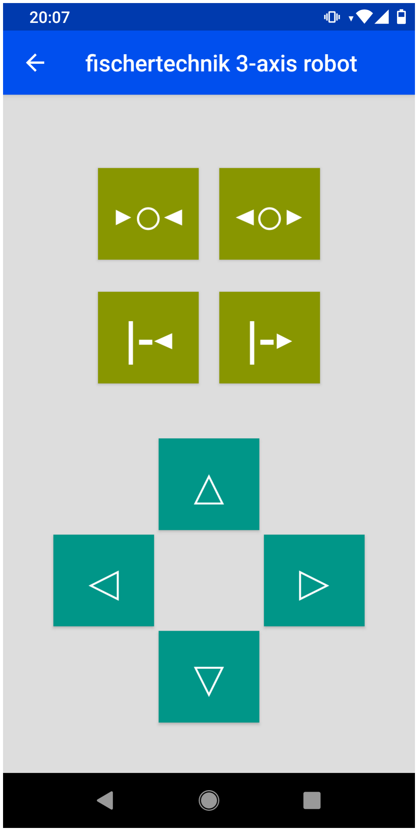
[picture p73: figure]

(a) Verbindung | (b) 3-Achs-Roboter

Abbildung 3.3: ftDuinoBlue

Der Nachteil ist die etwas aufwändigere Erstellung des Sketches, in dem man neben der eigentlichen Funktion des Modells auch die Benutzeroberäche hinterlegen muss. Mehr Erklärungen dazu nden sich unter http://ftduino.de/blue.

Ein einfacher Beispielsketch ndet sich unter | Datei | . | Beispiele | . | Ftduino | . | Bluetooth | . | ftDuino-Bluetooth | .
ftduinoblue_demo | . Ein komplexes Beispiel zur Steuerung des 3-Achs-Roboters aus dem schertechnik Automation-
Robots-Baukasten | ndet | sich | unter | Datei | . | Beispiele | . | Ftduino | . | Bluetooth | . | ftDuino-Bluetooth | .
txt_automation_3axis | .
3.4 | Serial Bluetooth Terminal

Neben den spezialisierten Apps gibt es auch allgemeine Kommunikationsprogramme für Smartdevices. Die Android-App Serial Bluetooth Terminal ist ein Beispiel dafür. Vergleichbare Programme gibt es auch für Apple-IOS.

Diese sogenannten Terminalprogramme stellen wenig eigene Funktionalität bereit, stattdessen stellen sie alle via Bluetooth empfangenen Zeichen direkt auf dem Bildschirm des Smartdevice dar. In Gegenrichtung werden alle am Smartdevice gemachten (Onscreen-)Tastatureingaben über Bluetooth versendet. Vor allem für einfache Tests und Experimente ist diese direkte Kommunikation gut geeignet.

10 | Kapitel 3. Software

Nutzt man im Sketch eine einfache Text-Kommando-orientierte Steuerung, so lassen sich auch mit einem Terminalprogramme eigene Modelle steuern.

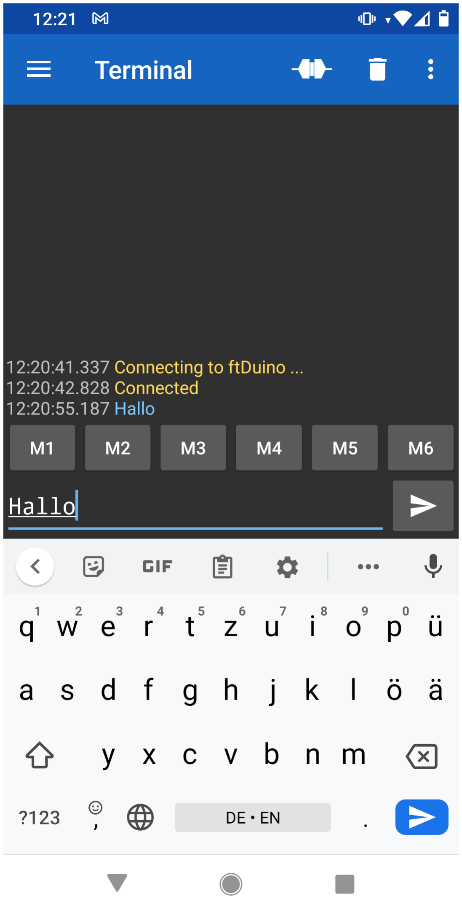
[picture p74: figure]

Abbildung 3.4: Serial Terminal unter Android

Als Gegenseite bietet sich der Sketch | Datei | . | Beispiele | . | Ftduino | . | Bluetooth | . | ftDuino-Bluetooth | . | Bridge | an.
Er stellt ebenfalls kaum eigene Funktion bereit, sondern veranlasst den ftDuino alle via Bluetooth empfangenen Zeichen über USB an den angeschlossenen PC zu senden. Um Gegenzug sendet dieser Sketch alle vom PC über USB empfangen Daten über Bluetooth.

Nutzt man PC-seitig z.B. den Seriellen Monitor der Arduino-IDE, so werden alle Texteingaben dort zunächst per USB zum ftDuino und dann über Bluetooth zur Terminal-App auf dem Smartdevice übertragen. Am PC eingegeben Texte erscheinen also auf dem Bildschirm des Smartdevices. In der Gegenrichtung funktioniert es ähnlich und alle am Smartdevice eingegebenen Zeichen erscheinen als Ausgabe im Textfenster des Seriellen Monitors.

## 3.5 Bluetooth-Kongurations-Werkzeug

Im Inneren des ftDuino-Bluetooth-Adapter steckt ein HM-11-Bluetooth-Modul. Dieses Modul hat weitreichende Einstellungsmöglichkeiten. Die meisten davon sind für die Verwendung am ftDuino von geringer Bedeutung. Eine interessante Möglichkeit ist es aber, den Gerätenamen ändern zu können. Vor allem wenn man über mehrere ftDuinos und passende ftDuino-Bluetooth-Adapter verfügt kann man die Module durch Umbenennung unterscheidbar machen.

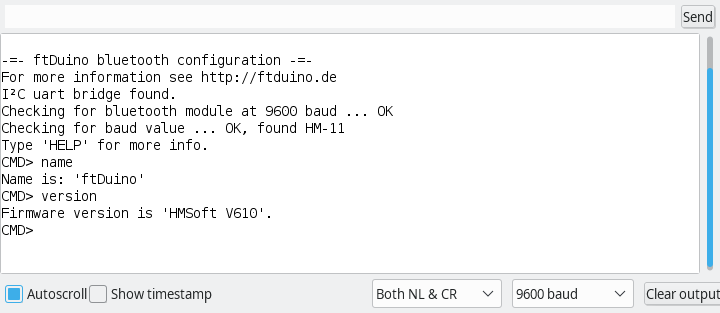
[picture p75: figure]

Abbildung 3.5: Bluetooth-Kongurations-Werkzeug

3.5. Bluetooth-Kongurations-Werkzeug | 11

Es ist aber auch möglich, das Modul durch das manuelle Senden von ungeschickt gewählten Befehlen z.B. bei Einsatz des Bridge-Sketches umzukongurieren, dass das Modul nicht mehr wie gewünscht kommuniziert.

In diesen Fällen kommt das Bluetooth-Kongurations-Werkzeug | Datei | . | Beispiele | . | Ftduino | . | Bluetooth | .
ftDuino-Bluetooth | . | bluetooth_config | zum Einsatz. Seine wichtigste Funktion ist es, eine umkongurierte Kom-
munikationsschnittstelle wieder in den Ausgangszustand zu versetzen. Dies passiert automatisch beim Start des Sketches.

Zusätzlich bietet dieser Sketch die Möglichkeit, den ftDuino-Bluetooth-Adapter umzubenennen.

# Kapitel 4

# Programmierung

Der ftDuino-Bluetooth-Adapter folgt der schertechnik-Philosophie eines exiblen Baukastensystems. Er stellt keine Black-Box dar, sondern kann bei Interesse selbst programmiert werden. Dieses Kapitel liefert das dafür Notwendige Know-How.

## 4.1 UART oder I²C

Zur Verbindung verschiedener in Computern zum Einsatz kommenden Bauelemente gibt es zahlreiche sogenannte Schnittstellen. Eine Schnittstelle beschreibt z.B. wie viele elektrische Verbindungen zur Kommunikation benötigt werden und in welcher zeitlichen Abfolge und in welche Richtung Signale übertragen werden. Der ftDuino bietet auf seinem 6-poligen Erweiterungsstecker eine sogenannte I²C-Schnittstelle. Diese Schnittstelle ist weit verbreitet wenn es um den einfachen Anschluss einfacher Sensorkomponenten geht. Über die I²C-Schnittstelle würde ursprünglich zum Einsatz in Fernsehern entwickelt und über sie lassen sich mit nur zwei elektrischen Signalen gleich eine Vielzahl von Sensoren ansprechen. Ebenfalls recht verbreitet ist die UART-Schnittstelle. Sie hat ihre Wurzeln u.a. in der seriellen Schnittstelle früher PCs. Auch sie kommt mit zwei elektrischen Verbindungen aus, eignet sich aber nur zum Anschluss eines weiteren Gerätes. Viele gängige Bluetooth-Chips und -module verwenden einen UART-Anschluss. Der ftDuino-Bluetooth-Adapter enthält daher neben dem Bluetooth-Modul einen Brückenbaustein, der zwischen der UART-Schnittstelle des Bluetooth-Moduls und der I²C-Schnittstelle übersetzt.

## 4.2 I²C-Schnittstelle

Jedes I²C-Gerät verfügt über eine sogenannte Adresse, über das es angesprochen wird und das es von anderen Geräten an der
gleichen I²C-Schnittstelle unterscheidbar macht. Der mit der ftDuino-Installation ausgelieferte Sketch | Datei | . | Beispiele | .
FtduinoSimple | . | I2C | . | I2cScanner | kann die I²C-Schnittstelle des ftDuino nach angeschlossenen I²C-Geräten absuchen.

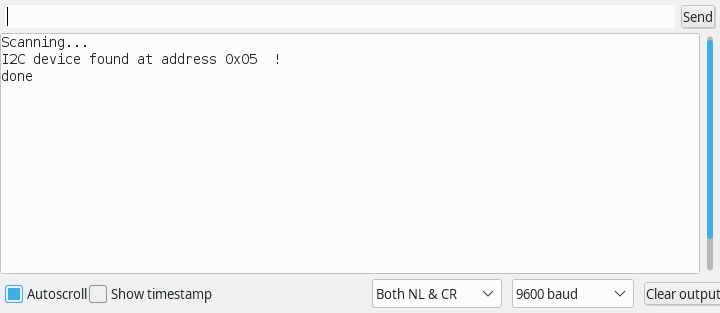
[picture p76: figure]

Abbildung 4.1: I2cScanner-Ausgabe bei angeschlossenem ftDuino-Bluetooth-Adapter

4.2. I²C-Schnittstelle | 13

Der ftDuino-Bluetooth-Adapter reagiert auf Adresse 5. Diese Adresse ist fest im Gerät eingespeichert und kann nicht verändert werden.

Der I²C-nach-UART-Umsetzer im ftDuino-Bluetooth-Adapter unterstützt alle möglichen Datenraten des HM-11-Moduls zwischen 1200 bit/s und 230400 bit/s. Damit ist im Gegensatz zu vielen einfacheren Arduino-Lösungen sichergestellt, dass das HM-11-Modul immer erreichbar bleibt, auch wenn die ab Werk eingestellte Datenrate vom Anwender verstellt wird. Zusätzlich kann auf diesem Weg das KEY-Signal am HM-11 betätigt werden, mit dessen Hilfe sich Teile des Moduls bei einer Fehlkonguration zurücksetzen lassen.

All diese Funktionen werden in den im vorigen Kapitel erwähnten Beispielen durch die in jedem Sketch hinterlegten Dateien I2cSerialBt.cpp und I2cSerialBt.h umgesetzt. Der in diesen beiden Dateien enthaltene Code kontrolliert die I

2C-Schnittstelle des ftDuino und bietet dem Sketch seinerseits eine Arduino-übliche sogenannte Stream-Schnittstelle. Die Stream-Schnittstelle lässt sich in Sketches überall dort einsetzen, wo sonst eine serielle UART-Schnittstelle (Serial, Soft-Serial, ...) zum Einsatz kommt. Auf diese Weise lassen sich fast alle bestehenden Sketches für den Arduino und das dort verbreitete HM-10-Modul an den ftDuino und das ftb anpasst. Die Code-Beispiele aus Kapitel 3 lassen sich dafür als Vorlage nutzen.

Das ebenfalls dort näher erklärte Beispiel | Datei | . | Beispiele | . | Ftduino | . | Bluetooth | . | ftDuino-Bluetooth | .
bluetooth_config | macht maximalen Gebrauch der I2cSerialBt-Schnittstelle und kann damit automatisiert auch einen
umkongurierten ftDuino-Bluetooth-Adapter wieder in einen denierten Zustand versetzen.

Weitere Details zur Programmierung des HM-11-Moduls nden sich in den Datenblättern unter http://www.jnhuamao.cn. In den allermeisten Fällen ist aber keine Umkonguration durch den Benutzer nötig. Die Werkseinstellungen erlauben direkt die Kopplung mit gängigen Smartdevices von Apple und Android.
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

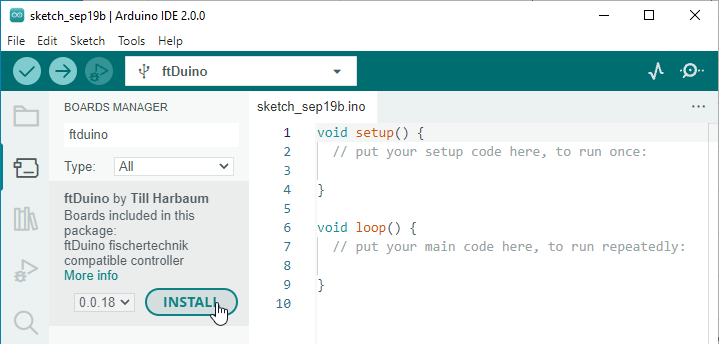
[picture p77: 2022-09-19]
www/images/setup_boardmanager_en.png

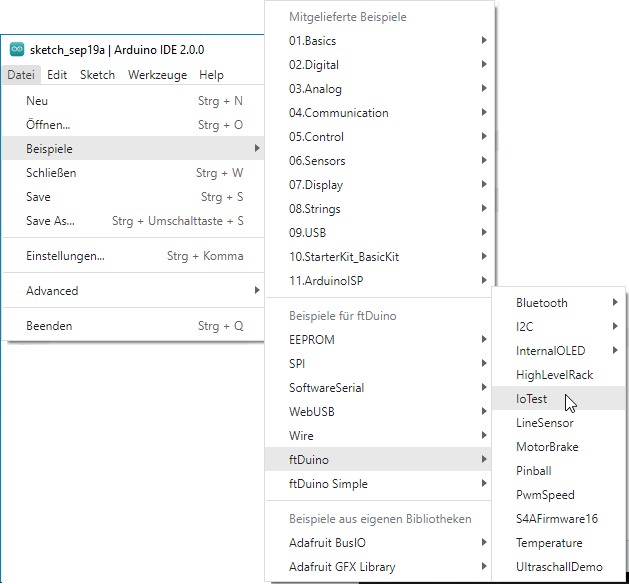
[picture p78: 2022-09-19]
www/images/setup_examples_de.png

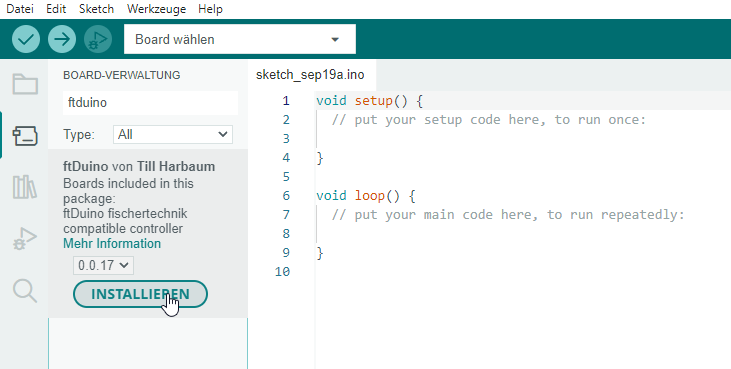
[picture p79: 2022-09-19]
www/images/setup_boardmanager_de.png

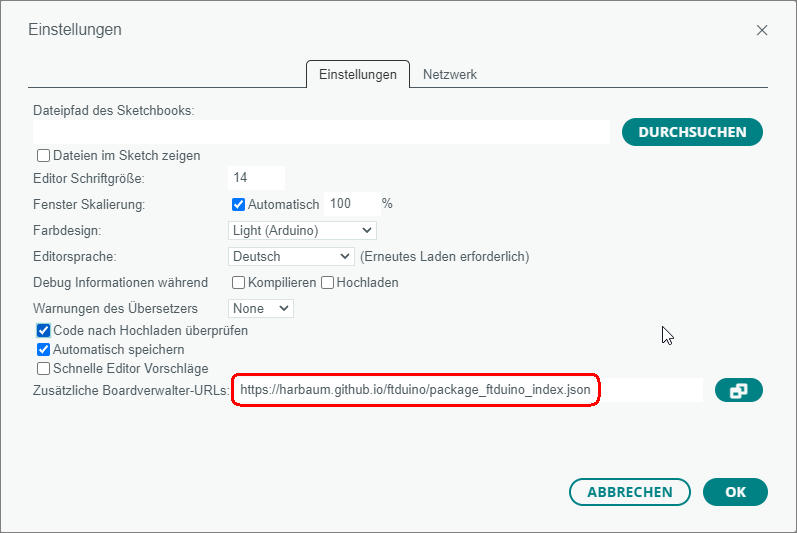
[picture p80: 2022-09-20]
www/images/setup_preferences_de.png

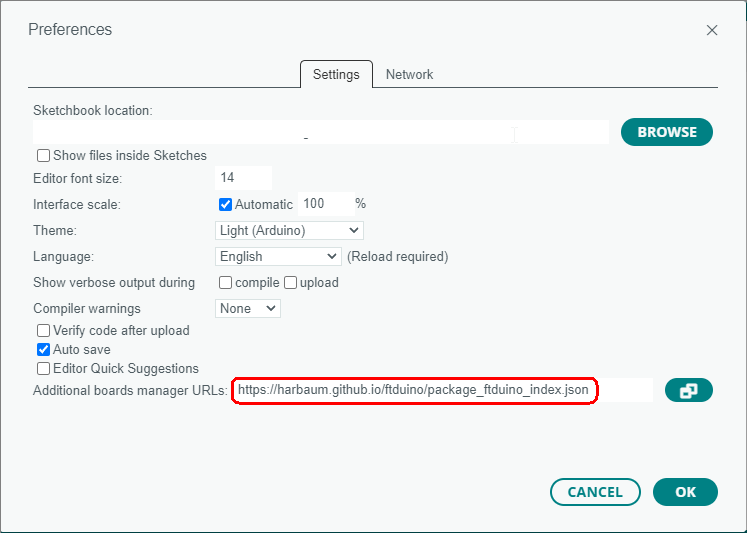
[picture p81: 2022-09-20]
www/images/setup_preferences_en.png

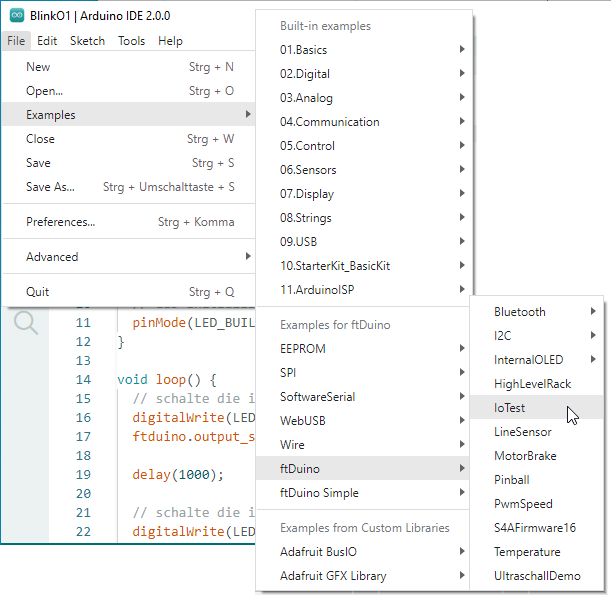
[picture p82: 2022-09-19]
www/images/setup_examples_en.png

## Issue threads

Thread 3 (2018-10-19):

Brickly demo

JoeTo1, 2018-10-19:
Once that "Adafruit GFX Library" (https://github.com/adafruit/Adafruit-GFX-Library) is installed, the  sketch compiles fine.

FtduinoDisplay.h

Vielleicht könnte das in die Dokumentation aufgenommen werden.

harbaum, 2018-11-26:
I might actually by default disable the usage of the display as 99% of all users won't use that.

harbaum, 2018-11-26:
Hinweis zur Doku hinzugefügt. Wird im nächsten Release dabei sein.

Closed 2018-11-26.

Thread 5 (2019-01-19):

Synchronize encoder motors

fecavy, 2019-01-19:
Hi,

I would like to synchronize two fischertechnik encoder motors. Are there any plans for adding this feature to the Ftduino library?

Thank you

harbaum, 2019-01-25:
Yes, the plans are there. But I don't know when this will be added.

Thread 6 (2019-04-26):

I2CSlave example: motor control bug

fecavy, 2019-04-26:
Controlling M1 is no problem, but M2, M3 and M4 don't work.

According to the manual, the following code should set **M2** to turn right at 100% speed, but instead the motor attached at **M3** starts to rotate.

```c++
#include <Wire.h>

void setup() {
  Wire.begin(); // join I2C bus as master
}

void startMotor() {
  Wire.beginTransmission(43); // connect to 0x2B slave ftDuino
  Wire.write(0x04);           // set output mode of O3/M2 to...
  Wire.write(0x13);           // ... motor output right
  Wire.endTransmission();
  delay(100);
  Wire.beginTransmission(43); // connect again
  Wire.write(0x05);           // set output value of M2 to...
  Wire.write(255);            // ... full speed
  Wire.endTransmission();
}

void loop() {
  startMotor();

  delay(3000);
}
```

I modified I2CSlave a little bit to track the issue down in the code:
[I2cSlaveDebug2.ino.txt](https://github.com/harbaum/ftduino/files/3121156/I2cSlaveDebug2.ino.txt)

It produces the following (slightly modified) output explaining the bug's origin:

```
---- turn M1 to the right (100%) (OK) ------------
I2C receive...
addr:	0
value:	13
port:	0
reg:	0
Set output mode: 0	=	13
I2C receive...
addr:	1
value:	FF
port:	0
reg:	1
Configure Hardware...
Check passed.
PWM:	64
mode:	0
Set motor 0	to	2	at	64

---- turn M2 to the right (100%) (FAIL) ---------
I2C receive...
addr:	4	(OK)
value:	13	(OK)
port:	2	(OK)
reg:	0	(OK)
Set output mode: 2	=	13	(OK) (O3 set to motor mode)
I2C receive...
addr:	5	(OK)
value:	FF	(OK)
port:	2	(FAIL)
reg:	1	(OK)
Configure Hardware...
Check passed.
PWM:	64	(OK)
mode:	0	(OK)
Set motor 2	to	2	at	64	(FAIL)
```

Looks like the motor port is not calculated correctly.
Port 2 can be `Ftduino::O3` (that works), but also `Ftduino::M2`.

Motor ports would require to be shifted 1 to the right to calculate them correctly:

- Motor offset from M1:   port>>1
- M1: 0>>1 (=0)
- M2: 2>>1 (=1)
- M3: 4>>1 (=2)
- M4: 6>>1 (=3)

If I wasn't unsure of breaking the set-output commands, I would file a pull request...

harbaum, 2019-10-17:
Thanks for reporting and sorry for missing this report for such a long time.

This:
https://github.com/harbaum/ftduino/commit/d64f912a79ee825f211818f23c034f6f1580f609
should fix the issue.

It will be part of the next release.

Closed 2019-10-17.

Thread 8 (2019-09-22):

Scratch3] Input hat seems to be broken

intrigus, 2019-09-22:
## Used scratch file:

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

## Expected behaviour:
I drag the input hat to the stage.
When I press the green flag the (hypothetical) code after the hat is exectued.

## Actual behaviour:
As soon as I begin to drag the hat to the stage an exception is thrown.

## Error:
````javascript
lib.min.js:270125 Uncaught (in promise) TypeError: Cannot convert undefined or null to object
    at Function.keys (<anonymous>)
    at Scratch3FtduinoBlocks.parse (lib.min.js:270125)
    at serial.Port.port.onReceive (lib.min.js:270200)
    at lib.min.js:269660
parse @ lib.min.js:270125
port.onReceive @ lib.min.js:270200
(anonymous) @ lib.min.js:269660
Promise.then (async)
readLoop @ lib.min.js:269659
(anonymous) @ lib.min.js:269662
Promise.then (async)
readLoop @ lib.min.js:269659
(anonymous) @ lib.min.js:269685
Promise.then (async)
serial.Port.connect @ lib.min.js:269684
connect @ lib.min.js:270179
(anonymous) @ lib.min.js:270233
Promise.then (async)
autoConnect @ lib.min.js:270226
Scratch3FtduinoBlocks @ lib.min.js:269853
loadExtensionURL @ lib.min.js:265657
handleItemSelect @ lib.min.js:328425
wrapper @ lib.min.js:71256
handleSelect @ lib.min.js:316886
wrapper @ lib.min.js:71256
handleClick @ lib.min.js:329111
wrapper @ lib.min.js:71256
callCallback @ lib.min.js:83398
invokeGuardedCallbackDev @ lib.min.js:83437
invokeGuardedCallback @ lib.min.js:83294
invokeGuardedCallbackAndCatchFirstError @ lib.min.js:83308
executeDispatch @ lib.min.js:83692
executeDispatchesInOrder @ lib.min.js:83711
executeDispatchesAndRelease @ lib.min.js:83812
executeDispatchesAndReleaseTopLevel @ lib.min.js:83823
forEachAccumulated @ lib.min.js:83791
processEventQueue @ lib.min.js:83968
runEventQueueInBatch @ lib.min.js:86463
handleTopLevel @ lib.min.js:86472
handleTopLevelImpl @ lib.min.js:86203
batchedUpdates @ lib.min.js:93938
batchedUpdates @ lib.min.js:85186
dispatchEvent @ lib.min.js:86277
````

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

harbaum, 2019-10-17:
Which version did you use? The "offline" version or the online version available at https://harbaum.github.io/ftduino/webusb/scratch3/ ?

The current online version works for me. If it still fails for you please report which version you use on which OS and which browser you are using.

harbaum, 2019-10-18:
Ah ... i see. I can trigger that problem by clicking the hat. Otherwise it just works as expected. But when clicking it something goes wrong.

harbaum, 2019-10-18:
Please try again ... The fact that HATs in scratch don't support promises really doesn't make asynchronous USB io easier to deal with ....

harbaum, 2019-10-18:
For reference. This is related to https://github.com/LLK/scratch-vm/issues/2129 and the fact that HATs don't support async processing which requires a lot of nasty hacks.

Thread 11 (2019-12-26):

FTDuino can not connect using WebUSB, Scratch nor Brickly

KKempen, 2019-12-26:
Hi, just got the FTDuino in the mail and wrote the first few programs, now I wanted to use Scratch so I downloaded the IOServer software as described in the manual.

On my Win10 machine when I try to connect using the online Scratch editor nothing shows up in the popup window;
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
When i do the same thing on my linux machine (Debian 10 Mate on a i386 architecture) usin' Chromium FTDuino shows up in de selection window, however when I try to connect. An error is returned: "Connection error: NotFoundError: The interface number provided is not supported by the device in its current configuration."
Can you please comment on this behaviour?

harbaum, 2020-04-17:
Regarding the Windows issue: WebUSB can be rather tricky under Windows in general as seen e.g. here: https://github.com/WICG/webusb/issues/143

There are two "popular" ways to deal with this. Sometimes the following hint helps:

> Enabling new usb backend for Windows on Chrome flag solved the problem for us, chrome://flags/#new-usb-backend

And sometimes (more often) this one:

> Try to install WinUSB drivers manually with Zadig - https://zadig.akeo.ie/

harbaum, 2020-04-17:
Regarding your Linux issue: I have never seen/heard that. The error message is not very detailed. Two things come to mind:

a) Is the correct sketch installed with the Board set to "ftduino (webusb)"?

b) The Udev rules have been setup correctly? Especially this one:
  ATTRS{idVendor}=="1c40" ATTRS{idProduct}=="0538", ENV{ID_MM_DEVICE_IGNORE}="1", MODE="0666"

Closed 2021-01-28.

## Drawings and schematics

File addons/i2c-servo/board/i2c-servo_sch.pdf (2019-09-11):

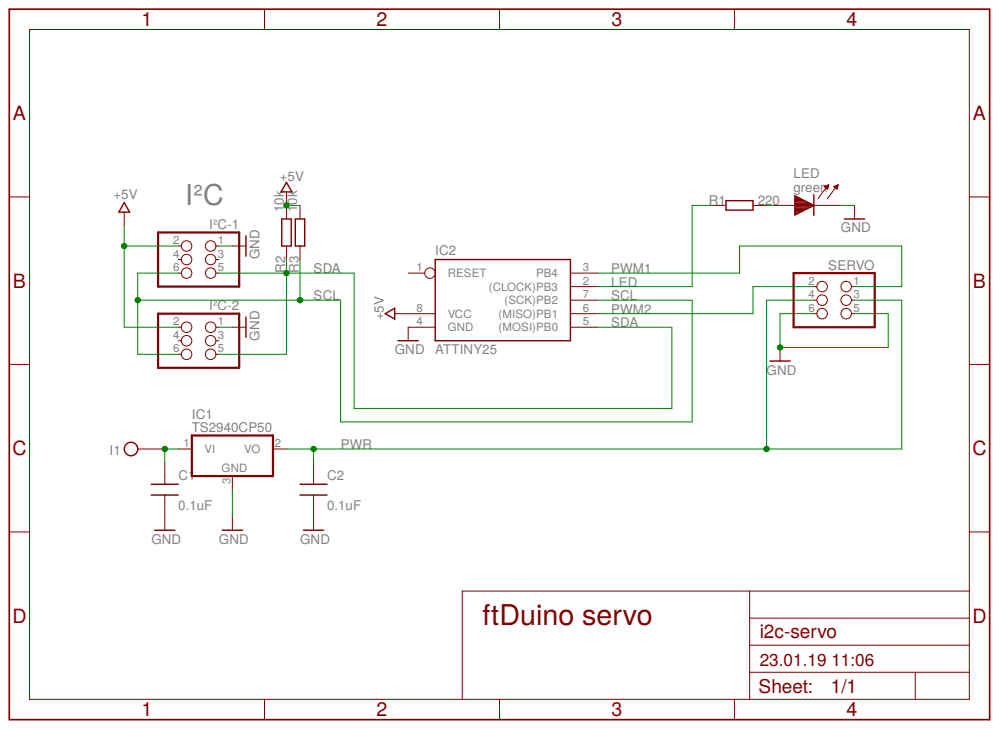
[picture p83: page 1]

ftDuino servo

Sheet: 1/1

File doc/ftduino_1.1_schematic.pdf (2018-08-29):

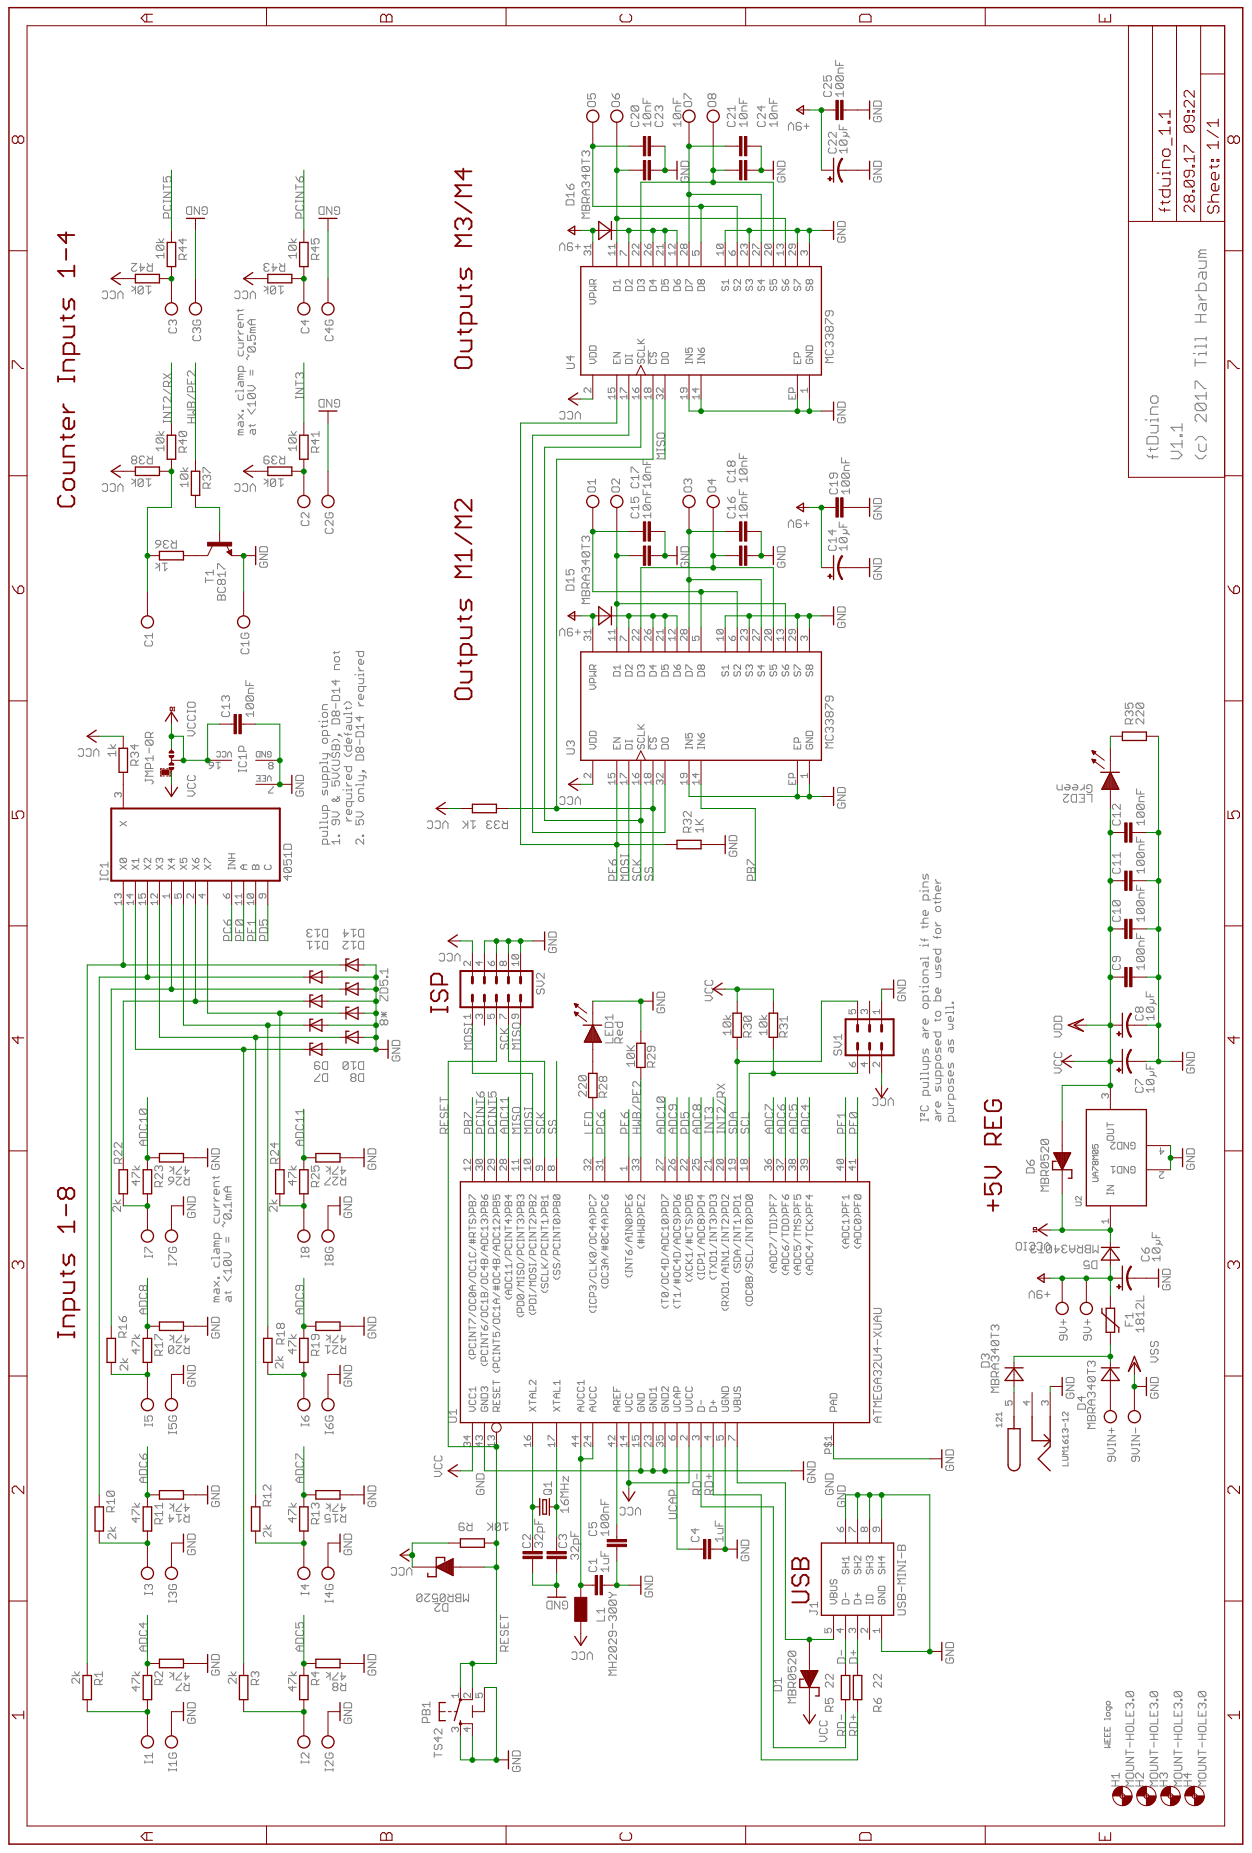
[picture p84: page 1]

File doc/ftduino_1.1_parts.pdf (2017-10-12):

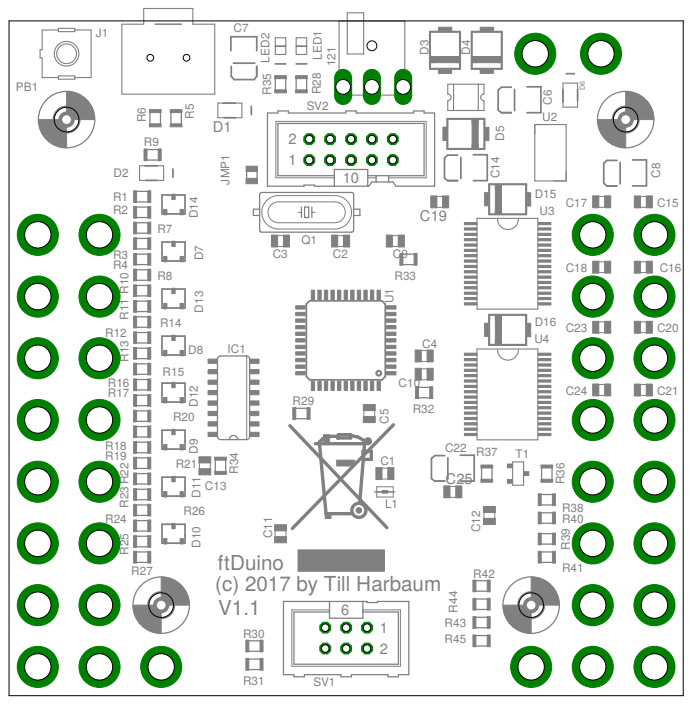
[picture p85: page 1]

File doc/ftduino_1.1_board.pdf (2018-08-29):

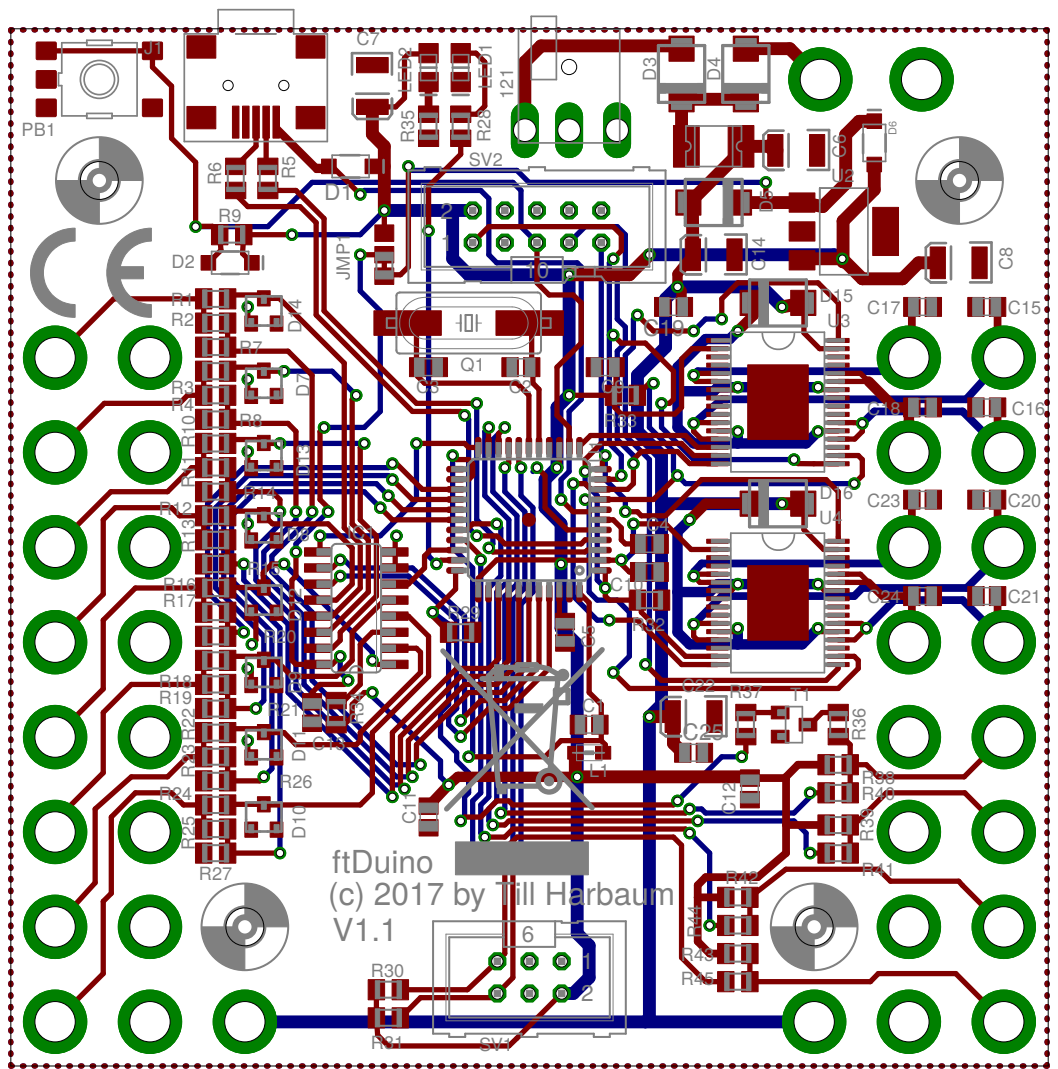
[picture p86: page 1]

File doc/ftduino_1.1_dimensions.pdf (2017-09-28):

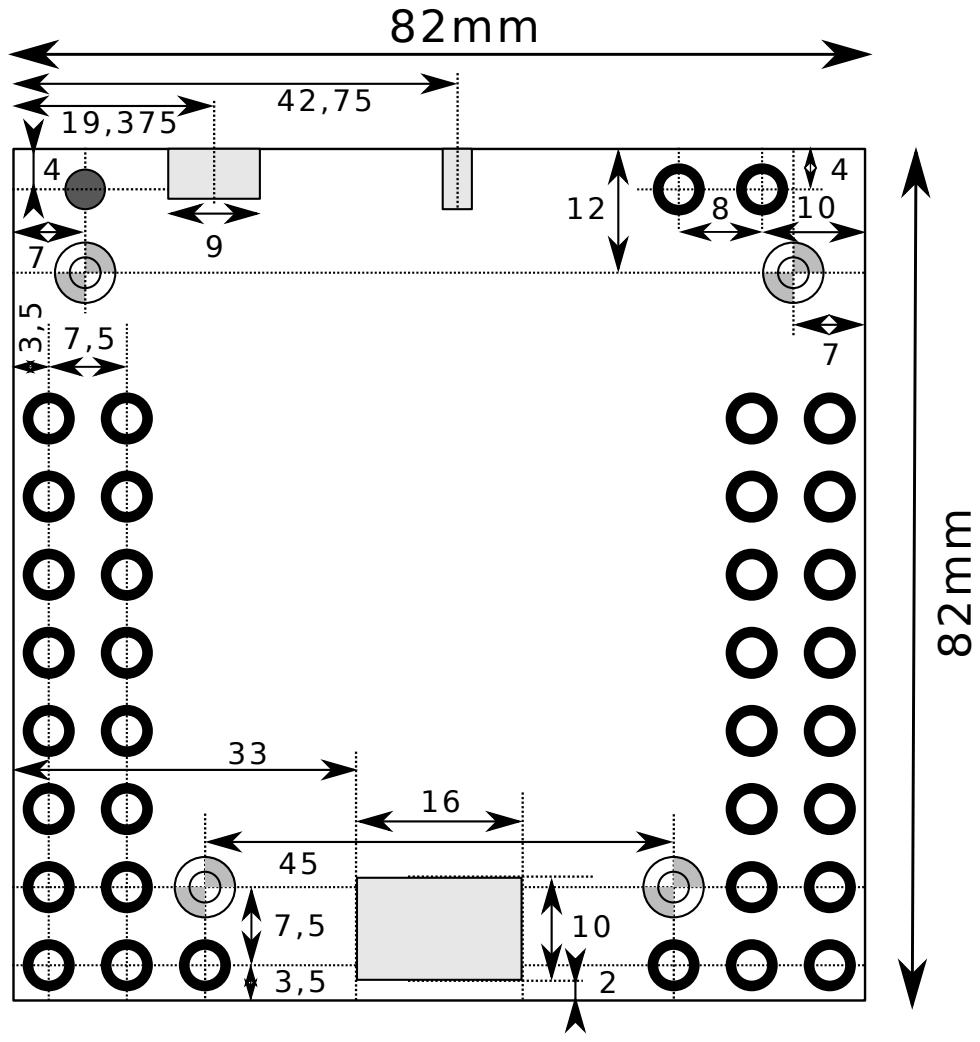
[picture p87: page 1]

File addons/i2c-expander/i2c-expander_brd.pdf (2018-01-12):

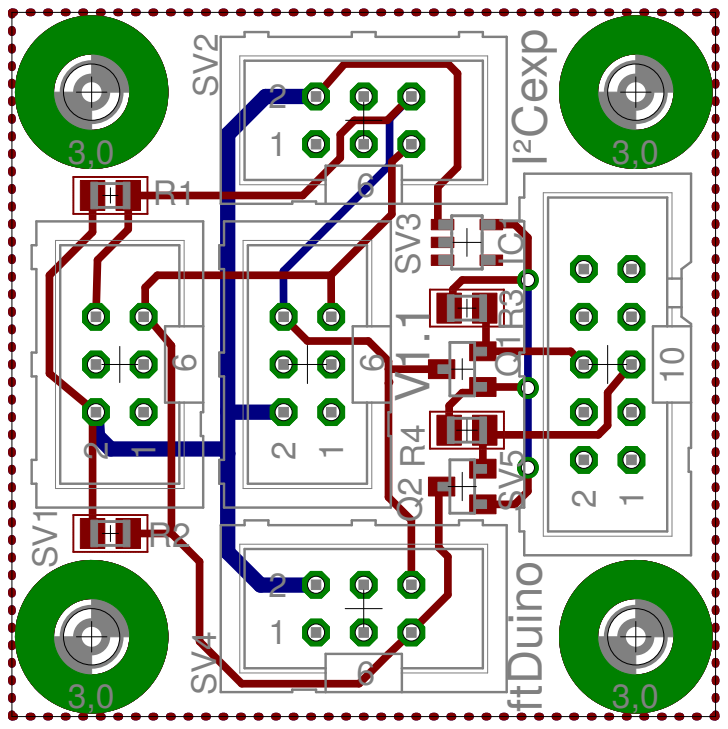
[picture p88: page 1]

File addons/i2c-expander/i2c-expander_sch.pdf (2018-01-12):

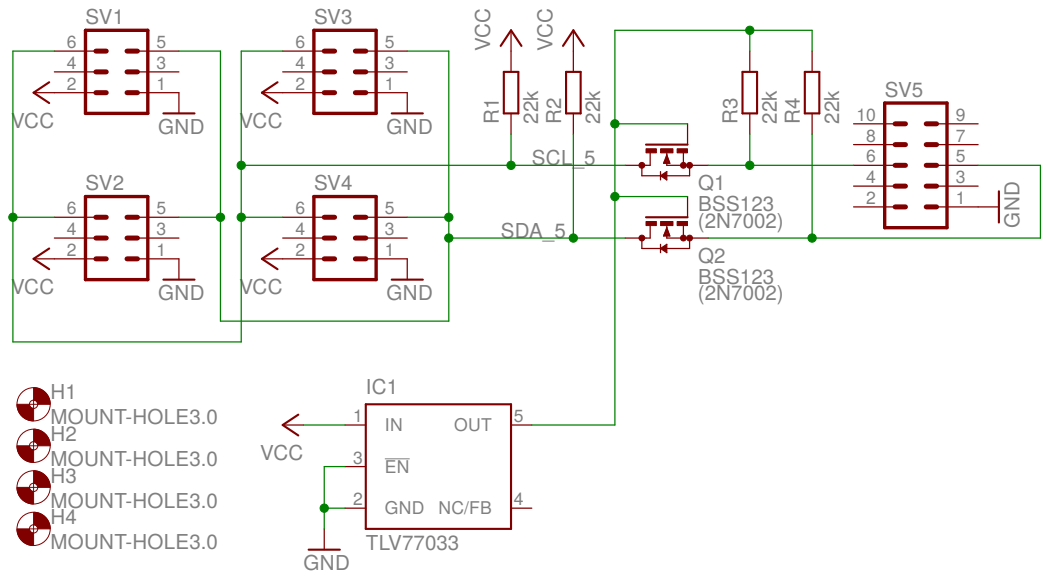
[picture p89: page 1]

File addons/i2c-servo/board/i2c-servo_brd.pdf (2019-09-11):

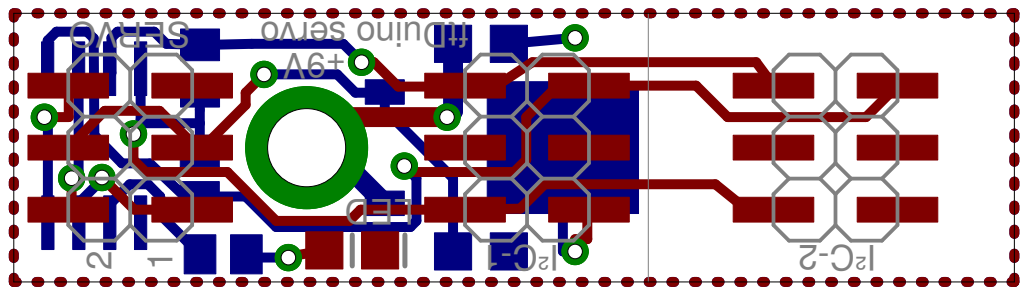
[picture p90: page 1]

ovr es oni u Dtf

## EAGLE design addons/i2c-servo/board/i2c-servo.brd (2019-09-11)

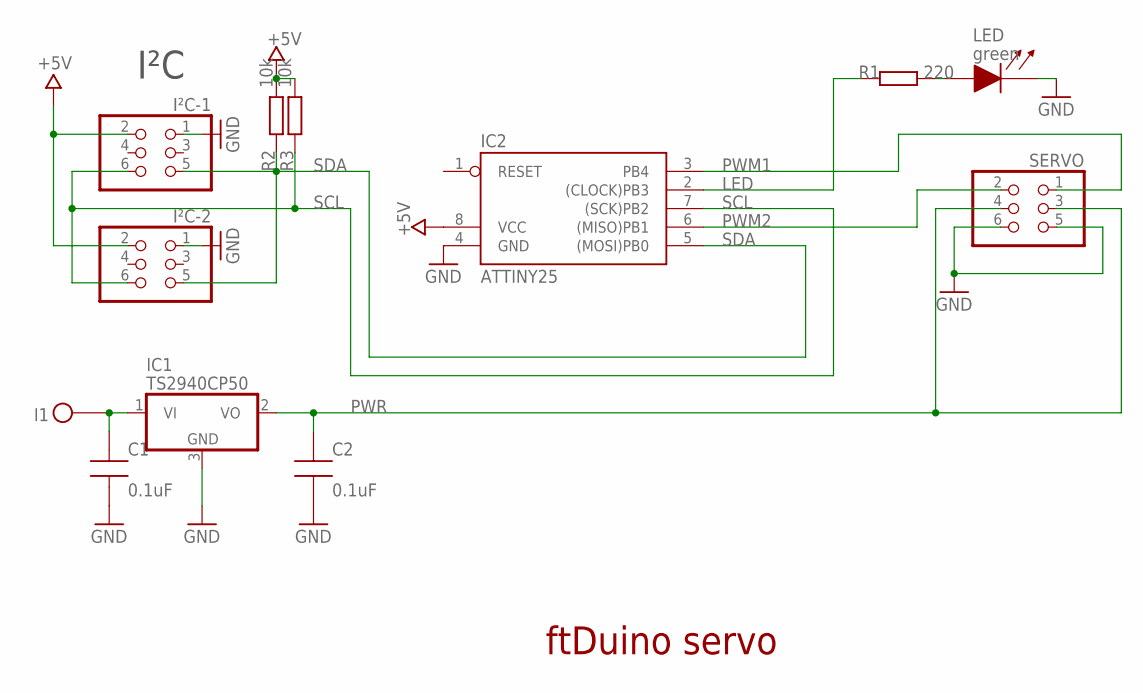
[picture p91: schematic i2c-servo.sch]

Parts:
C1, C2: 0.1uF; CAP0805-NP
H5: I1; FT-HUELSE
IC1: TS2940CP50; TO252
IC2: ATTINY25; SOIC8
I²C-1, I²C-2: PINHD-2X3_2.54-SMD; 2X03SMD
LED: green; LED0805
R1: 220; M0805
R2, R3: 10k; M0805
SERVO: PINHD-2X3_2.54-SMD; 2X03SMD

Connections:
+5V: IC2.8 (VCC), I²C-1.2, I²C-2.2, R2.2, R3.2
GND: C1.2, C2.2, IC1.3 (GND), IC2.4 (GND), I²C-1.1, I²C-2.1, LED.1 (CA), SERVO.5, SERVO.6
LED: IC2.2 ((CLOCK)PB3), R1.1
unnamed: C1.1, H5.D1, IC1.1 (VI)
unnamed: LED.2 (AN), R1.2
PWM1: IC2.3 (PB4), SERVO.1
PWM2: IC2.6 ((MISO)PB1), SERVO.2
PWR: C2.1, IC1.2 (VO), SERVO.3, SERVO.4
SCL: IC2.7 ((SCK)PB2), I²C-1.6, I²C-2.6, R3.1
SDA: IC2.5 ((MOSI)PB0), I²C-1.5, I²C-2.5, R2.1

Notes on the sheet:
I²C
ftDuino servo

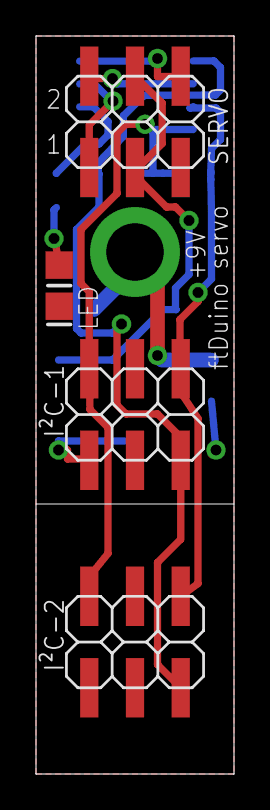
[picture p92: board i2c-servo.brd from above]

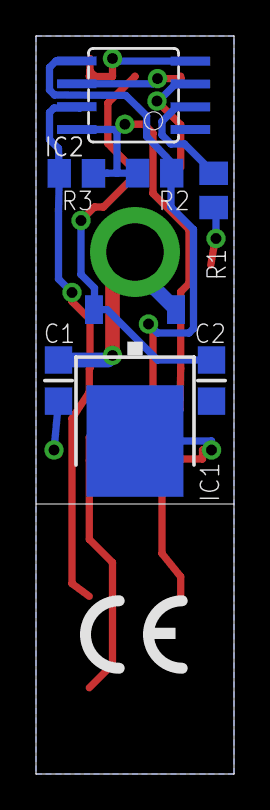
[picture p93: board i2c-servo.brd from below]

Board: 2 copper layers, 11.0 x 41.0 mm, 12 parts (7 on the bottom side), 10 nets.

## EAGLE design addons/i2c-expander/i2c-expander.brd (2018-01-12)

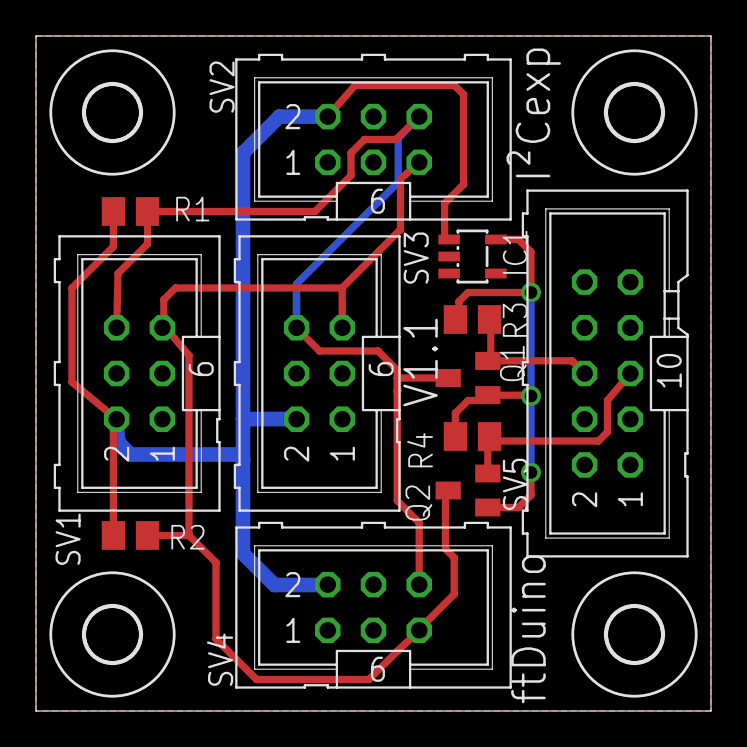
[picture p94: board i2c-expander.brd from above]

Board: 2 copper layers, 37.5 x 37.5 mm, 16 parts (0 on the bottom side), 7 nets.

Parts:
H1, H2, H3, H4: MOUNT-HOLE3.0; 3,0
IC1: TLV77033; SOT23-DBV
Q1, Q2: BSS123; SOT23
R1, R2, R3, R4: 22k; M0805
SV1, SV2, SV3, SV4: ML6
SV5: ML10

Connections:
GND: IC1.2, IC1.3, SV1.1, SV2.1, SV3.1, SV4.1, SV5.1
unnamed: Q1.2, R3.1, SV5.6
unnamed: Q2.2, R4.1, SV5.5
unnamed: IC1.5, Q1.1, Q2.1, R3.2, R4.2
SCL_5: Q1.3, R1.1, SV1.6, SV2.6, SV3.6, SV4.6
SDA_5: Q2.3, R2.1, SV1.5, SV2.5, SV3.5, SV4.5
VCC: IC1.1, R1.2, R2.2, SV1.2, SV2.2, SV3.2, SV4.2

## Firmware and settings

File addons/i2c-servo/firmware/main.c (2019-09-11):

/***************************************************************************
 *                                                                         *
 ***************************************************************************/

/* use from Linux host:
   i2cdetect -l
   -> e.g. bus 9 (i2cdetect 9)
   i2cset -y 9 0x11 0x00 0x00   -> channel 0 off
   i2cset -y 9 0x11 0x00 0xff   -> channel 0 max (limited to 125/2ms by default)
   i2cset -y 9 0x11 0x01 0x00   -> channel 1 off
   i2cset -y 9 0x11 0x01 0x5e   -> channel 1 94/1.5ms, servo centered

   i2cget -y 9 0x11 0x00        -> read version register (0x10 for 1.0)

   i2cset -y 9 0x11 0x08 0x13   -> change i2c address temporarily
   i2cset -y 9 0x13 0x09 0xa5   -> save settings in eeprom (using new address!!)
*/

#include <avr/io.h>
#include <avr/interrupt.h>
#include <avr/eeprom.h>
#include <util/delay.h>

#ifndef TWI_ADDRESS
#define TWI_ADDRESS		0x11
#endif

#define TWI_STATE_IDLE			0
#define TWI_STATE_RX_ACK		1
#define TWI_STATE_BYTE_RX		2
#define TWI_STATE_ACK_PR_TX             3
#define TWI_STATE_PR_ACK_TX		4
#define TWI_STATE_BYTE_TX		5

volatile uint8_t twi_state = TWI_STATE_IDLE;

volatile uint8_t pulse_width[2] = { 0x00, 0x00 };
volatile uint8_t led_timeout = 0;

#define MAGIC 0xdeadbeef

// config as stored in eeprom
typedef struct {
  uint8_t twi_address;

  struct {  
    uint8_t offset;
    uint8_t min, max;
  } servo[2]; 
} ee_config_t;

ee_config_t config;

#define SDA  (1<<0)
#define PWM2 (1<<1)  // OC1A
#define SCL  (1<<2)
#define LED  (1<<3)
#define PWM1 (1<<4)  // OC1B

// The servo has a full cycle of 20ms, a 1-2ms high phase within this
// is indicating a min to max angle.

// This cannot be handled using one 8 bit timer. The timer would run
// at 7812.5 Hz from 0 to 155. The 1ms to 2ms range would be from 8 to
// 15 resulting in only 8 positions/angles the servo could be set to.

// Using two timers:
// One timer running at 7812.5 is used to trigger a second timer which
// is put in a kind of one shot mode to generate the 1-2ms signal

void timer_init(void) {

  // setup timer 0 in CTC mode at F_CPU/256
  // timer 0 has no /128 divider, we thus run with a /256 divider
  // at sligtly lower precision
  TCNT0 = 0;
  TCCR0A = (1 << WGM01);   // CTC, OCx not connected
#if F_CPU == 1000000
  TCCR0B = (1 << CS02);    // CTC, prescaler /256
  OCR0A = F_CPU/256/50;    // 78 -> frequency = 50.08 Hz
#elif F_CPU == 8000000
  TCCR0B = (1 << CS02) | (1 << CS00);    // CTC, prescaler /1024
  OCR0A = F_CPU/1024/50;    // 156 -> frequency = 50.08 Hz
#else
#error "Unsupported CPU clock"
#endif
  TIMSK |= (1<< OCIE0A);   // generate output compare interrupt

#if F_CPU == 1000000
  // timer 1: F_CPU / 16 (prescaler) -> 62500 Hz
  TCCR1 = (1 << CS12) | (1 << CS10);
#elif F_CPU == 8000000
  // timer 1: F_CPU / 128 (prescaler) -> 62500 Hz
  TCCR1 = (1 << CS13);
#endif
  
  // drive LED on port PB.3, LED on for 1 second
  DDRB |= LED;
  PORTB |= LED;
  led_timeout = 50;

  // drive PWM outputs low
  DDRB |= (PWM1 | PWM2);
  PORTB &= ~(PWM1 | PWM2);
}

// timer firing at 50Hz/20ms
ISR(TIMER0_COMPA_vect) {
  // run down led timer and switch LED off after timeout
  if(led_timeout > 0) {
    led_timeout--;
    if(!led_timeout)    
      PORTB &= ~LED;       // switch off LED
  }

  // setup timer 1
  // max pulse length = 255 * 16us = 4,08ms
  
  if(pulse_width[0] != 0) {
    // add limit range and add offset
    uint8_t val = pulse_width[0];
    if(val < config.servo[0].min) val = config.servo[0].min;
    if(val > config.servo[0].max) val = config.servo[0].max;
    val += config.servo[0].offset;

    // use hw OC1B
    GTCCR |= (1 << COM1B0) | (1 << COM1B1) | (1<<FOC1B);  // set
    GTCCR &= ~(1 << COM1B0); // let timer clear
    
    OCR1B = val;               // @62500/sec
  } else {
    GTCCR &= ~((1 << COM1B0) | (1 << COM1B1));
    PORTB &= ~PWM1;            // set output low
  }
    
  if(pulse_width[1] != 0) {
    // add limit range and add offset
    uint8_t val = pulse_width[1];
    if(val < config.servo[1].min) val = config.servo[1].min;
    if(val > config.servo[1].max) val = config.servo[1].max;
    val += config.servo[1].offset;
    
    // use hw OC1A
    TCCR1 |= (1 << COM1A0) | (1 << COM1A1);
    GTCCR |= (1<<FOC1A);     // set OC1A
    TCCR1 &= ~(1 << COM1A0); // let timer clear OC1A

    OCR1A = val;               // @62500/sec
  } else {
    TCCR1 &= ~((1 << COM1A0) | (1 << COM1A1));
    PORTB &= ~PWM2;            // set output low
  }
    
  // start timer1
  TCNT1 = 0;
}

void save_config(void) {
  eeprom_write_dword((void*)0, MAGIC);
  eeprom_write_block(&config, (void*)4, sizeof(ee_config_t));
}

void USI_init(void) {
  if(eeprom_read_dword((void*)0) != MAGIC) {
    // load default values
    config.twi_address = TWI_ADDRESS;

    // allowed range = 1ms ... 2ms, no offset
    config.servo[0].min = config.servo[1].min = 63;
    config.servo[0].max = config.servo[1].max = 125;
    config.servo[0].offset = config.servo[1].offset = 0;
    
  } else {
    // load config from eeprom
    eeprom_read_block(&config, (void*)4, sizeof(ee_config_t));
    
    // make sure address is within sane bounds
    if((config.twi_address < 1) || (config.twi_address > 126))
      config.twi_address = TWI_ADDRESS;
  }
  
  DDRB  &= ~SDA;    // PB.0 = SDA
  PORTB &= ~SDA;   
  DDRB  |=  SCL;    // PB.2 = SCL
  PORTB |=  SCL;

  // 2-wire mode; Hold SCL on start and overflow; ext. clock
  // startcondition interrupt enable
  USICR = (1 << USISIE) | (0 << USIOIE) | (1 << USIWM1) |
    (0 << USIWM0) | (1 << USICS1) | (0 << USICS0) | (0 << USICLK) | (0 << USITC);
  // write 1 to clear flags, clear counter
  USISR = (1 << USISIF) | (1 << USIOIF) | (1 << USIPF) | (1 << USIDC);
}

int main(void) {
#if 0
  DDRB |= PWM1 | PWM2;
  TCNT1 = 0;
  OCR1B = 94;
  // F_CPU / 16 (prescaler) -> 62500 Hz
  TCCR1  = (1 << CS12) | (1 << CS10);
  GTCCR  = (1 << COM1B1);    // clear on match
  //  GTCCR |= (1<<FOC1A) | (1<<FOC1B);
  
  //  sei();
  for(;;) {
    _delay_ms(100);
    TCNT1 = 0;
    GTCCR  = (1 << COM1B0) | (1 << COM1B1) | (1<<FOC1B);  // set
    GTCCR  = (1 << COM1B1); // let timer clear
  }
#else  
  
  timer_init();
  USI_init();

  sei();

  for(;;) { }
#endif
}

// http://www.aca-vogel.de/TINYUSII2C_AVR312/I2C_corrected.c
SIGNAL(SIG_USI_START) {
  uint8_t tmpUSISR __attribute__((unused)) = USISR;
  twi_state = TWI_STATE_IDLE;

  // Wait for SCL to go low to ensure the "Start Condition" has completed.
  // otherwise the counter will count the transition
#if 0
  // TO
  uint8_t to = 255;
  while ( (PINB & SCL) && to)
    to--;
  
  if(PINB & SCL) return;   // timeout
#else
  // SDW
  while ( (PINB & SCL) && ( !(PINB & SDA) ) );
#endif
  
  USISR = 0xf0; // write 1 to clear flags; clear counter

  // enable USI interrupt on overflow; SCL goes low on overflow
  USICR |= (1<<USIOIE) | (1<<USIWM0);
}

SIGNAL(SIG_USI_OVERFLOW) {
  static uint8_t twi_cnt, twi_reg;
  uint8_t twi_rx_byte = USIDR;

  switch(twi_state) {

  case TWI_STATE_IDLE:
    if (((twi_rx_byte & 0xfe) >> 1) != config.twi_address) {	// if not receiving my address
      // disable USI interrupt on overflow; disable SCL low on overflow
      USICR &= ~((1<<USIOIE) | (1<<USIWM0));
    } else { // else address is mine
      PORTB |= LED;       // switch on LED
      led_timeout = 5;    // keep LED on for 100ms

      DDRB |= SDA;  // drive SDA
      USISR = 0x0e; // reload counter for ACK, (SCL) high and back low
      
      if (twi_rx_byte & 0x01)
	twi_state = TWI_STATE_ACK_PR_TX;   // master writes
      else 
	twi_state = TWI_STATE_RX_ACK;   // master reads

      twi_cnt = 0;
    }
    break;
    
  case TWI_STATE_RX_ACK:
    DDRB  &= ~SDA;  // release SDA
    twi_state = TWI_STATE_BYTE_RX;
    break;
    
  case TWI_STATE_BYTE_RX:
    // write pulse_width registers
    if(twi_cnt == 0) twi_reg = USIDR;
    else if(twi_cnt == 1) {
      if((twi_reg & 0xfe) == 0x00)     // reg 0 / 1
	pulse_width[twi_reg&1] = USIDR;      
      if((twi_reg & 0xfe) == 0x02)     // reg 2 / 3  (servo 0/1 min)  
	config.servo[twi_reg&1].min = USIDR;      
      if((twi_reg & 0xfe) == 0x04)     // reg 4 / 5  (servo 0/1 max)  
	config.servo[twi_reg&1].max = USIDR;      
      if((twi_reg & 0xfe) == 0x06)     // reg 6 / 7  (servo 0/1 offset)  
	config.servo[twi_reg&1].min = USIDR;      
      if(twi_reg == 0x08) {            // reg 8
	uint8_t val = USIDR;
	// limit address to 0x03 - 0x77 range except 0x3c (maybe internal display)
	if((val >= 0x03) && (val <= 0x77) && (val != 0x3c)) 
	  config.twi_address = val;
      }
      if((twi_reg == 0x09) && (USIDR == 0xa5)) // reg 9/0xa5
	save_config();
    }
    twi_cnt++;
    
    DDRB  |=  SDA;    // drive SDA
    USISR = 0x0e;     // reload counter for ACK, (SCL) high and back low
    twi_state = TWI_STATE_RX_ACK;
    break;
    
  case TWI_STATE_ACK_PR_TX:
    if(twi_reg == 0x00)
      USIDR = VERSION;   // return chip revision for register 0
    else
      USIDR = 0x5a;      // some kind of magic byte allowing to identify the chip
    
    PORTB |=  SDA; // transparent for shifting data out
    twi_state = TWI_STATE_BYTE_TX;
    break;
    
  case TWI_STATE_PR_ACK_TX:
    if(twi_rx_byte & 0x01) {
      twi_state = TWI_STATE_IDLE; // no ACK from master --> no more bytes to send
      PORTB &= ~LED; // switch off LED
    } else {
      USIDR = 0x00;  // all further bytes read 0
      
      PORTB |=  SDA; // transparent for shifting data out
      DDRB  |=  SDA;
      twi_state = TWI_STATE_BYTE_TX;
    }
    break;
    
  case TWI_STATE_BYTE_TX:
    DDRB  &= ~SDA;
    PORTB &= ~SDA;
    USISR = 0x0e;	// reload counter for ACK, (SCL) high and back low
    twi_state = TWI_STATE_PR_ACK_TX;
    break;
  }
  
  USISR |= (1<<USIOIF); // clear overflowinterruptflag, this also releases SCL
}

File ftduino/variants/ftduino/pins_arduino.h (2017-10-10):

/*
  pins_arduino.h - Pin definition functions for Arduino
  Part of Arduino - http://www.arduino.cc/

  Copyright (c) 2007 David A. Mellis

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
  You should have received a copy of the GNU Lesser General
  Public License along with this library; if not, write to the
  Free Software Foundation, Inc., 59 Temple Place, Suite 330,
  Boston, MA  02111-1307  USA
*/

#ifndef Pins_Arduino_h
#define Pins_Arduino_h

#include <avr/pgmspace.h>

// Workaround for wrong definitions in "iom32u4.h".
// This should be fixed in the AVR toolchain.
#undef UHCON
#undef UHINT
#undef UHIEN
#undef UHADDR
#undef UHFNUM
#undef UHFNUML
#undef UHFNUMH
#undef UHFLEN
#undef UPINRQX
#undef UPINTX
#undef UPNUM
#undef UPRST
#undef UPCONX
#undef UPCFG0X
#undef UPCFG1X
#undef UPSTAX
#undef UPCFG2X
#undef UPIENX
#undef UPDATX
#undef TCCR2A
#undef WGM20
#undef WGM21
#undef COM2B0
#undef COM2B1
#undef COM2A0
#undef COM2A1
#undef TCCR2B
#undef CS20
#undef CS21
#undef CS22
#undef WGM22
#undef FOC2B
#undef FOC2A
#undef TCNT2
#undef TCNT2_0
#undef TCNT2_1
#undef TCNT2_2
#undef TCNT2_3
#undef TCNT2_4
#undef TCNT2_5
#undef TCNT2_6
#undef TCNT2_7
#undef OCR2A
#undef OCR2_0
#undef OCR2_1
#undef OCR2_2
#undef OCR2_3
#undef OCR2_4
#undef OCR2_5
#undef OCR2_6
#undef OCR2_7
#undef OCR2B
#undef OCR2_0
#undef OCR2_1
#undef OCR2_2
#undef OCR2_3
#undef OCR2_4
#undef OCR2_5
#undef OCR2_6
#undef OCR2_7

#define NUM_DIGITAL_PINS  31
#define NUM_ANALOG_INPUTS 12

#define TX_RX_LED_INIT	 // DDRD |= (1<<5), DDRB |= (1<<0)
#define TXLED0	//		PORTD |= (1<<5)
#define TXLED1	//		PORTD &= ~(1<<5)
#define RXLED0	// 		PORTB |= (1<<0)
#define RXLED1	//		PORTB &= ~(1<<0)

#define PIN_WIRE_SDA         (2)
#define PIN_WIRE_SCL         (3)

static const uint8_t SDA = PIN_WIRE_SDA;
static const uint8_t SCL = PIN_WIRE_SCL;

#define LED_BUILTIN 13
#define LED_BUILTIN_RX 17
#define LED_BUILTIN_TX 30

// Map SPI port to 'new' pins D14..D17
#define PIN_SPI_SS    (17)
#define PIN_SPI_MOSI  (16)
#define PIN_SPI_MISO  (14)
#define PIN_SPI_SCK   (15)

static const uint8_t SS   = PIN_SPI_SS;
static const uint8_t MOSI = PIN_SPI_MOSI;
static const uint8_t MISO = PIN_SPI_MISO;
static const uint8_t SCK  = PIN_SPI_SCK;

// Mapping of analog pins as digital I/O
// A6-A11 share with digital pins
#define PIN_A0   (18)
#define PIN_A1   (19)
#define PIN_A2   (20)
#define PIN_A3   (21)
#define PIN_A4   (22)
#define PIN_A5   (23)
#define PIN_A6   (24)
#define PIN_A7   (25)
#define PIN_A8   (26)
#define PIN_A9   (27)
#define PIN_A10  (28)
#define PIN_A11  (29)

static const uint8_t A0 = PIN_A0;
static const uint8_t A1 = PIN_A1;
static const uint8_t A2 = PIN_A2;
static const uint8_t A3 = PIN_A3;
static const uint8_t A4 = PIN_A4;
static const uint8_t A5 = PIN_A5;
static const uint8_t A6 = PIN_A6;	// D4
static const uint8_t A7 = PIN_A7;	// D6
static const uint8_t A8 = PIN_A8;	// D8
static const uint8_t A9 = PIN_A9;	// D9
static const uint8_t A10 = PIN_A10;	// D10
static const uint8_t A11 = PIN_A11;	// D12

#define digitalPinToPCICR(p)    ((((p) >= 8 && (p) <= 11) || ((p) >= 14 && (p) <= 17) || ((p) >= A8 && (p) <= A10)) ? (&PCICR) : ((uint8_t *)0))
#define digitalPinToPCICRbit(p) 0
#define digitalPinToPCMSK(p)    ((((p) >= 8 && (p) <= 11) || ((p) >= 14 && (p) <= 17) || ((p) >= A8 && (p) <= A10)) ? (&PCMSK0) : ((uint8_t *)0))
#define digitalPinToPCMSKbit(p) ( ((p) >= 8 && (p) <= 11) ? (p) - 4 : ((p) == 14 ? 3 : ((p) == 15 ? 1 : ((p) == 16 ? 2 : ((p) == 17 ? 0 : (p - A8 + 4))))))

//	__AVR_ATmega32U4__ has an unusual mapping of pins to channels
extern const uint8_t PROGMEM analog_pin_to_channel_PGM[];
#define analogPinToChannel(P)  ( pgm_read_byte( analog_pin_to_channel_PGM + (P) ) )

#define digitalPinHasPWM(p)         ((p) == 3 || (p) == 5 || (p) == 6 || (p) == 9 || (p) == 10 || (p) == 11 || (p) == 13)

#define digitalPinToInterrupt(p) ((p) == 0 ? 2 : ((p) == 1 ? 3 : ((p) == 2 ? 1 : ((p) == 3 ? 0 : ((p) == 7 ? 4 : NOT_AN_INTERRUPT)))))

#ifdef ARDUINO_MAIN

// On the Arduino board, digital pins are also used
// for the analog output (software PWM).  Analog input
// pins are a separate set.
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

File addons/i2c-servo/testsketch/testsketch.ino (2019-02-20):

#include <Wire.h>

void setup() {
  Wire.begin(); // join i2c bus (address optional for master)
  
  Wire.beginTransmission(0x11);
  Wire.write(0x00);
  Wire.write(92);
  Wire.endTransmission();    // stop transmitting

  delay(1000);  
}

byte x = 62;
byte y = 125;

void loop() {
  Wire.beginTransmission(0x11);
  Wire.write(0x00);
  Wire.write(x);    // 92 = 1.5ms
  Wire.endTransmission();    // stop transmitting

  Wire.beginTransmission(0x11);
  Wire.write(0x01);
  Wire.write(y);    // 92 = 1.5ms
  Wire.endTransmission();    // stop transmitting

  x++;
  if(x>125) x=62;
  
  y--;
  if(y<62) y=125;
  
  delay(50);
}

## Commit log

2017-09-22 First arduino IDE integration
2017-09-25 Added windows driver
2017-09-28 Added dimensions of V1.1 board
2017-09-28 Fix I2C connector position
2017-10-10 Arduinofied file names
2017-10-12 Photo of early prototype pcb
2017-10-15 i2c oled display addon
    [oled_bottom.fcstd, oled_bottom.stl, oled_top.fcstd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]
2017-10-18 Pwm example
2017-10-23 Don't touch disabled TX/RX led pin direction
2017-10-25 Add led blink demo
2017-11-02 TinyBasicPlus constants for motor and output modes
2017-11-09 Added PwmSpeed demo
2017-11-13 Added i2c scanner example
2017-11-13 Added i2c master/slave demo
2017-11-14 Added python demo client for I2cSlave
2017-11-28 Fixed voltage measurement
2017-12-19 Added case stl files
    [bottom.stl, top.stl]
2017-12-19 Fix open surface
    [bottom.stl]
2017-12-19 More design files
    [bottom.stl, bottom_with_bottom_mounts.stl, reset_button.stl]
2018-01-12 I2C expander and level shifter
    [bottom.fcstd, bottom.stl, i2c-expander.brd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]
2018-01-20 Encoder motor support
2018-01-22 ftduino_direct.ino v1.1
    ..added encoder motor commands...
2018-01-22 Motor brake demo
2018-02-15 Removed broken case design, added i2c protector
    [bottom_with_bottom_mounts.stl, i2c_protector.stl]
2018-02-17 Additional top cases
    [isp_cap.stl, top_with_isp.stl, top_without_isp.stl]
2018-02-21 Add some images of the case parts
2018-03-14 Board installation instructions
2018-03-19 Edge connector part
    [edge.fcstd, edge.stl]
2018-03-22 ft case for vl52l0x tof sensor
    [bottom.fcstd, bottom.stl, top.fcstd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]
2018-03-23 Added section about the i2c expander
2018-03-26 Case renderings
2018-03-28 Final case
2018-03-28 New case foto
2018-04-05 First work on full freatured i2c slave
2018-04-05 Read inputs via i2c
2018-04-06 Small counter fix and updated i2c client
2018-04-06 Added ultrasonic example
2018-04-09 Extended i2c slave
2018-04-27 Hardware pwm music example
2018-05-06 I2C master with multiple clients example
2018-05-08 Multi i2c setup
2018-05-11 Temperature example
2018-05-16 Stepper motor example
2018-05-17 Cleanup stepper motor example
2018-05-17 Stepper motor chapter
2018-05-17 Irq driven stepper example
2018-05-21 Add setpper motor server
2018-05-23 Fixed ultrasonic bit rate calculation
2018-05-24 Release with WebUSB and Ultrasonic fix
2018-05-24 LED buttons
2018-05-29 Increase ultrasonic baudrate precision
2018-06-05 Simple servo demo
2018-06-06 Servo example
2018-06-06 Servo wiring update
2018-06-06 Updated servo photo
2018-06-08 Further work on the servo connection
2018-06-13 Relaase incl servo example
2018-07-04 Case for i2c level shifter
    [bottom.fcstd, bottom.stl, top.fcstd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]
2018-07-23 Added ultrasonic demo
2018-07-25 Direct links to STL files
2018-08-12 Pimped webusb landing page
2018-08-29 Added schematic and board
2018-09-19 Redirect to ftduino.de
2018-09-28 Motor support for S4A
2018-11-08 Fix I2cSlave
2018-12-20 update to ftduino_direct v1.2 -> I2C pwm/servo shield support Signed-off-by: PeterDHabermehl <peter.habermehl@gmx.de>
2018-12-20 Update to ftduino_direct v1.2.1 - added "pwm_halt" command to shut off all pwm ports at once. Signed-off-by: PeterDHabermehl <peter.habermehl@gmx.de>
2019-01-11 Updated ftduino_direct binary to v1.3.2 Signed-off-by: PeterDHabermehl <peter.habermehl@gmx.de>
2019-01-14 Power supply suggestions and warnings
2019-01-17 Power supply links
2019-02-20 Servo controller cases
    [bottom30.fcstd, bottom30.stl, bottom45.fcstd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]
2019-02-21 Added mini servo adapter to manual
2019-03-18 Preserve start and stop button listeners
2019-03-31 plotter option mini servo controller
2019-04-02 Lidar demo for OLED ftDuino
2019-04-09 Tool to change mini servo adapter address
2019-04-09 Updated mini servo chapter
2019-04-09 Link to servo adapter
2019-09-11 Mini-Servo-Adapter schematic, pcb and firmware
    [i2c-servo.brd, i2c-servo.sch]
2019-11-06 Define tmp file to make it work with arduino-cli
    Arduino-cli expects the value `recipe.output.tmp_file` to be set.
2020-07-10 Add Ftduino M1 control to ArduinoBlue example
2020-07-13 Update ArduinoBlue examples
2020-08-29 ftDuinoBlue landing page
2020-09-15 Add i2c servo board design
2020-09-15 Added ArduinoBlue
2020-10-12 Add schematic for uno setup
2020-10-12 Create readme.md
    Just a hint to use the ...45 case parts for the commercially available boards.
2021-01-10 Make ultrasonic and WebUSB configurable. Prepare new output driver
2021-01-17 Output driver auto detection
2021-01-28 Make EC control a two wheel robot
2021-02-04 Option for drv8908 output driver
2022-07-06 Fix button handling on touch devices
2022-07-07 Explain filter problem
2022-09-16 Complain if yet unsupported output drivers are selected
2022-10-07 Add output driver chip detect sketch
2022-10-12 Full driver support for FtduinoSimple
2022-10-21 Increase SPI speed to 4Mhz with DRV8908
